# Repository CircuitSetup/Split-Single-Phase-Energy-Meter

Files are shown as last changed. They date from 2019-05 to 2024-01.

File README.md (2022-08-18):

# CircuitSetup Split Single Phase Energy Meter

The CircuitSetup ATM90E32 Split Single Phase Energy Meter can monitor the energy usage in your entire home in real time. It can easily be hooked up to an ESP8266 or ESP32 to wirelessly transmit energy usage data into a program like EmonCMS or ESPHome/Home Assistant. It can also be used to monitor solar power generation to keep track of how much power you are making.

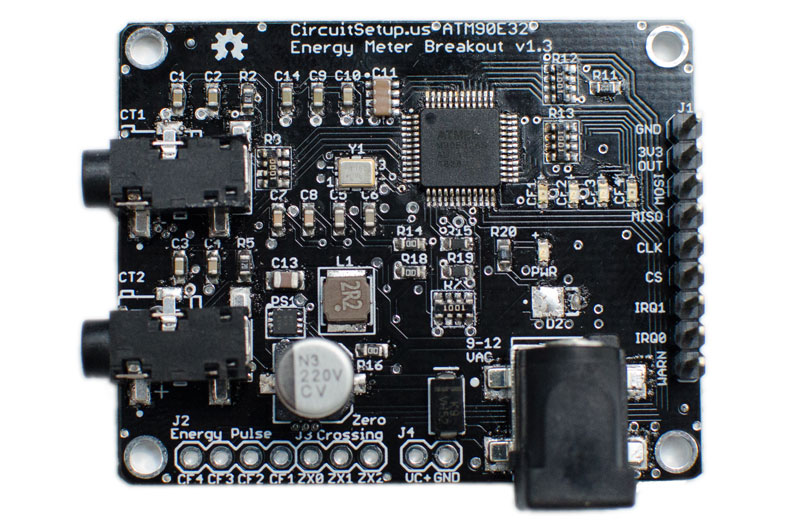
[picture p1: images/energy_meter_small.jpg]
CitcuitSetup Split Single Phase Energy Meter


#### With the Split Single Phase Energy Meter you can:

*   **Save Money!**
    *   See exactly how much money you're spending on energy in real time
    *   Find appliances that are using too much electricity
    *   Calculate energy usage for a single room to divide an energy bill fairly among roommates
*   **View & Gather Energy Data**
    *   View the energy usage of your entire home
    *   Track solar power generation (two units required)
    *   Calculate how much it costs to charge your electric vehicle
    *   Remote energy monitoring for vacation or rental properties
    *   Review and graph historical energy data
*   **Be Informed!**
    *   Independent of your power utility's meter
    *   Set up alerts for over or under usage
    *   Prevent surprises on energy bills
    *   View usage data in the EmonCMS Android or iOS apps
    *   Automate notifications with your home automation system like "send my phone a message when the dryer is done", or even "if I leave the house, and the oven is on, send me an alert" (programming required)
*   **Spend less on energy monitoring hardware!**
    *   Affordable but very accurate
    *   Save hundreds over popular monitoring systems

The Energy Meter kit available on CrowdSupply:
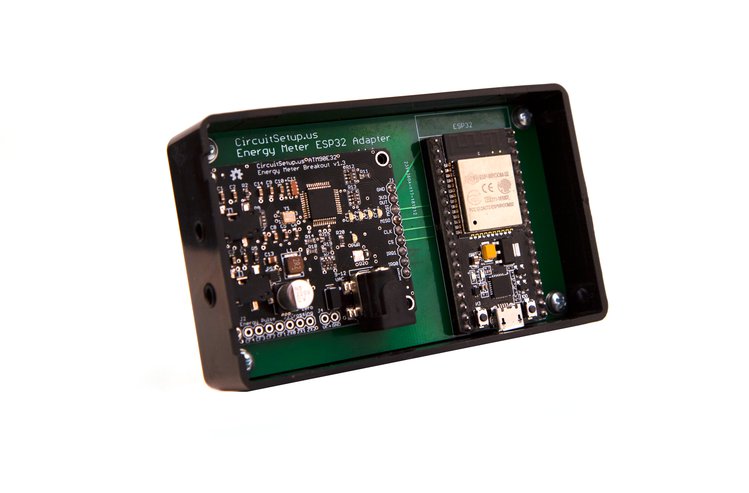
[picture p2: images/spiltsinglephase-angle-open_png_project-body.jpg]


## Contents

<!-- toc -->
- [Features](#features)
- [Software Setup](#software-setup)
- [Hardware Setup](#hardware-setup)
- [Calibration](#calibration)
- [Troubleshooting](#troubleshooting)
<!-- tocstop -->

## Features:

* **IC: MicroChip ATM90E32**
* **Connectivity**
     * SPI Interface to connect to any Arduino compatible MCU
     * Two IRQ interrupts, and one Warning output
     * Energy pulse output (pulses correspond to four LEDs)
     * Zero crossing output
* **Real Time Data Sampling**
     * Two current channels - up to 200A per channel
     * One voltage channel (expandable to two)
     * Measurement Error: 1%
     * Dynamic Range: 6000:1
     * Gain Selection: Up to 4x
     * Voltage Reference Drift Typical (ppm/°C): 6
     * ADC Resolution (bits): 16
* **Calculates**
     * Active Power
     * Reactive Power
     * Apparent Power
     * Power Factor
     * Frequency
     * Temperature
* **Other Features**
     * Can use more than one at a time to measure as many circuits as you want, including solar power generation
     * Uses standard current transformer clamps to sample current
     * Includes built-in 500mA 3v3 buck converter to power MCU board 
     * Compact size at only 40 mm x 50 mm

## What you'll need:

* Current Transformers for wire:
   * **13mm and less**, the [SCT-013-000 100A/50mA](https://circuitsetup.us/index.php/product/100a-50ma-current-transformer-yhdc-sct-013/) has a 13mm opening for wire.
   * **13.5mm - 16mm - 4/0 AWG** (usually aluminum, 200A service) not thicker than 16mm with insulation, we recommend the [YHDC SCT-016 120A/40mA](https://circuitsetup.us/index.php/product/120a-40ma-current-transformer-yhdc-sct-016-with-3-5mm-jack-16mm-opening/). The ones available on CircuitSetup.us, and included with the energy meter kit have 3.5mm plugs. 
   
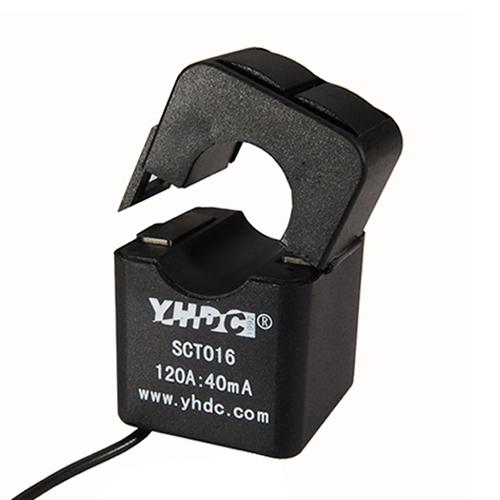
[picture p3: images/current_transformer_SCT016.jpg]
SCT016
   
   
   * **Greater than 16mm**, the [Magnelab SCT-0750-100](https://amzn.to/2IF8xnY) (must sever burden resistor connection on the back of the board since they have a built in burden resistor). These have wire leads and will need an adapter or screw connectors soldered to the energy meter board.
   
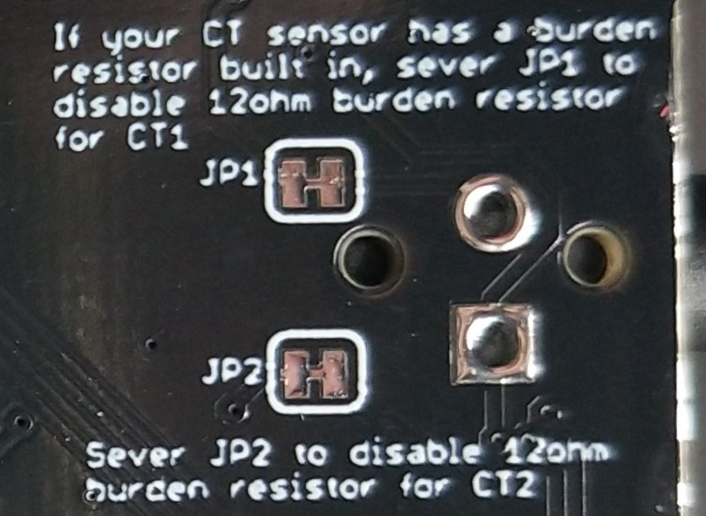
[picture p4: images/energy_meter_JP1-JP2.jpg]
JP1-JP2
   
   
   * Other CTs can also be used as long as they're rated for the amount of power that you are wanting to measure and have a current output no more than 720mA. For safety, they MUST have a built in Zener diode or burden resistor. 
* AC Transformer: [Jameco Reliapro 9v](https://amzn.to/2XcWJjI)
* An [ESP32](https://amzn.to/2pCtTtz), ESP8266, LoRa, or anything else that has an SPI interface.
* Jumper wires with Dupont connectors, or perf board to connect the two boards. The energy meter kit comes with a PCB adapter for an ESP32.
* The software located here to load onto your controller
* [EmonCMS](https://emoncms.org/site/home), ThingSpeak, InfluxDB/Grafana, or similar

## Software Setup

If you purchased an energy meter kit EmonESP is pre-loaded onto the included ESP32. You can skip this section and go to [Setting up EmonCMS](#setting-up-emoncms)

1.  Clone this repository in GitHub desktop or [download all the files and extract them to a folder](https://github.com/CircuitSetup/Split-Single-Phase-Energy-Meter/archive/master.zip)
2.  Place the ATM90E32 folder in your Arduino libraries folder. This is usually under Documents > Arduino > libraries
3.  We highly recommend using [EmonCMS.](https://emoncms.org/site/home) - EmonESP helps to connect and send data directly to EmonCMS
4.  Open **EmonESP > src > src.ino** - you will see several files open, but you'll only need to worry about src.ino
5.  Make sure the **CS_pin** is set to the pin that you are using on your controller board - the defaults are listed in src.ino and in the [hardware section here.](#hardware-setup)
6.  Upload the src.ino to your ESP (If you get any errors at this point, like a missing library, check the [Troubleshooting section on the EmonESP readme.](Software/EmonESP#troubleshooting-upload))
   If you are using an ESP32, [make sure you are using the latest software from the Espressif repository.](https://github.com/espressif/arduino-esp32)
7.  Upload files to the ESP in the data directory via SPIFFS - [see details on how to do this here](https://github.com/CircuitSetup/Split-Single-Phase-Energy-Meter/tree/master/Software/EmonESP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)
8.  Follow the directions to configure the Access Point in the [EmonESP directions](/Software/EmonESP#first-setup)

### Setting up EmonCMS 

EmonCMS

There are a few options for doing this:
- You can use the [EmonCMS.org service](https://emoncms.org/site/home), which costs roughly $15 a year with the data that we send from the energy meter (you don't _have_ to send all of the data)
- [Install on a computer within your network](https://github.com/emoncms/emoncms). To do this, you will need to have [apache/php/mysql installed](https://www.znetlive.com/blog/how-to-install-apache-php-and-mysql-on-windows-10-machine/)) [This can also be done with a Raspberry Pi.](https://github.com/emoncms/emoncms/blob/master/docs/RaspberryPi/readme.md)
- [Install on a remote web server](https://github.com/emoncms/emoncms). There are some very cheap ways this can be done if you're familiar with setting up web applications.

If you install EmonCMS on a remote web server, or if your home network has a public facing port, this will make it possible to see data on the EmonCMS app ([Android](https://play.google.com/store/apps/details?id=org.emoncms.myapps) or [iOS](https://itunes.apple.com/us/app/emoncms/id1169483587?ls=1&mt=8)) when your phone is outside of your network.

For all but the EmonCMS.org service, (currently for EmonCMS.org these feeds and inputs have to be setup manually) you can automatically setup the energy meter device in EmonCMS:
1. [Install the device plugin](https://github.com/emoncms/device) - this is now included in the default configuration
2. [Upload this file to the Modules > device > data > CircuitSetup folder.](/Software/EmonCMS/circuitsetup_split-phase.json)
3. Once the folder is created and json file is uploaded, go to Setup (top left) > Device Setup > New Device (lower right)
4. Click on CircuitSetup in the left menu
   You will see this: 
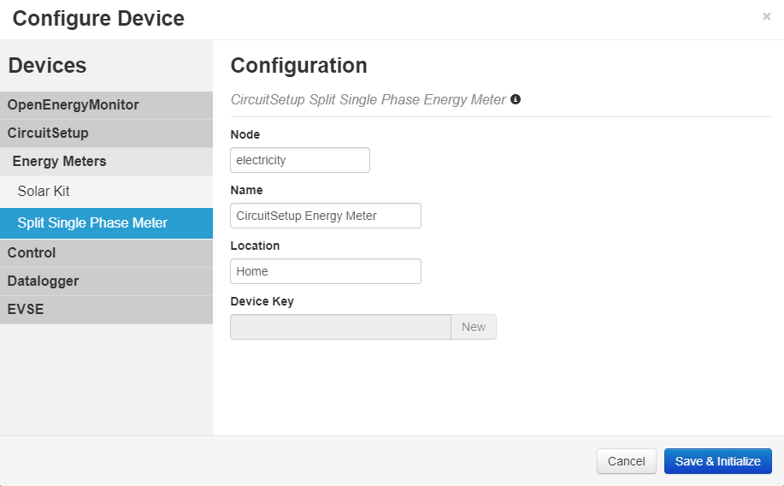
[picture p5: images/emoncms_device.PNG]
EmonCMS Device
   
5. Fill in the Name and Location and click save. 
6. You will then see the fields and inputs - click Initialize:
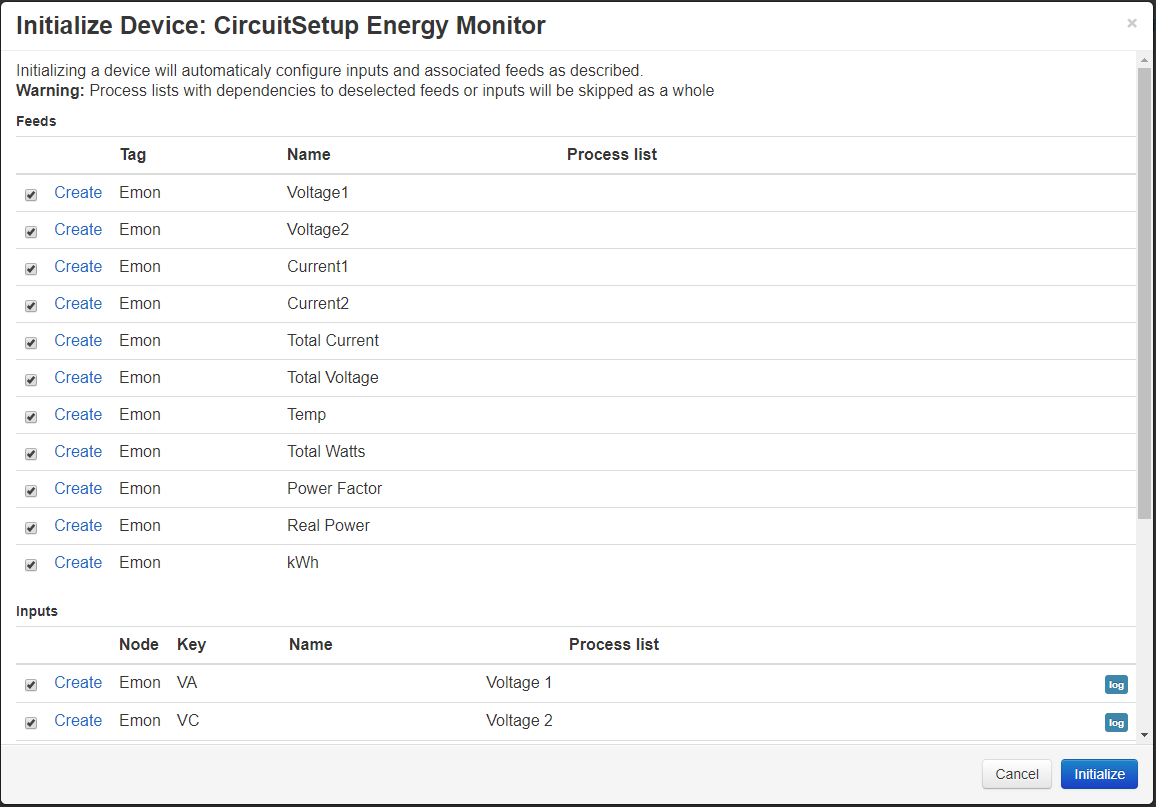
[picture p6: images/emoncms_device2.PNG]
EmonCMS Device2
   
7. You should now see this under Feeds:
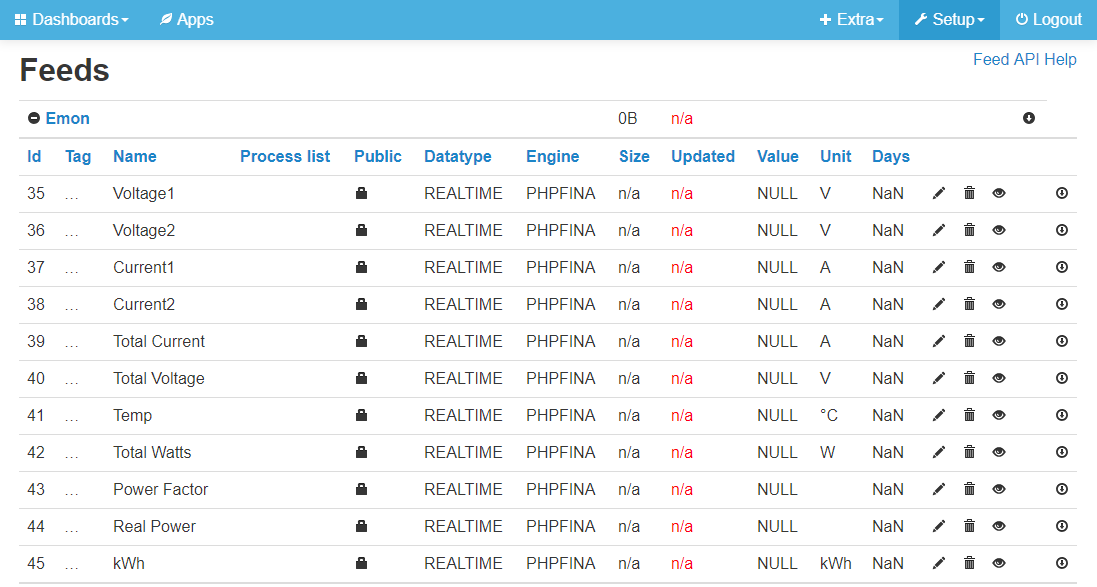
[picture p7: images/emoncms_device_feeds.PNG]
EmonCMS Feeds
   
8. And this under Inputs:
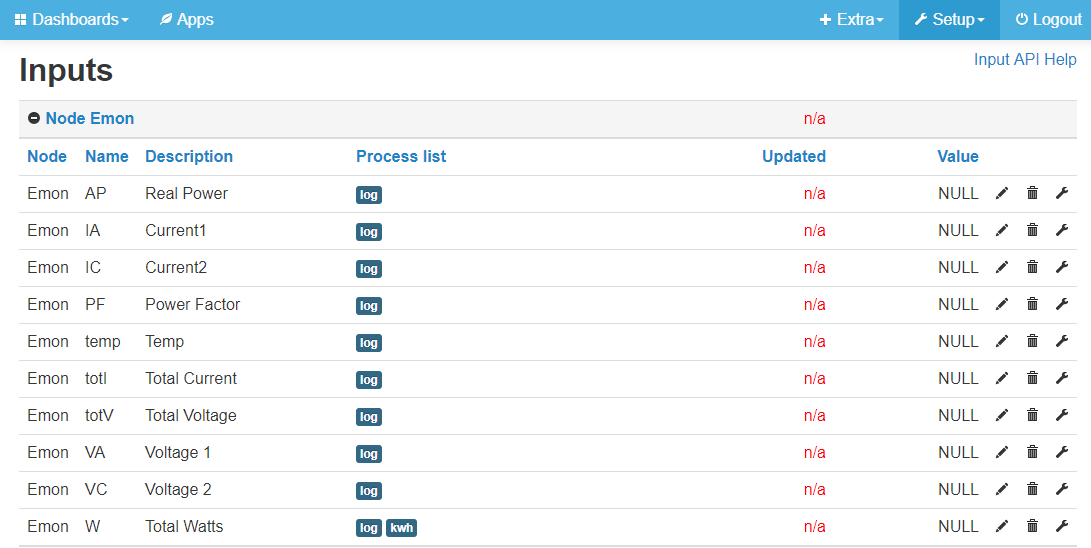
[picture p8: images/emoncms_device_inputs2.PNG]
EmonCMS Inputs
   

### Other software options
If you would like to use something other than EmonCMS, you can do that too! Make sure the ATM90E32 library is included in the sketch. See the [examples folder](https://github.com/CircuitSetup/Split-Single-Phase-Energy-Meter/tree/master/Software/examples) for examples of how things could be done using JSON or MQTT. Users have already setup feeds to Home Assistant, Influxdb, and Graphina. 

ESPHome

Support for this energy meter, and the ATM90E32 is now included in [ESPHome.](https://esphome.io/components/sensor/atm90e32.html)
[See here for more details](https://github.com/CircuitSetup/Expandable-6-Channel-ESP32-Energy-Meter#esphomehome-assistant) on setting up the meter with ESPHome. [Example configurations are located here.](https://github.com/CircuitSetup/Split-Single-Phase-Energy-Meter/tree/master/Software/examples)

## Hardware Setup
If you purchased an energy meter kit you can skip this section and go to [Installing the Energy Meter](#installing-the-energy-meter)

### Connect your controller to the energy meter
Connect the pins on the Energy Monitor to your MCU. If you have the adapter board, everything should already be connected properly. The following are the default for each, but they can be changed in software if you are using these pins for something else. 

For the ESP32:
*   5 - CS
*   18 - CLK
*   19 - MISO
*   23 - MOSI

For the ESP8266:
*   D8/16 - CS
*   D5/14 - CLK
*   D6/12 - MISO
*   D7/13 - MOSI

Don't forget to hook up the 3V3 and GND pins! 

**The energy meter can supply up to 500mA of 3.3v power to your controller**, so no other external power source should be needed. Some ESP32 dev boards may use more than 500mA when trying to initially connect to WiFi. If this is the case, you may not be able to connect to WiFi. If this happens, we recommend using another power source for the ESP32 - either a 5v DC adapter or a USB phone charger that outputs at least 500mA. It is **not** recommended to leave USB power plugged into an ESP at the same time as the energy meter's power 3V3 output. This can damage components. 

Other pins on your controller can be connected to the WARN and IRQ outputs, but they are not yet implemented in the default software. 

### Using more than one meter
More than one meter can be hooked up to a single MCU to monitor a solar grid, for example. 

To do this:
- Connect all CLK, MISO, and MOSI pins together
- Connect the GND and 3V3 from one meter to the MCU
- Connect the CS pin of one energy meter to an open GPIO on your MCU, and the CS pin on the second energy meter to another open GPIO on your MCU. These pins must be set in the software. See the [examples folder](/Software/examples) for the example with more than one energy meter.
- If you would like to monitor voltage from two sources, you will need two AC transformers. If only one voltage, you can split the output of 1 AC transformer using a 2.5mm DC jack Y-cable.

You can also [purchase a solar adapter here](https://circuitsetup.us/index.php/product/energy-meter-solar-esp32-adapter-2x-split-phase-meter-headers-space-for-spi-oled-screen/).

## Installing the Energy Meter
### Warning
To install the current transformers to measure current, your breaker panel must be opened to clamp them around your mains wires.
**High voltage AC power is VERY dangerous! If you are not comfortable working around AC voltage, we strongly encourage you to hire a qualified electrician.**

### **Disclaimer**
**The Split-Single Phase Energy Meter should be installed by a qualified professional, and in compliance with all local electrical codes that apply. CircuitSetup, and its parent company Sugarman Studios, LLC, cannot be held liable for damages or injury incurred by incorrectly installing the Split-Single Phase Energy Meter.**

The Split Single Phase Kit:
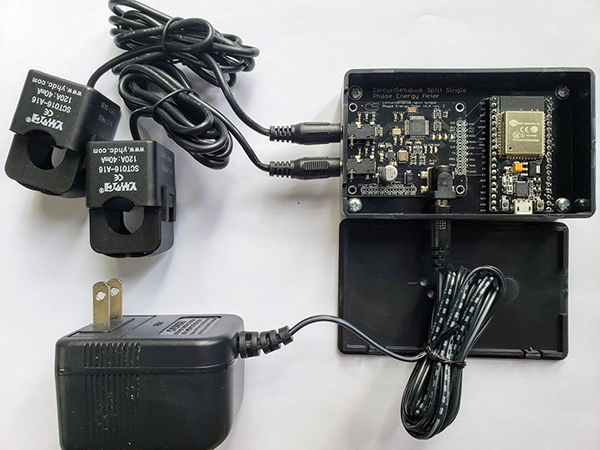
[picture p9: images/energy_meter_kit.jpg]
Energy Meter Kit


1. Decide where to mount the energy meter. We recommend installing the box outside of your panel for a better WiFi signal.  **The current transformer wires will need to be passed through a grommet in the side of the panel** It is against NEC code (US) to not route wires going in or out of an electrical panel through a grommet. 
2. The AC Transformer should be plugged into an outlet close to the panel. If you do not have one close, it is recommended that you have one installed by a licensed electrician. It isn't absolutely necessarty that the outlet is close to the panel, but it will give you more accurate readings. 

### Plug in the AC Transformer
Take note of the side of the split phase that the breaker for the AC transformer is on. This is important for connecting the CTs in the correct direction (see below section)
3. **If you wish to read the voltage from both sides of your panel** :
   - Hook up a second AC transformer to a single pole breaker, or a second outlet, that is wired to the opposite phase of the first AC transformer. If the breaker for the first outlet is on the left of your panel, you will need to wire the second AC transformer or outlet to a breaker on the right of the panel (single split phase breaker panels)
   - Sever jumper JP3 on the back of the energy meter **before hooking up the second AC transformer.** 
   - Solder 2 pin headers, or a female pigtail that matches your second AC transformer plug, to the left of the main AC power plug labeled GND and VC+. 
   - Hook up the second AC transformer to the “GND” (neutral) and “VC+” pins. **You want the wire that is intended to be neutral for the AC transformer to go on the GND terminal of the meter**. This wire usually has a white stripe on it. If the wires are swapped the 2 AC transformers will be in phase, and your current readings will output as negative.
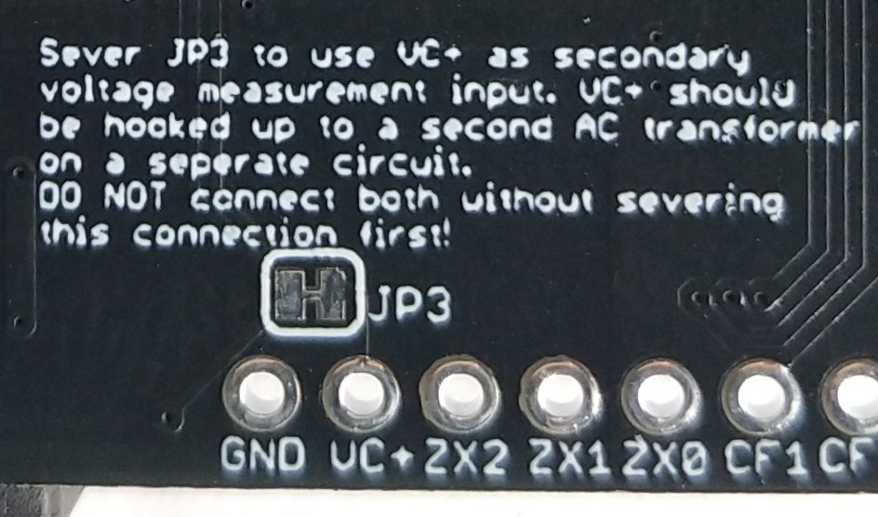
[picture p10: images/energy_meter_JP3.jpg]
JP3


### Connect Current Transformers to the energy meter
Before connecting the current transformers around your mains wires, plug them into the energy meter.

If your current transformers (CTs) have 3.5mm phono connectors, you hopefully have the version of the Energy Meter with these connections (v1.3+ has footprints for both). If you have the screw connectors, the phono connectors will have to be cut off. There should only be two wires regardless. For the screw connector version, be careful to connect the positive to the correct terminal. If these are reversed, things will not be damaged, but the reading will read negative.

If your current transformers have a built-in burden resistor, sever the jumpers on the back of the board to disable the 12ohm burden resistors. Alternatively, if you are reading smaller loads and would like more accurate readings, you can insert your own higher value burden resister across the positive and negative screw terminals.

If you purchased an energy meter kit with the black SCT016 current transformers, or have the blue SCT-013-000, these do not have a built-in burden resistor, but have a TVS diode instead. 

### Connect Current Transformers to your mains
1. Note the direction of the arrows on the top of the current transformers. 
   - If you are measuring 1 voltage (the default configuration): 
      1. CT1 should be on the same side of the split phase as the breaker for the plug that the AC transformer is plugged into, and should point in the direction of the current flowing into your house.
      2. CT2 should point in the opposite direction as CT1. Note: If you are measuring a second voltage with the VC+ input this CT will go in the same direction as the first.
2. Clip the current transformers around the two large main wires, usually at the top of the breaker box. **DO NOT TOUCH BARE METAL ON THESE WIRES**. There is one current transformer for each phase. 
3. Make sure the current transformers are not in the way of anything else, and are snapped closed around the wires. **Do not force them shut – if they will not close you will need a larger current transformer**

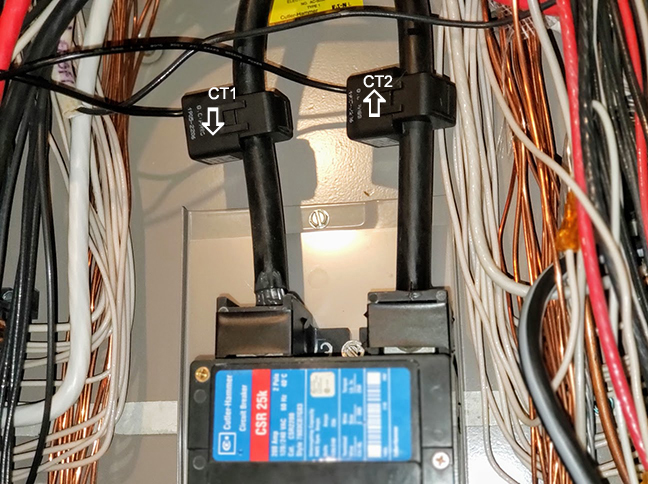
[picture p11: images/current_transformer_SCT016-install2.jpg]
SCT016 Install


### Solar Kit Setup ###
The solar kit comes with 2 meters, 4 current transformers, and optionally, 2 AC transformers.

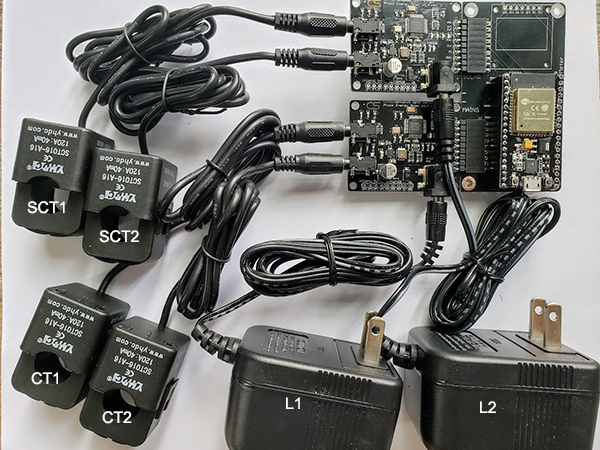
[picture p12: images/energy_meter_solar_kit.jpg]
Solar Kit


#### AC Transformers
**The 1st AC transformer**, L1, should be plugged into an outlet the same way as noted above in the "Plug in the AC Transformer" section

**The 2nd AC transformer**, L2, for the solar kit should be plugged into an outlet that is on the opposite phase than the first AC transformer. If you do not have an outlet, we recommend having a licensed electrician install one.

It is possible to power both energy meters with one AC transformer, you will just need a Y splitter. Close attention needs to be paid to the direction of the current transformers to properly measure the direction current is flowing.

#### Current Transformers
The mains current transformers (CT1, CT2) should be connected the same way as noted above starting with section "Connect Current Transformers to the energy meter"

Current transformers to measure solar energy generation (SCT1, SCT2) should be connected to the wires coming into your panel from your solar inverter. This is usually a dual pole breaker with 2 hot wires (in the US). The arrows on the CTs should be opposite eachother, like with the mains CTs. The wire that is connected to the side of the panel that is the same as the solar AC transformer will point towards the panel. It may take some trial an error to get this correct. 

Energy generated by solar, but not used by your house will register on the mains CTs as negative, since energy is flowing back to the grid. In EmonCMS this calculation is done automatically assuming you have set up the "Solar Kit" device.

## Calibration

If you purchased a kit that came with current transformers **and** an AC Transformer, you should not have to calibrate anything unless you want to. If you are providing your own AC Transformer, you will need to calibrate the voltage.

The default configuration of the Energy Meter software is set to use the SCT-016 120A/40mA current transformers, and the [Jameco Reliapro 9v AC transformer](https://amzn.to/2XcWJjI). There are also values for 100A Magnalab, SCT-013 100A 50mV current transformers, and the 12v version of the AC transformer located in the **energy_meter.h** file, and in the EmonESP web interface. Simply change the values under CALIBRATION SETTINGS if you are using a 12v AC Transformer or the Magnalab current transformers.  **If you are using any of these you likely will not need to calibrate, but if you want to be sure your readings are the most accurate then calibration is recommended.** 

Alternatively, if you have equipment that can read active and reactive energy pulse outputs, CT1-CT4 pins can be used for this. It is recommended that these connections are opto-isolated to prevent interference. 

### For calibration you will need:
1.  A multi-meter, or to make it easier and safer, a [kill-a-watt](https://amzn.to/2TXT7jx) or similar. A clamp meter will also work if you would like to measure mains power directly.
2.  A hair dryer, soldering iron, electric heater, or anything else that uses a large amount of resistive current.
3.  A modified power cable that allows you to put a current transformer around only the hot (usually black) wire.

### Setup
1.  At this point all wires should be connected between your ESP and the Energy Monitor.
2.  Connect the Energy Monitor to the AC Transformer and plug it in - the ESP and Energy Meter should both have power. If either do not, check your connections.

#### With the Arduino IDE
1.  Open the Arduino IDE
2.  Connect your ESP to your computer via USB cable
3.  Select the COM port under Tools > Port
4.  Go to Tools > Serial Monitor
5.  Values should be scrolling by. If you do not see anything in the serial window, make sure the correct COM port is selected for your ESP in the Arduino IDE.

#### With EmonESP
1.  The first time the ESP32 or ESP8266 is started with EmonESP, it will not be connected to a local router, and will go into SoftAP mode. You can connect to the interface via a cell phone or other wireless device to access the interface via a web browser at 192.168.4.1 or emonesp.local. For more details on this see [EmonESP WiFi Connection](/Software/EmonESP#1-wifi-connection)
2.  If the ESP is already connected to a network, you can access the interface with the IP address that your router assigned to it.
3.  Go to the Calibration section:

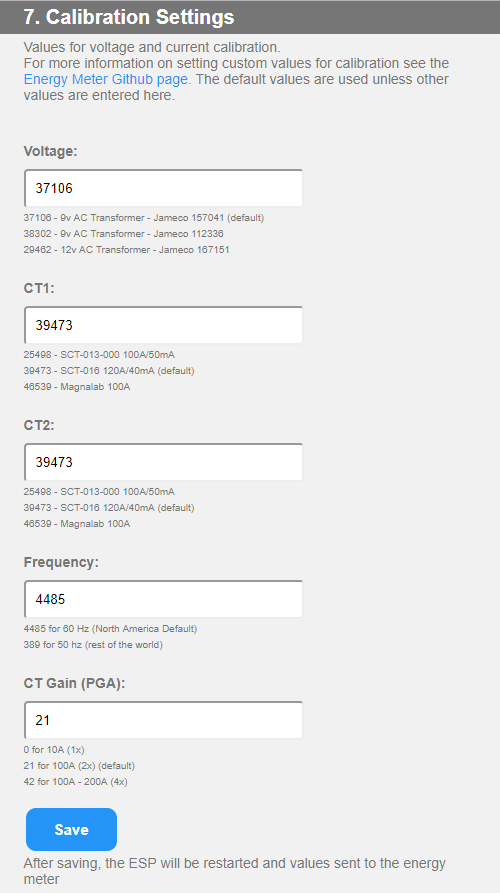
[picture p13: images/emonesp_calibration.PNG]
EmonESP Cal


### Voltage Procedure 

1.  In the Serial Monitor window or in EmonESP under 4. Latest Data, view the value for Voltage - take note of this (if you are getting a value above 65k, something is not hooked up or working correctly)
2.  Take a reading of the actual voltage from an outlet in your house.  For the Kill-a-watt, just plug it in, and select voltage. Compare the values.
3.  Adjust the value for VoltageGain in energy_meter.h or EmonESP by calculating:

<pre>New VoltageGain = (your voltage reading / energy monitor voltage reading) * VOLTAGE_GAIN</pre>

VOLTAGE_GAIN is the value currently set for the voltage gain parameter in energy_meter.h.

Test again after adjusting the value and re-uploading the sketch to your ESP. If it is still off, do the procedure again, but replace VOLTAGE_GAIN with the last value used. 

If you are not located in the US and have 50hz power, change the Frequency value to 389

### Current Procedure
For calibrating **CurrentGainCT1 & CurrentGainCT2**:

1.  In the Serial Monitor window or in EmonESP under 4. Latest Data, view the value for Current 
2.  If the value is negative, you are either exporting power (solar), or the current transformer is backwards.
3.  Compare what you are seeing for current from the Energy Monitor to the reading on the Kill-a-watt
4.  Adjust the value for CurrentGainCT1 or CurrentGainCT2 in energy_meter.h or EmonESP by calculating:

<pre>New CurrentGainCT1 or CurrentGainCT2 = (your current reading / energy monitor current reading) * CURRENT_GAIN_CT#</pre>

CURRENT_GAIN_CT# is the value currently set for the current gain parameter in energy_meter.h.

Test again after adjusting the value and re-uploading the sketch to your ESP. If it is still off, do this again, but replace the CURRENT_GAIN_CT# with the last value used. It is possible that the two identical current sensors will have different CurrentGain numbers due to variances in manufacturing, but it shouldn't be drastic. Note that the positioning of the CT sensor on the hot wire can influence the current reading. 

For more details, see the Calibration Procedure in the [Microchip Application notes.](http://ww1.microchip.com/downloads/en/AppNotes/Atmel-46103-SE-M90E32AS-ApplicationNote.pdf)

## Troubleshooting
### I'm not getting any data from the energy meter
If you have an energy meter kit:
- **Check that the ESP32 is seated properly.** Take it all the way out, then back in again to make sure. It should click into place. If you find you're only getting a signal when holding down the ESP32, you can try removing the black plastic around the base of the pins of the esp32, to push it down further. This is best accomplished with flush cutters. If you rather not do that, please contact us.
- If you're getting all 0 readings from the meter, try the steps above. If that does not work, please contact us.

If you do not have a kit:
- If you are getting all 65535 readings from the meter, then the connection from the ESP32 to the meter is not correct. Please check your wires.

### I'm getting a very low power factor reading, and wattage seems off
One of your CT clamps is probably backwards - flip it around. If they are both oriented in the same direction, this will not happen. 

### The ESP32 doesn't stay connected to WiFi
Make sure that the ESP32 has a good WiFi signal. The RSSI (viewable in the EmonESP web interface) should be, at the least, -70db.

For the CircuitSetup version of EmonESP:
- If the ESP32 loses the connection to the configured access point it will try 3 times over a 30 second period to reconnect. 
- If it cannot reconnect, it will go into SoftAP mode and broadcast a signal so it can be reconfigured via the web interface, if necessary. 
- If nothing happens after 5 minutes, it will try to reconnect to the configured access point again. 

### The ESP32 with CitcuitSetup EmonESP freezes and the blue LED does not blink
See the steps above for staying connected to WiFi. If that does not work, try one of the following:
1. Load [the latest firmware via the EmonESP web interface](https://github.com/CircuitSetup/Split-Single-Phase-Energy-Meter/releases). 
   - Download the latest .bin file from the link above
   - Open http://EmonESP_IP/upload (6. Firmware)
   - Click "Choose File", select the .bin file, then "Update Firmware"
   - The file will upload to the ESP32, and it will reset
   - After about 20 seconds the upload page will reload - you can return to the main page to verify everything is working properly
   
2. Close the browser window open to the EmonESP interface. There was a bug, that has since been corrected in v2.5.3, that would cause the ESP32 to freeze if a browser window was left open. It may also not close a browser session, which caused a memory leak, and eventual freeze.
3. Use an AC Transformer with a higher current output, like the [Jameco 112336](https://www.jameco.com/z/ADU090150A2231-AC-to-AC-Wall-Adapter-Transformer-9-Volt-1500mA-Black-Straight-2-5mm-Female-Plug_112336.html). The voltage calibration procedure will need to be done.
4. If the power being read is especially noisy, the energy meter IC and on-board low pass filters are pretty good at filtering, but sometimes this can cause the ESP32 to freeze. To remedy, bypass the on-board power supply:
   - If you have a hot air soldering gun:
      1. Remove the rectifier diode next to the power jack
      2. Use a USB style AC/DC adapter or phone charger to power the ESP32 via the micro-USB jack
      3. Use the AC transformer as you did previously
   - If you only have a regular soldering iron:
      1. Only the voltage 2 channel will be used in this method, so a modification to account for this in software will have to be done
      2. Solder a header on to "VC+" and "GND" next to the power jack
      3. Sever the JP3 connection on the back of the board
      4. Crimp or solder on a header that matches the one soldered onto the board in step 1 - **be careful to not reverse the polarity!**
      5. Use a USB style AC/DC adapter or phone charger to power the ESP32 via the micro-USB jack
      
### How do I change the network AP the ESP32 is connected to with EmonESP? 
1. Turn off the router that the ESP32 is configured on, and the meter/ESP32
2. Turn on the meter/ESP32
3. The ESP32 will go into soft AP mode after 30 seconds of not being able to connect to the configured AP. You can confirm this by checking the blue led. It will blink once every 2 seconds.
4. Connect to the ESP32 like you did when you first configured EmonESP. From there you can set it to connect to the new network AP.

### How do I reset the login/password to the EmonESP admin page?
To do this you'll have to reset EmonESP to default. This will erase any saved settings, like wifi configuration and connections.

1. Remove the ESP32 off of the pcb
2. Power the ESP32 via USB (If you want, open a serial window to see what it's outputting)
3. Connect Gnd (upper left) with GPIO3 (5th pin from upper left) with a jumper wire
4. Wait 15 seconds (10 minimum, but 15 to be sure). If you have a serial window open, it'll say "factory reset"
## Licenses
Hardware license: CERN v 1.2

Documentation license: CC BY 4.0

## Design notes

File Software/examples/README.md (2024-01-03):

## Examples ##
This example software was created by us and the community to use the CircuitSetup Split Single Phase Energy Meter in different applications.

### Sketches ###
- **ATM90E32_Basic_SPI** is a Basic Arduino sketch - this is a basic example that shows how to use the ATM90E32 library in Arduino. It simply outputs values to the serial window. The basis for this was created by [Tisham Dhar for his ATM90E26 Featherwing meter.](https://github.com/whatnick/ATM90E26_Arduino/tree/master/examples)
- **ATM90E32_MQTT** - an Arduino sketch using MQTT to send energy meter data via a Wemos D1. [Created by digiblur](https://github.com/digiblur/digiNRG_SplitPhase)
- **Home_Assistant_MQTT** - an Arduino sketch to send data to Home Assistant using MQTT. Includes the Home Assistant sensor file. Thanks to Richard Talley for supplying this.
- [**Raspberry Pi + MongoDB**](https://github.com/BitKnitting/FitHome/wiki/ElectricityMonitor) - Using a Raspberry Pi to communicate with the energy meter and send energy data to MongoDB
- [**MySQL to Home Assistant**](https://community.home-assistant.io/t/how-to-save-sensor-data-to-mysql-database/163094/6?u=circuitsetup) - Send data to a MySQL database via Arduino Ethernet, then read the database in Home Assistant. By Aaron Cake

### ATM90E32 Libraries ###
- **[CircuitPython](https://github.com/BitKnitting/CircuitSetup_CircuitPython)** - The ATM90E32 library converted to work with Adafruit's CircuitPython. Created by BitKnitting
- **[MicroPython](https://github.com/BitKnitting/CircuitSetup_micropython)** - The ATM90E32 library converted to work with MicroPython. Created by BitKnitting
- **[ESPHome](https://github.com/esphome/esphome/tree/dev)** - direct integration for ESPHome, which allows you to more easily import energy data directly into home automation systems like Home Assistant. Created by thompsa. [Some more details on setting up the meter with ESPHome](https://github.com/digiblur/digiNRG_ESPHome), by digiblur
  - **HA-ESPHome_energy_meter.yaml** - ESPHome setup config.  The default calibration values have been loaded (9V AC Transformer, 120A/40mA CTs) [Created by digiblur](https://github.com/digiblur/digiNRG_ESPHome)
  - **[ESPHome Documentation](https://esphome.io/components/sensor/atm90e32.html)** for the ATM90E32 sensor

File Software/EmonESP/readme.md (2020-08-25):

# EmonESP



ESP8266/ESP32 WIFI serial to emoncms link

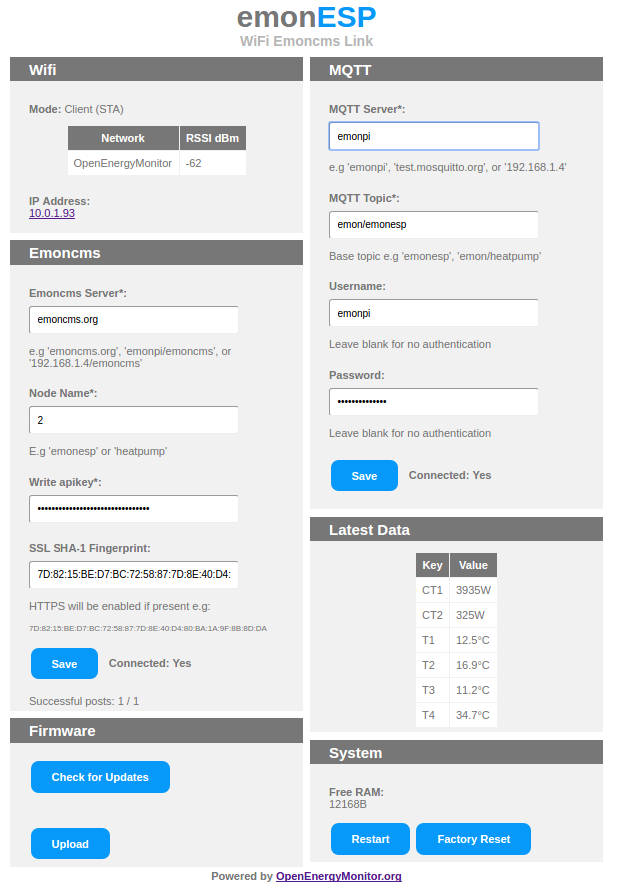
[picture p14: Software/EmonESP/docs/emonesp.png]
EmonEsp WiFi AP Setup Portal


## Contents

<!-- toc -->
- [EmonESP](#emonesp)
  * [Requirements](#requirements)
- [EmonESP User Guide](#emonesp-user-guide)
  * [First Setup](#first-setup)
    + [1. WiFi Connection](#1-wifi-connection)
  * [2. Emoncms](#2-emoncms)
  * [3. MQTT](#3-mqtt)
  * [5. Admin (Authentication)](#5-admin-authentication)
  * [7. System](#7-system)
  * [OTA Firmware Update](#ota-firmware-update)
  * [HTTP API Examples](#http-api-examples)
    + [View units status:](#view-units-status)
    + [4. Data Input](#4-data-input)
      - [UART Input](#uart-input)
      - [HTTP API](#http-api)
    + [Save Emoncms server details](#save-emoncms-server-details)
    + [Save Emoncms MQTT server details](#save-emoncms-mqtt-server-details)
  * [Installation](#installation)
    + [Option 1: Using PlatformIO](#option-1-using-platformio)
      - [1a. Install PlatformIO command line](#1a-install-platformio-command-line)
      - [1b. And / Or use PlatformIO IDE](#1b-and--or-use-platformio-ide)
      - [2. Clone this repo](#2-clone-this-repo)
      - [3. Compile](#3-compile)
      - [3. Upload](#3-upload)
        * [a.) Upload main program:](#a-upload-main-program)
        * [b.) Upload data folder to the file system (html, CSS etc.) (SPIFFS):](#b-upload-data-folder-to-the-file-system-html-css-etc-spiffs)
      - [Or upload all in one go](#or-upload-all-in-one-go)
        * [c.) OTA upload over local network](#c-ota-upload-over-local-network)
      - [4. Debugging ESP subsystems](#4-debugging-esp-subsystems)
    + [Option 2: Using Arduino IDE](#option-2-using-arduino-ide)
      - [1. Install ESP for Arduino IDE with Boards Manager](#1-install-esp-for-arduino-ide-with-boards-manager)
      - [2. Install ESP filesystem file uploader](#2-install-esp-filesystem-file-uploader)
      - [3. Clone this repo](#3-clone-this-repo)
      - [4. Compile and Upload](#4-compile-and-upload)
    + [Troubleshooting Upload](#troubleshooting-upload)
      - [Erase Flash](#erase-flash)
      - [Fully erase ESP-12E](#fully-erase-esp-12e)
    + [Development Forum Threads](#development-forum-threads)
    + [License](#license)

<!-- tocstop -->

# Requirements

- ESP-12E module with 4M Flash
OR
- ESP8266
OR
- ESP32

***

# User Guide

## First Setup

On first boot, the ESP should broadcast a WiFI AP `emonESP_XXX`. Open a browser and navigate to `http://192.168.4.1`

*Note: You may need to disable mobile data if connecting via a Android 6 device*

### 1. WiFi Connection

- Select your WiFi network from list of available networks
- Enter WiFi PSK key then click `Connect`

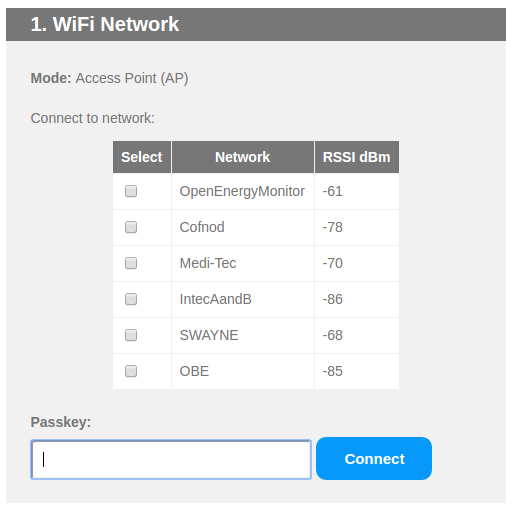
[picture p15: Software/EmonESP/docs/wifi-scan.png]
Wifi setup


- emonESP should now connect to local wifi network and return local IP address.
- Browse to local IP address by clicking the hyperlink (assuming your computer is on the same WiFi network)
On future boots EmonESP will automatically connect to this network.

*Note: on some networks it's possible to browse to the EmonESP using hostname [http://emonesp](http://emonesp) or on windows [http://emonesp.local](http://emonesp.local)*

**If re-connection fails (e.g. network cannot be found) the EmonESP will automatically revert back to WiFi AP mode after a short while to allow a new network to be re-configued if required. Re-connection to existing network will be attempted every 5min.**

*Holding the `boot` button at startup (for about 10's) will force AP mode. This is useful when trying to connect the unit to a new WiFi network.*

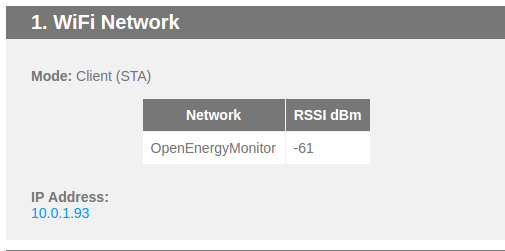
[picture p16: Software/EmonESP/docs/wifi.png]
Wifi setup


## 2. EmonCMS

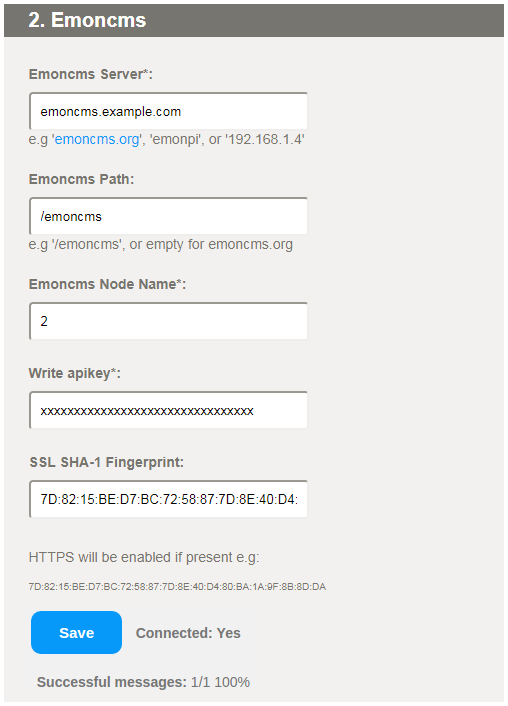
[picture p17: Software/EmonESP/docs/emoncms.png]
emoncms setup


EmonESP can post data to [emoncms.org](https://emoncms.org) or any other Emoncms server (e.g. emonPi) using [Emoncms API](https://emoncms.org/site/api#input).

Instructions on setting up [EmonCMS on a Raspberry Pi are located here.](https://github.com/openenergymonitor/EmonScripts/blob/master/install/rpi-install.md)

In the *Emoncms Server* field, enter just the hostname or address without any path (e.g. emoncms.org), in the *Emoncms Path* field enter the path including the leading slash (e.g. /emoncms) or leave it empty if not required.

Data can be posted using HTTP or HTTPS. For HTTPS the Emoncms server must support HTTPS (emoncms.org does, emonPi does not). Due to the limited resources on the ESP the SSL SHA-1 fingerprint for the Emoncms server certificate must be manually entered and regularly updated.

*Note: the emoncms.org fingerprint will change every 90 days when the SSL certificate is renewed.*

To obtain the certificate fingerprint, you can use several methods, some examples:
* Chrome under Windows: click the secure icon next to the address bar and click on the certificate row to get the details, in the *Details* tab copy the hexadecimal digits from the box *Thumbprint* substituting spaces with colons and paying attention not to include any leading invisible character;
* Firefox under Linux: click the secure icon next to the address bar, Show connection details, More information, in the security tab click *View Certificate* and copy the *SHA1 Fingerprint*
* openssl under Linux: issue the following command substituting your host in place of www.example.com:

`echo | openssl s_client -connect www.example.com:443 -servername www.example.com |& openssl x509 -fingerprint -sha1 -noout`

## 3. MQTT

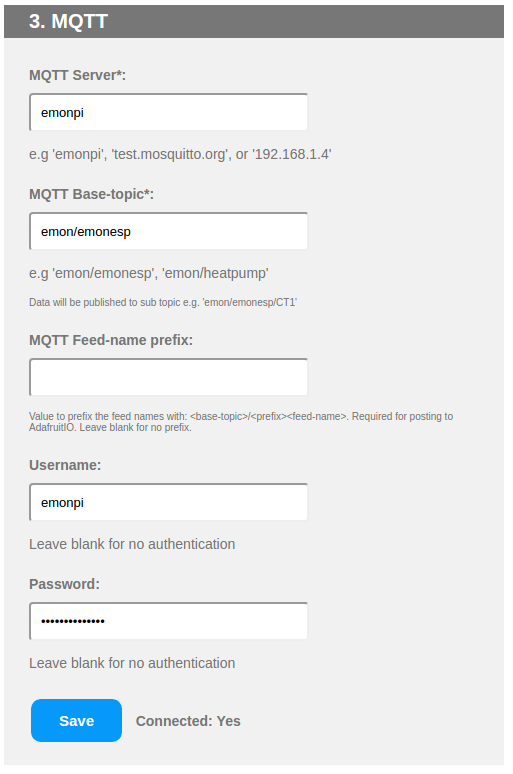
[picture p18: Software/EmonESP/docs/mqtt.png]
mqtt setup


EmonESP can post data to an MQTT server. Each data key:pair value will be published to a sub-topic of base topic.E.g data `CT1:346` will results in `346` being published to `<base-topic>/CT1`

- Enter MQTT server host and base-topic
- (Optional) Enter server authentication details if required
- Click connect
- After a few seconds `Connected: No` should change to `Connected: Yes` if connection is successful. Re-connection will be attempted every 10s.

*Note: `emon/xxxx` should be used as the base-topic if posting to emonPi MQTT server if you want the data to appear in emonPi Emoncms. See [emonPi MQTT docs](https://guide.openenergymonitor.org/technical/mqtt/).*

## 5. Admin (Authentication)

HTTP Authentication (highly recomended) can be enabled by saving admin config by default username and password

**HTTP authentication is required for all HTTP requests including input API**

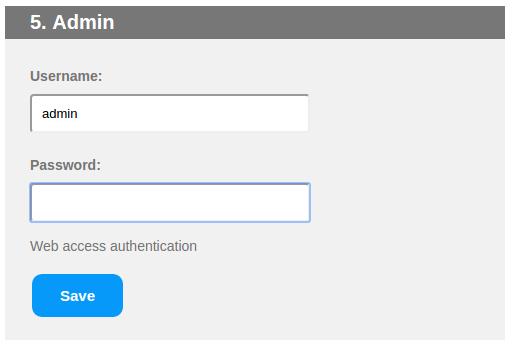
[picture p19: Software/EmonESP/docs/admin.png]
admin setup


## 7. System

Displays free system memory and firmware version

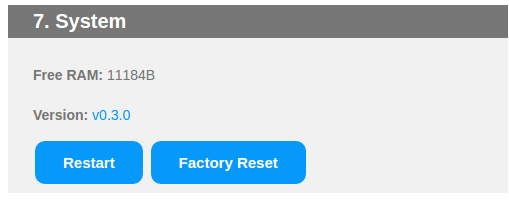
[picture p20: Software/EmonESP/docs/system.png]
system


## OTA Firmware Update

TBC

## HTTP API Examples

### View units status:

`http://<IP-ADDRESS>/status`

Example return in JSON:

```
{"mode":"STA","networks":[],"rssi":[],"ssid":"OpenEnergyMonitor","srssi":"-58","ipaddress":"10.0.1.93","emoncms_server":"emoncms.org","emoncms_node":"emonesp","emoncms_apikey":"xxxxxxxx","emoncms_connected":"0","packets_sent":"0","packets_success":"0","mqtt_server":"emonpi","mqtt_topic":"emonesp","mqtt_user":"emonpi","mqtt_pass":"xxxxxx","mqtt_connected":"0","free_heap":"25040"}
```

### 4. Data Input

Data can be inputed to EmonESP via serial UART or HTTP API.

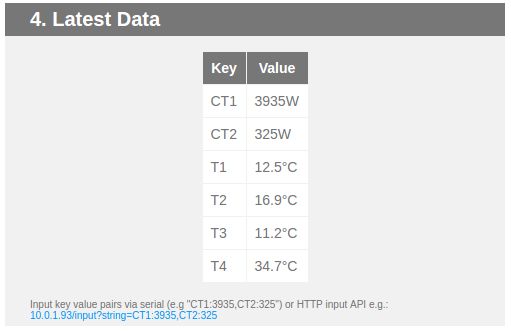
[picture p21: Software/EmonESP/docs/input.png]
input setup


#### UART Input

Data in serial:pairs string format can be inputed to EmonESP via serial UART **(115200 baud)** e.g:

`ct1:3935,ct2:325,t1:12.5,t2:16.9,t3:11.2,t4:34.7`

#### HTTP API

Data in string:pairs can be sent to EmonESP via HTTP API. This is useful to emulate the serial string data function while using the UART for code upload and debug. API example:

`http://<IP-ADDRESS>/input?string=ct1:3935,ct2:325,t1:12.5,t2:16.9,t3:11.2,t4:34.7`

### Save Emoncms server details

`http://<IP-ADDRESS>/saveemoncms?&server=emoncms.org&apikey=xxxxxxxxxxxxxxxxxx&node=emonesp&fingerprint=7D:82:15:BE:D7:BC:72:58:87:7D:8E:40:D4:80:BA:1A:9F:8B:8D:DA`

*SSL SHA-1 fingerprint is optional, HTTPS connection will be enabled if present*

### Save Emoncms MQTT server details

`http://<IP-ADDRESS>/savemqtt?&server=emonpi&topic=emonesp&user=emonpi&pass=emonpimqtt2016`

*MQTT user and pass are optional, leave blank for connection to un-authenticated MQTT servers*

***

## Installation 

EmonESP uses [ESP8266 Arduino core](https://github.com/esp8266/Arduino) or the [ESP32 Arduino core](https://github.com/espressif/arduino-esp32)

Firmware can be compiled and uploaded either using PlatfomIO ([see blog post](https://blog.openenergymonitor.org/2016/06/platformio/)) or Arduino IDE.

### Option 1: Using PlatformIO

For more detailed ESP8266 Arduino core specific PlatfomIO notes see: https://github.com/esp8266/Arduino#using-platformio

#### 1a. Install PlatformIO command line

The easiest way if running Linux is to install use the install script, this installed pio via python pip and installs pip if not present. See [PlatformIO installation docs](http://docs.platformio.org/en/latest/installation.html#installer-script). Or PlatformIO IDE can be used :

`$ sudo python -c "$(curl -fsSL https://raw.githubusercontent.com/platformio/platformio/master/scripts/get-platformio.py)"`

#### 1b. And / Or use PlatformIO IDE

Standalone built on GitHub Atom IDE, or use PlatformIO Atom IDE plug-in if you already have Atom installed. The IDE is nice, easy and self-explanitory.

[Download PlatfomIO IDE](http://platformio.org/platformio-ide)

#### 2. Clone this repo

`$ git clone https://github.com/CircuitSetup/Split-Single-Phase-Energy-Meter`

#### 3. Compile

```
$ cd Software/EmonESP
$ pio run
```

The first time platformIO is ran the espressif arduino tool chain and all the required libs will be installed if required.

#### 3. Upload

- Put ESP into bootloader mode
   - On Heatpump monitor use jumper to pull `GPIO0` low then reset then connect power (simulates reset) or pull RST pin low.
   - On other ESP boards (Adafruit HUZZAH) press and hold `GPIO0` button then press Reset, LED should light dimly to indicate bootloader mode

##### a.) Upload main program:

`$ pio run -t upload`

##### b.) Upload data folder to the file system (html, CSS etc.) (SPIFFS):

- Put ESP back into bootloder mode, see above

`$ pio run -t uploadfs`

See [PlatfomrIO docs regarding SPIFFS uploading](http://docs.platformio.org/en/latest/platforms/espressif.html#uploading-files-to-file-system-spiffs)

#### Or upload all in one go

This wil upload both the fimware and fs in a single command

Put ESP into bootloader mode

`esptool.py write_flash 0x10000 .pioenvs/emonesp/firmware.bin 0x290000 .pioenvs/emonesp/spiffs.bin`

##### c.) OTA upload over local network

`$  pio run  -t upload --upload-port <LOCAL-ESP-IP-ADDRESS>`

Upload SPIFFS filesystem over OTA (and don't flash):

` pio run -e emonesp_spiffs -t upload --upload-port <LOCAL-ESP-IP-ADDRESS>`

OTA uses port 8266. See [PlatformIO ESP OTA docs](http://docs.platformio.org/en/latest/platforms/espressif.html#over-the-air-ota-update):

#### 4. Debugging ESP subsystems

The ESP subsystems have a lot of logging that can be enabled via setting various build options.

Using Platform IO the easiest way to configure these is via the [PLATFORMIO_BUILD_FLAGS](http://docs.platformio.org/en/stable/envvars.html#envvar-PLATFORMIO_BUILD_FLAGS) environment variable.

First select the serial port to output debug;
```
-DDEBUG_ESP_PORT=Serial
-DDEBUG_ESP_PORT=Serial1
```

Then add one or more of the debug options;
```
-DDEBUG_ESP_CORE
-DDEBUG_ESP_WIFI
-DDEBUG_ESP_HTTP_CLIENT
-DDEBUG_ESP_HTTP_SERVER
-DDEBUG_ESP_HTTP_UPDATE
-DDEBUG_ESP_UPDATER
-DDEBUG_ESP_OTA
-DDEBUG_ESP_SSL
-DDEBUG_TLS_MEM
```

For example from the Windows Power shell you may do something like;
```
$env:PLATFORMIO_BUILD_FLAGS="-DDEBUG_ESP_PORT=Serial1 -DDEBUG_ESP_CORE -DDEBUG_ESP_WIFI"
pio run -t clean
pio run
pio run -t upload --upload-port 172.16.0.80
```
***

### Option 2: Using Arduino IDE

#### 1. Install ESP for Arduino IDE with Boards Manager

##### a. For ESP8266:

Install steps from: https://github.com/esp8266/Arduino

- Install Arduino IDE 1.6.8 from the Arduino website.
- Start Arduino and open Preferences window.
- At the bottom of this window find the field “Additional Board Manager URLs” and enter ‘http://arduino.esp8266.com/stable/package_esp8266com_index.json`. You can add multiple URLs, separating them with commas.
- Open `Tools > Board > Board Manager`, scroll down and click on esp8266 platform, select version then install
- Select `Tools > Board > Generic ESP8266 Module` (required for EmonESP)

##### b. For ESP32:

Install steps from: https://github.com/espressif/arduino-esp32/blob/master/docs/arduino-ide/boards_manager.md

- Install the current upstream Arduino IDE at the 1.8 level or later. The current version is at the [Arduino website](http://www.arduino.cc/en/main/software).
- Start Arduino and open Preferences window.
- Enter ```https://dl.espressif.com/dl/package_esp32_index.json``` into *Additional Board Manager URLs* field. You can add multiple URLs, separating them with commas.
- Open Boards Manager from Tools > Board menu and install *esp32* platform (and don't forget to select your ESP32 board from Tools > Board menu after installation).

Stable release link: `https://dl.espressif.com/dl/package_esp32_index.json`

Development release link: `https://dl.espressif.com/dl/package_esp32_dev_index.json`

#### 2. Install ESP filesystem file uploader

##### a. For ESP8266:

Required to include `data` folder with HTML etc in the upload

[Follow esp8266 filesystem instructions (copied  below):](https://github.com/esp8266/Arduino/blob/master/doc/filesystem.md)

- [Download the Arduino IDE plug-in (.zip)](https://github.com/esp8266/arduino-esp8266fs-plugin/releases/download/0.2.0/ESP8266FS-0.2.0.zip)
- Navigate to the `tools` folder in your Arduino sketchbook directory, (create directory if it doesn't exist)
- Create `tools > ESP8266FS` folder
- Unpack the plug-in into `ESP8266FS` directory (the path will look like `<home_dir>/Arduino/tools/ESP8266FS/tool/esp8266fs.jar`)
- Restart Arduino IDE

##### a. For ESP32:

You will need the latest release from this page: https://github.com/me-no-dev/arduino-esp32fs-plugin/releases

Then follow instructions from here: https://github.com/me-no-dev/arduino-esp32fs-plugin

- In your Arduino sketchbook directory, create tools directory if it doesn't exist yet.
- Unpack the tool into tools directory (the path will look like ```<home_dir>/Arduino/tools/ESP32FS/tool/esp32fs.jar```).
- Restart Arduino IDE. 

#### 3. Clone this repo

`$ git clone https://github.com/CircuitSetup/Split-Single-Phase-Energy-Meter`

#### 4. Compile and Upload

- Open Software/EmonESP/src/src.ino in the Arduino IDE.
- Connect the ESP to an open USB port on your computer
- Select the appropriate port and options under tools
- **Upload main sketch:** Compile and Upload as normal using Arduino IDE [CTRL + u] - for an ESP32, you may need to hold down the IO0 button when esptool.py initiates
- **Upload 'data' folder**: Upload data folder (home.html web page etc) using `tools > ESP32 Sketch Data Upload tool`

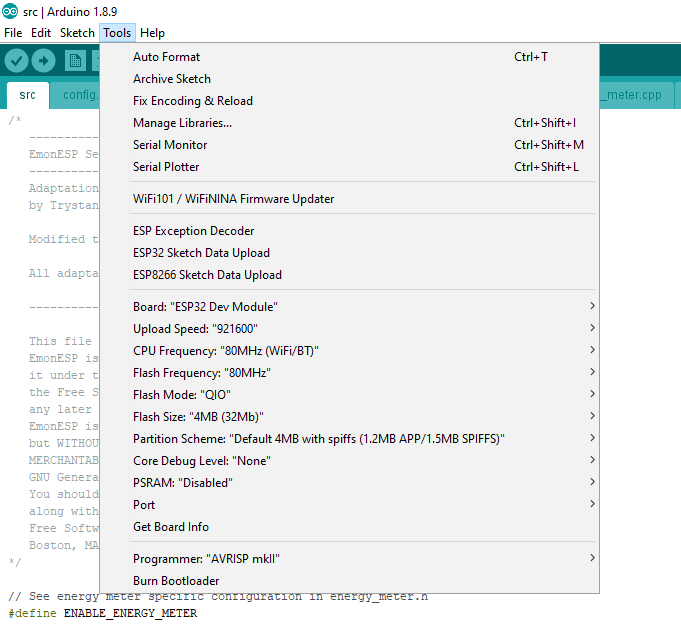
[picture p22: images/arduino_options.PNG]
arduino options


### Troubleshooting Upload

#### Library errors 

- If compiling fails because AsyncMqttClient.h library cannot be found. go to https://github.com/marvinroger/async-mqtt-client and copy the library to your Arduino/libraries folder
- For the ESP32, you will probably need these libraries (installed to Arduino/libraries):
    - https://github.com/me-no-dev/AsyncTCP
    - https://github.com/me-no-dev/ESPAsyncWebServer
- If you get an error for hash.h, put a folder under Arduino/libraries "Hash" and load it with these files: https://github.com/esp8266/Arduino/tree/master/libraries/Hash/src

#### Erase Flash

If you are experiencing ESP hanging in a reboot loop after upload it may be that the ESP flash has remnants of previous code (which may have the used the ESP memory in a different way). The ESP flash can be fully erased using [esptool](https://github.com/themadinventor/esptool). With the unit in bootloder mode run:

`$ esptool.py erase_flash`

*`sudo` maybe be required*

Output:

```
esptool.py v1.2-dev
Connecting...
Running Cesanta flasher stub...
Erasing flash (this may take a while)...
Erase took 8.0 seconds
```

#### Fully erase ESP-12E

To fully erase all memory locations on an ESP-12 (4Mb) we need to upload a blank file to each memory location

`esptool.py write_flash 0x000000 blank_1MB.bin 0x100000 blank_1MB.bin 0x200000 blank_1MB.bin 0x300000 blank_1MB.bin`

***

### Development Forum Threads

- https://community.openenergymonitor.org/t/emonesp-firmware-development/1191/43
- https://community.openenergymonitor.org/tags/emonesp

### License

GNU V3 General Public License

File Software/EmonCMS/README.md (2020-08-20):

The above .json files are now included in the [Device module for EmonCMS](https://github.com/emoncms/device)

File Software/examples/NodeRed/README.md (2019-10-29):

# EmonESP > MQTT > Node-Red > InfluxDB

This Node-Red flow takes MQTT data published from EmonESP (the default ESP32 program for the Split Single Phase Energy Meter), formats it, throttles it to get a sample every 10 seconds, then sends it to an InfluxDB database. 

### EmonESP Setup
- MQTT Server: Your MQTT broker address. If using Home Assistant with Mosquitto broker installed, this is the address of Home Assistant. The port defaults to 1883
- MQTT Base-topic: emon/emonesp
- MQTT Feed-name prefix: none
- Username: the username for your MQTT broker
- Password: the password for your MQTT broker

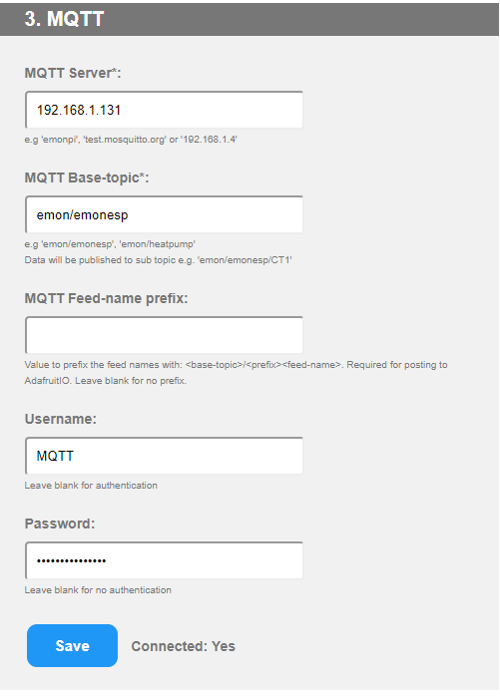
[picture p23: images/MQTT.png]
EmonESP MQTT


### InfluxDB Setup
- Go to InfluxDB Admin > Databases
- Create a new database called emoncms - set the retention policy to autogen and the duration to whatever you would like. 
- Go to Users
- Create a user named emoncms and set the permissions to all

### Node-Red Setup
- Go to Menu > Import
- Paste the contents of or select EmonESP-MQTT-NodeRed-InfluxDB.json to import
- The flow should be imported
- Double click on 'emonesp', and set the credentials for MQTT (broker)
- Click the pencil next to 'MQTT-local'. This should be the same as in the first step of EmonESP setup. Or, if you're using Home Assistant with Mosquitto, and Node-Red installed under Hass.io it can be 'localhost'. Don't forget to click on Security and set the login/password
- Double click on 'V1 to Influxdb'
- Click on the pencil next to 'emoncms' and set the credentials for the InfluxDB database. You shouldn't have to do this on all of the function nodes unless the name of the database is not 'emoncms'. 

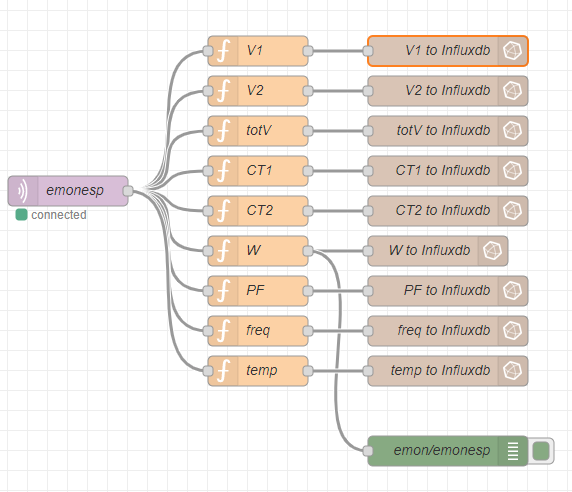
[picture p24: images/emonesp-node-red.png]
Node-Red Energy Meter Flow


From here make sure that data is being sent to InfluxDB by going to Explore, and emoncms.autogen. You should see a graph when clicking on this, the field name, then checking value.

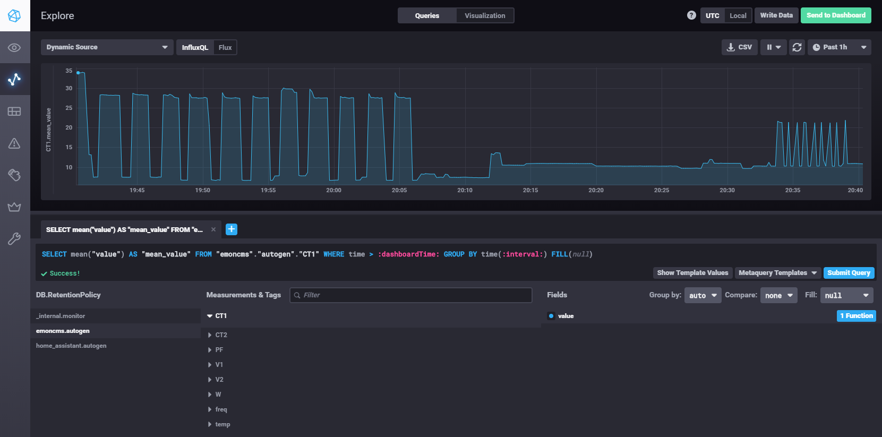
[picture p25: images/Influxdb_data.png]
InfluxDB EmonESP Data


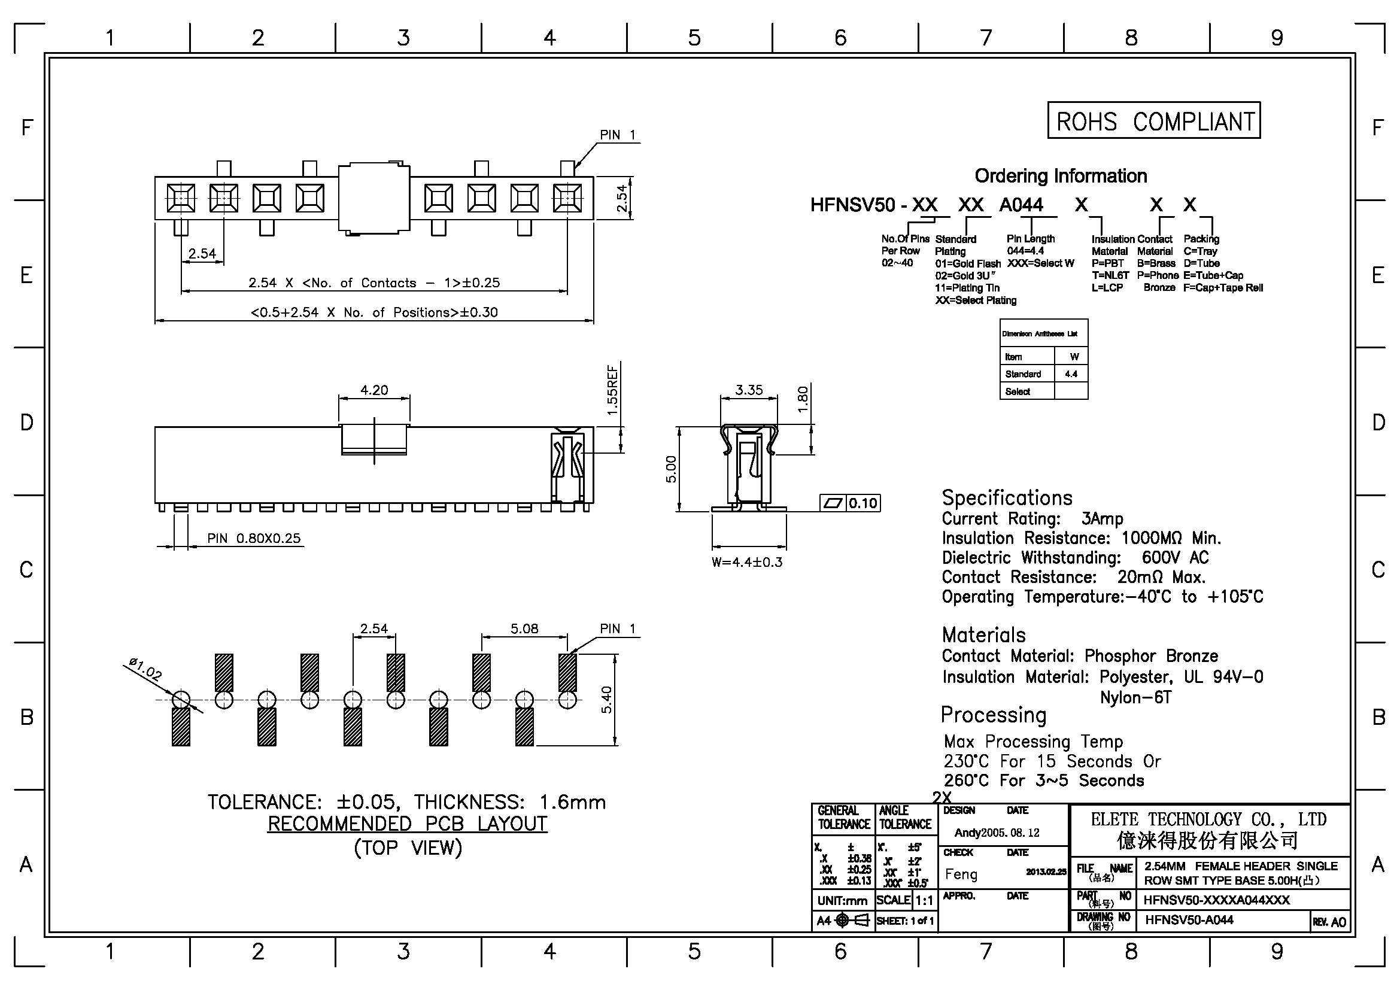
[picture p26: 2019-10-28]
Hardware/docs/header_smd-1x19.png

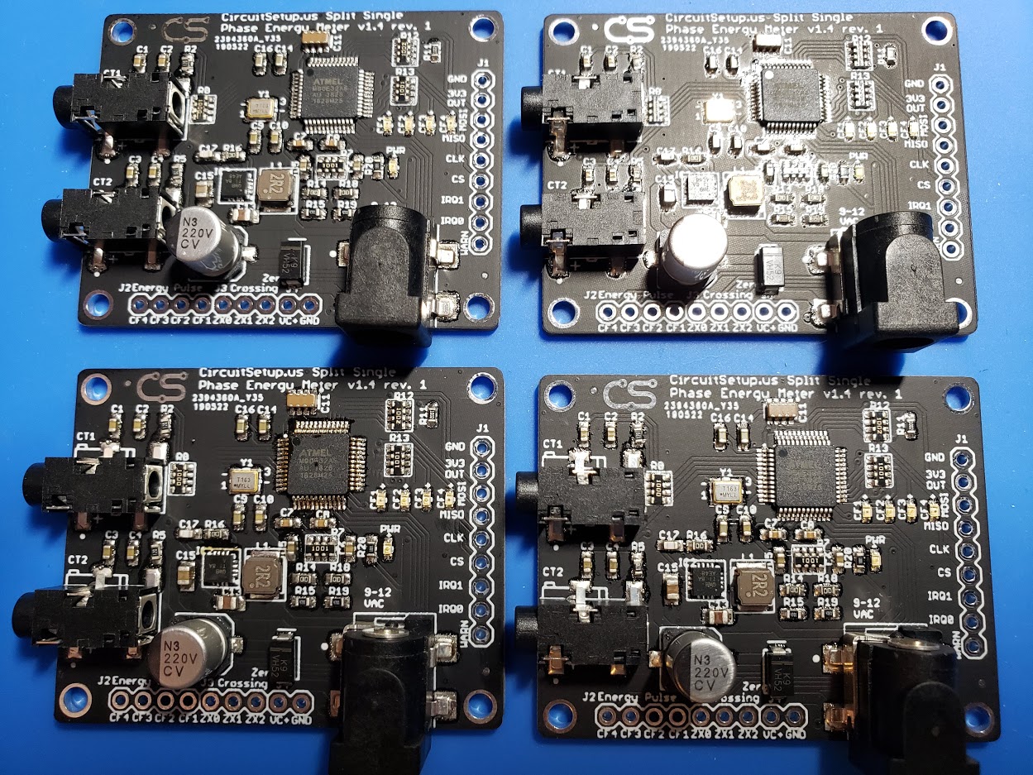
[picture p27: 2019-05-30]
Hardware/energy_meter_v1.4.jpg

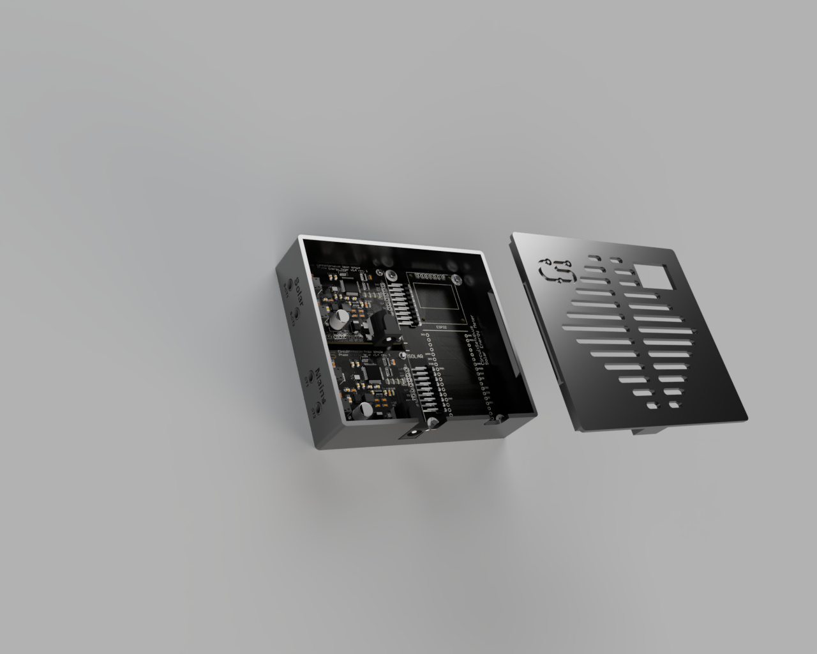
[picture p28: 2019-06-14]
Hardware/energy_meter_solar_box.jpg

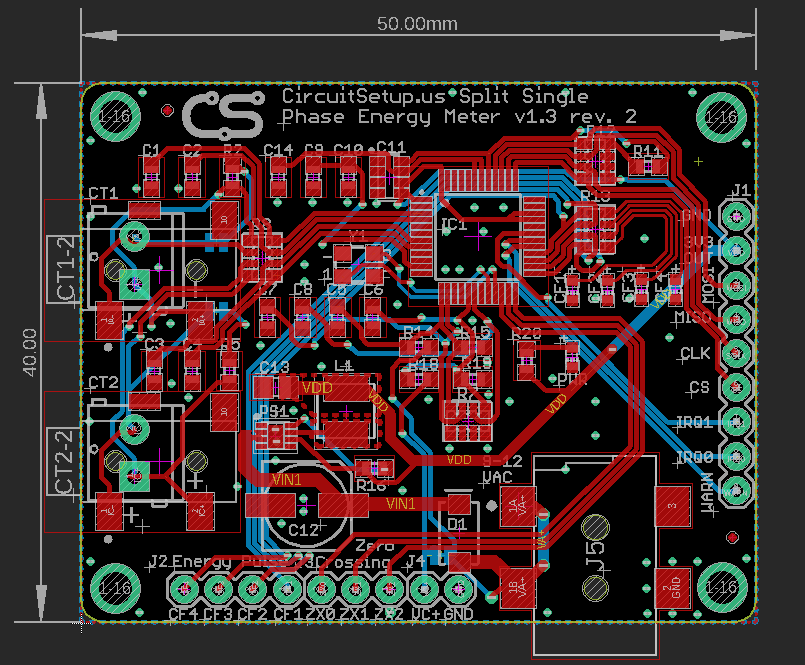
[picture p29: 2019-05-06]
Hardware/energy_meter_pcb_v1.3.png

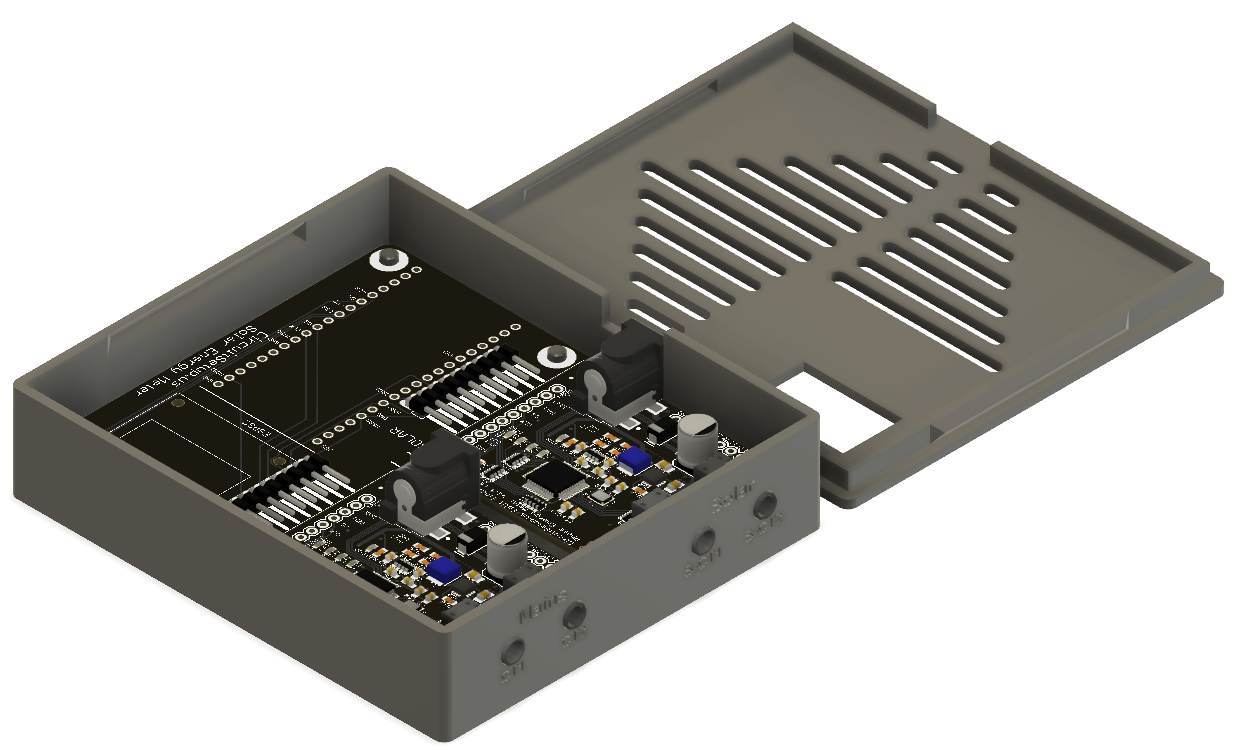
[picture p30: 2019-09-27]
Hardware/energy_meter_solar_box.PNG

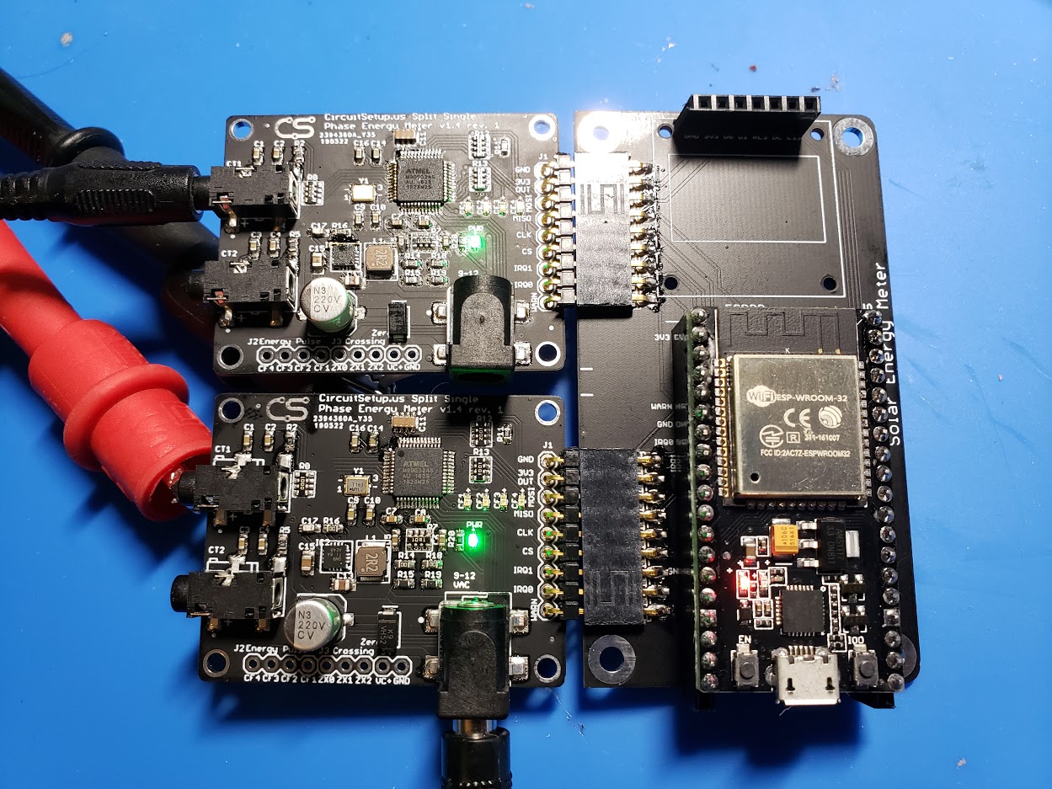
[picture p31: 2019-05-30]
Hardware/energy_meter_solar.jpg

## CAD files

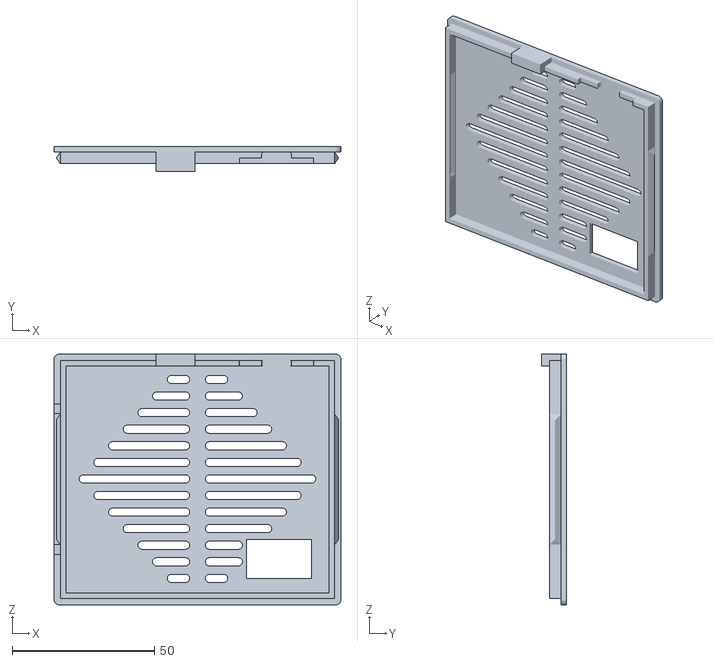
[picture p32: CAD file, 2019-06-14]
Hardware/energy_meter_solar_box_lid.stl
101.0 x 8.80 x 88.3

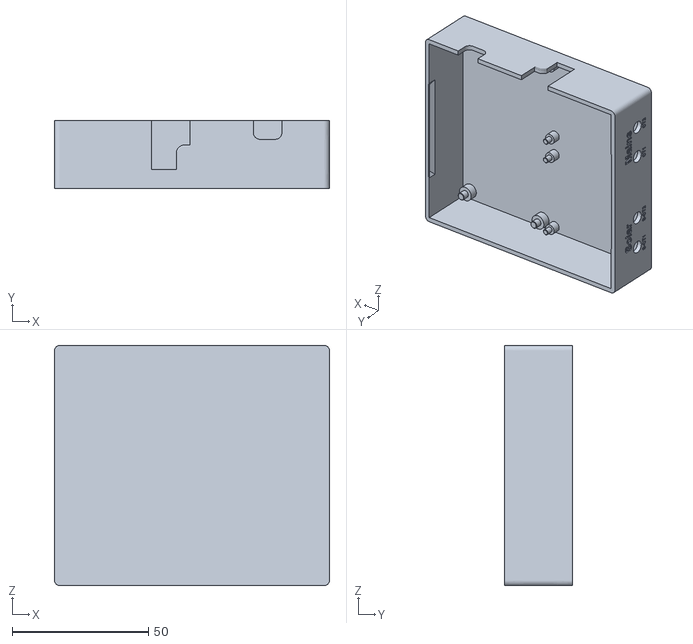
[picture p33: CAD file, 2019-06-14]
Hardware/energy_meter_solar_box_case.stl
101.0 x 25.0 x 88.3

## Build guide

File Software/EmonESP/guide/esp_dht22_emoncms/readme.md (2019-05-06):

# ESP DHT22 to Emoncms Example

An example made using the [Adafruit Huzzah](https://www.adafruit.com/product/2471) board with ESP-12 module and the DHT22 temperature humidity sensor.

This code example, when loaded onto the ESP will continuously upload temperature and humidity data onto [emoncms.org](https://emoncms.org)

[CP2102 USB to UART adapter](https://shop.openenergymonitor.com/programmers) was used as power supply and to program the ESP. 
PlatformIO or Arduino IDE can be used to compile and upload code. See [PlatformIO compile and upload guide](https://guide.openenergymonitor.org/technical/compiling)

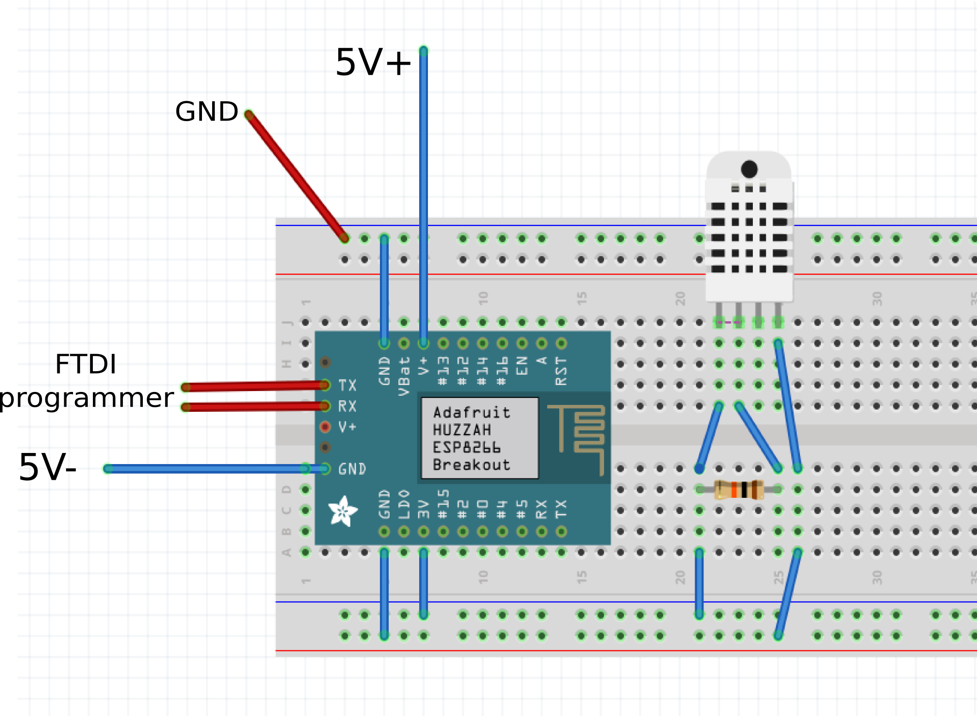
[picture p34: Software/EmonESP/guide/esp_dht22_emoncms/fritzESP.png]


Thanks to @myrddinmuse for puting together this example.

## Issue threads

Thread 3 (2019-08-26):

Using with single phase UK (240v) mains power

motechsolutions, 2019-08-26:
What changes would i have to make to the firmware (Arduino sketch files) to allow the split phase energy meter to correctly monitor UK 240v single phase mains power.
Im using a 9V AC 240V transformer type power supply and two CT current sensors (SCT-013-000 100A/50mA)

Any advise would be much appreciated

motechsolutions, 2019-08-26:
Hi
Yes im using the latest version from your repo :)
The EMONESP web interface shows V1 as 122v and V2 as 122v and the total voltage shows 244v, is this correct (voltage gain field = 4485). The strange thing is if i set the freq in the web interface or in energy_meter.h to 389 (50hz value) then the total voltage value is the same as V1 (122v). how to i get the v1 value to display the correct voltage (ie 244v) as the "Voltage gain" value will not go above 65535 and ive calculated i need to have a value of  (real v=244v / v1=122v * V-Gain = 38730) 77460

Thank you in advance

motechsolutions, 2019-08-27:
Hi again
That worked a treat, Voltage now shows correct 243v. one quick thing, what do i need to change to get the following setup for watts data.
Watt1
Watt2
Total Watts (Watt1)
my setup is a home with a office. a single phase 240v mains power to house which also supplies power to the office at the back, (Single power distribution board with separate circuit for office)

Thanks in advance

motechsolutions, 2019-08-27:
That sorted the EMONESP web interface, :)

I think for me it may be a better to display and track the two CT sensors independently on EMONESP and EMONCMS , make CT1 and CT2  independent (your thoughts ?)

Values in EMONESP Web and values sent to EMONCMS

**Circuit1:**
CT1
W1
PF1

Circuit2
CT2
W2
PF2

I  think energy_meter.cpp/h and circuitsetup_split-phase.json would need to be changed but i may be wrong (newbie to Arduino etc)

Thanks in advance

Also ive uploaded my split phase energy monitor to ESP32 adapter board to easyeda if anyone wants to use it for a 30pin ESP32S & 0.96" OLED display
https://easyeda.com/motechsolutions/Split-Phase-Energy-Monitor-ESP32-Adapter

motechsolutions, 2019-08-27:
I think ive sorted circuitsetup_split-phase.json

`{
    "name": "Single Phase Energy Meter",
    "category": "CircuitSetup",
    "group": "Energy Monitoring",
    "description": "CircuitSetup Split Single Phase Energy Meter",
    "inputs": [
		{
            "name": "CT1",
            "description": "Current CT1",
            "processList": [
                {
                    "process": "log_to_feed",
                    "arguments": {"type": "ProcessArg::FEEDID", "value": "Current CT1" }
                }
            ]
        },
		{
            "name": "CT2",
            "description": "Current CT2",
            "processList": [
                {
                    "process": "log_to_feed",
                    "arguments": {"type": "ProcessArg::FEEDID", "value": "Current CT2" }
                }
            ]
        },
        {
            "name": "PF",
            "description": "Power Factor",
            "processList": [
                {
                    "process": "log_to_feed",
                    "arguments": {"type": "ProcessArg::FEEDID", "value": "Power Factor" }
                }
            ]
        },
		{
            "name": "temp",
            "description": "Temp",
            "processList": [
                {
                    "process": "log_to_feed",
                    "arguments": {"type": "ProcessArg::FEEDID", "value": "Temp" }
                }
            ]
        },
		{
            "name": "totV",
            "description": "Voltage",
            "processList": [
                {
                    "process": "log_to_feed",
                    "arguments": {"type": "ProcessArg::FEEDID", "value": "Voltage" }
                }
            ]
        },
		{
            "name": "W2",
            "description": "Watts CT2",
            "processList": [
                {
                    "process": "log_to_feed",
                    "arguments": {"type": "ProcessArg::FEEDID", "value": "Watts CT2" }
                }
            ]
        },
        {
            "name": "W1",
            "description": "Watts CT1",
            "processList": [
                {
                    "process": "log_to_feed",
                    "arguments": {"type": "ProcessArg::FEEDID", "value": "Watts CT1" }
                },
                {
                    "process": "power_to_kwh",
                    "arguments": {"type": "ProcessArg::FEEDID", "value": "CT1 kWh" }
                }
            ]
        }
    ],

    "feeds": [
        {
            "name": "Current CT1",
            "type": "DataType::REALTIME",
            "engine": "Engine::PHPFINA",
            "interval": "10",
            "unit": "A"
        },
        {
            "name": "Current CT2",
            "type": "DataType::REALTIME",
            "engine": "Engine::PHPFINA",
            "interval": "10",
            "unit": "A"
        },
        {
            "name": "Voltage",
            "type": "DataType::REALTIME",
            "engine": "Engine::PHPFINA",
            "interval": "10",
            "unit": "V"
        },
		{
            "name": "Watts CT1",
            "type": "DataType::REALTIME",
            "engine": "Engine::PHPFINA",
            "interval": "10",
            "unit": "W"
        },
		{
            "name": "Watts CT2",
            "type": "DataType::REALTIME",
            "engine": "Engine::PHPFINA",
            "interval": "10",
            "unit": "W"
        },
		{
            "name": "Power Factor",
            "type": "DataType::REALTIME",
            "engine": "Engine::PHPFINA",
            "interval": "10",
            "unit": ""
        },
		{
            "name": "Temp",
            "type": "DataType::REALTIME",
            "engine": "Engine::PHPFINA",
            "interval": "10",
            "unit": "°C"
        },
		{
            "name": "CT1 kWh",
            "type": "DataType::REALTIME",
            "engine": "Engine::PHPFINA",
            "interval": "10",
            "unit": "kWh"
        }
    ]
}
`

CircuitSetup, 2019-08-29:
You can edit the device json file, but you should be able to just change or add the feeds too. When they export from EmonESP, they should appear in EmonCMS anyway.

Thanks for sharing the EasyEDA board as well. That looks good! You may need some extra power for the display though. If wifi on the ESP32 has trouble staying connected and freezes, that may be why. I would recommend having a separate 3v3 input to power the diplay and/or board.

motechsolutions, 2019-08-29:
After reading this post (https://community.hiveeyes.org/t/power-supply-for-the-esp32/1859/7)
Ive added a 47uF tantalum capacitor and a 100uF low-ESR electrolytic capacitor to the 3.3v rail next to the ESP32 3.3v pin, on testing with a scope and DVM the current pull from the ESP32 and OLed is max 175ma and the 3.3v power rail looks more stable but i need to now soak test my design.
Even if i dont use the OLed display the extra capacitors can only help the ESP32 power rail.
Ive updated my EasyEDA design so yourself and others can see the new adapter PCB design
Your thoughts?

CircuitSetup, 2019-08-29:
Those caps will definitely help with the spikes. By default if a connection is lost, the esp will go into AP mode, which I've found uses the most power starting up, and then staying up.

FYI, The energy meter board has a 22uf cap on the 3v3 output from the SMPS.

If you need to reduce the power any more you can turn down the esp clock to 80mhz when EmonESP is compiled, or turn off going into AP mode when a connection is lost in web_server.cpp

CircuitSetup, 2019-09-22:
Curious if you've got this up and running yet?

motechsolutions, 2019-09-23:
Hi John

Yes working great, the first CT monitors my house and the second CT monitors my office.
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

CircuitSetup, 2019-09-23:
Very nice! I'm sure some other Europeans would benefit from your calibration settings with that AC Transformer. Do you mind sharing?

motechsolutions, 2019-09-24:
No problem at all,
**AC transformer** = https://www.ebay.co.uk/itm/9V-AC-AC-Adaptor-Transformer-Power-Supply-5-5mm-UK-Plug/312408988666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

**Calibration Settings**
Voltage = 38990
CT1 & CT2 = 25758
Freq = 389
CT Gain = 21

Closed 2019-09-09.

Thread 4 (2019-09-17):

Issue with device crashing after x hours SSPEM

jreiners, 2019-09-17:
Not sure if this is the forum, and I doubt it is, and I'm sorry.

I've installed the split single phase energy monitor on my breaker box without issue, and configured wifi with good signal at -61db, but randomly and frequently since I've got it running a few hours it seems the monitor device locks up and drops off wifi.

The only way I know to get it back is to cause an unexpected power interruption, and suddenly everything seems to work for a bit.

I have not got it working with emoncms yet, it can see the inputs, and they are all green but I haven't actually seen it plot anything.

I assume it might be locking up, just wondering what I can do to troubleshoot.

The values I can see are below:

Key | Value
-- | --
V1 | 119.29V
V2 | 119.30V
CT1 | 22.7940A
CT2 | 22.7920A
totI | 45.5860A
W | 5005.5142W
PF | 0.05
temp | 27.00
freq | 60.02

Thanks for your help, and I am excited for this project.

Edit, after some more research I saw your troubleshooting steps for the device, it does seem to me like it is browning out and crashing, but I've got a ubiquiti AC router within 10 feet, and I'm connecting to 2.4ghz in a basement so signal should not be low enough to cause brownouts that I can imagine, can I possibly use a different, even higher voltage/current brick to power it?

CircuitSetup, 2019-09-18:
Glad you got things up and running, but sorry you're having connection issues!
You have a kit, correct?

In testing, if the wi-fi signal was low, and the ESP32 lost the connection, it would go into SoftAP mode, which uses more power. That repeating over and over would sometimes cause the brownout detector to trigger, and the ESP32 would lock. -70db is usually around where I would see this happen.

Try loading [this firmware for EmonESP:](https://github.com/CircuitSetup/Split-Single-Phase-Energy-Meter/raw/master/Software/EmonESP/src/emonesp_v2.5.2_noAP_lost_conn.bin)

If it loses the connection to the main AP, it will not go into SoftAP mode. Since it already has your router credentials stored, you don't need the SoftAP (unless you want to change which AP it connects to)

Also, does your AP happen to have the same name with 2.5ghz and 5ghz, or do you have a repeater with the same name? This could be confusing the ESP32 as well if it drops a connection and tries to connect to the other physical AP.

One last thing - your PF seems to be low. You may have your CT clamps on backwards, but it really doesn't matter if you don't care about that value, have solar panels, or want to use any of the other metering values.

CircuitSetup, 2019-09-18:
> can I possibly use a different, even higher voltage/current brick to power it?
If you have a higher amperage *AC* Transformer you can also try that. The one provided is 1A, but there are also 1.5A Jameco ones out there (along with others that I haven't personally tested). You'll probably have to calibrate for that transformer though. Higher voltage won't matter in this case.

jreiners, 2019-09-18:
yes I received my kit yesterday!!!

I'll try loading that firmware and let you know how it goes, it's offline again atm, I set it up temporarily on emoncms a couple hours ago, and it lasted about an hour before it dropped offline. Now that I am home I just checked to see if it was broadcasting its SSID and its not.

I have a pretty simple ubiquiti setup with a few access points spread around, none of the SSID are shared between 2.4 and 5ghz, I'm used to IOT wifi controllers that are 2.4ghz only so I have everything set for easy onboarding of devices.

I'll try the firmware first, I'd rather disable the ap anyways. If that doesn't work I might have another AC transformer in the shop.

As for PF, I noticed that and will fix, thanks for pointing that out,  I'd rather get it working for a few hours first.

CircuitSetup, 2019-09-18:
> yes I received my kit yesterday!!!

awesome!

> I have a pretty simple ubiquiti setup with a few access points spread around, none of the SSID are shared between 2.4 and 5ghz, I'm used to IOT wifi controllers that are 2.4ghz only so I have everything set for easy onboarding of devices.

That shouldn't be causing any issues then.

> I'll try the firmware first, I'd rather disable the ap anyways. If that doesn't work I might have another AC transformer in the shop.

If you have one without the same plug as the existing, you can use the VC+ and GND inputs next to the jack on the board. Further, if you want to only give a voltage signal to the board while VC+ is connected, you can sever the JP3 trace on the back of the board, and power the rest of the electronics through the ESP32 with a phone charger. Just make sure it's not a crappy one or, if it is use a usb cable with a ferrite bead.

jreiners, 2019-09-18:
> If you have one without the same plug as the existing, you can use the VC+ and GND inputs next to the jack on the board. Further, if you want to only give a voltage signal to the board while VC+ is connected, you can sever the JP3 trace on the back of the board, and power the rest of the electronics through the ESP32 with a phone charger. Just make sure it's not a crappy one or, if it is use a usb cable with a ferrite bead.

Very nice, when I went to reboot it I noticed the box had a hole that lined up with usb, I might go that route if it keeps dropping, that would probably take care of all of my issues. I have some fairly nice 2.4A 5v Samsung chargers.

I updated to the above firmware before dinner, sadly I still had a drop about 20 minutes later.

I took the panel apart and flipped the backwards one, readings are better. I also rose the meter up higher above the panel instead of below, which increased my signal another 7 percent.

fingers crossed.

jreiners, 2019-09-18:
OK, After moving the device above the breaker panel, it worked all night without crashing.

Another question, after moving everything I noticed that the PF was low again, I have both clamps installed before my main breaker, with arrows pointing in the direction of my main breaker. Should I flip one around so they are opposite? It doesn't seem right.

Thank you for your help.

CircuitSetup, 2019-09-18:
Glad to hear it's staying connected after moving it a bit closer! It seems that some of these ESP32s use a tiny bit more power than others to stay connected.

How low is your PF getting? The CTs should be pointing in the same direction.

jreiners, 2019-09-18:
Here is my latest grab from the device itself. Thanks for the help!

I really don't have much worry about my PF is I'll get the correct W readings

Key | Value
-- | --
V1 | 119.17V
V2 | 119.20V
CT1 | 22.4450A
CT2 | 19.9800A
totI | 42.4250A
W | 4676.0234W
PF | -0.02
temp | 27.00
freq | 59.99

I did make sure each arrow was pointing toward the breaker

CircuitSetup, 2019-09-18:
Interesting, it's possible the arrow is reversed on the CT. If it doesn't matter to you, then it's okay :)

jreiners, 2019-09-18:
I did think of that, possibly the coil inside is reversed, as they both are in the orientation with cord leaving the top side. If it bothers me later I'll flip it around. Looks like I'm all set. Thanks again.
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
jreiners, 2019-09-18:
That's probably it, I'll try switching it again, it crashed on me again a bit ago, I got about 12 hours before it died.

I did try to desolder J3 last night, but no matter what I did it still powered up the ESP32, and lost my `second` voltage reading so I resoldered it.

Can I just flush clip +5v or GND to the ESP32 and then use the USB power or is +5v needed from the other board for anything?

CircuitSetup, 2019-09-18:
> @jreiners I know in my area of the US when I changed code bases on my 2 channel meter it made me realize I should have the clamps opposite of one another in direction since the the lines were out of phase from each other.

Really? The phase shouldn't matter - it's all about the direction of the winding on the coil. I wonder if one of your CTs is wired backwards internally.

> That's probably it, I'll try switching it again, it crashed on me again a bit ago, I got about 12 hours before it died.

I'm honestly not sure why that keeps happening with yours. I would say try putting in another ESP32 to see if that makes a difference, but there aren't many that are as narrow as the NodeMCU one.

> I did try to desolder J3 last night, but no matter what I did it still powered up the ESP32, and lost my `second` voltage reading so I resoldered it.

Sorry, I should have mentioned you have to physically cut the jumper with a knife.

> Can I just flush clip +5v or GND to the ESP32 and then use the USB power or is +5v needed from the other board for anything?

If you power through the ESP32, (assuming JP3 is cut or the rectifier diode is removed) the rest of the electronics would be powered via the ESP32's 3V3 power supply (LDO). I wouldn't recommend hooking up both the transformer and ESP32 power at the same time for very long. If you hook up the 5v pin on the ESP32 it should still go through to the 3V3 output.

digiblur, 2019-09-18:
Yep. Definitely threw me at first. Amps were fine but wattage was negative. So I multiplied the value to flip it. Then later I changed the phase the power supply was on after installing a closer plug. Then the value flipped again. It seemed to follow the reference voltage phase.

jreiners, 2019-09-25:
I think I might have found something, I noticed my energy meter crashing may be caused by having it's web page open in multiple tabs, it happened again yesterday when I didn't realize I already had a tab open in chrome, and opened another one, about 20 minutes later my meter dropped off the network.

I use an app for work called sysdweb to control systemd services, and when multiple users logged it it would crash similarly, probably no fix for it, but figured I'd offer the info.

I tried it again this morning, and 12 minutes later it crashed on me, and I needed to reboot it.

I ended up buying an internet switch so I can bounce it from anywhere.

CircuitSetup, 2019-09-26:
This may actually make sense. If the interface is open itll refresh via async. In testing async was throwing random error messages that didnt make sense. This may have been causing a memory leak.

The library for AsyncTCP was just updated a couple days ago to address an issue that looks related. I'll look into this more and release a patch.

jreiners, 2019-09-26:
Sweet! Hopefully it helps, that is the only way I can crash it.

Is that something I'll need to compile and reflash?

CircuitSetup, 2019-09-26:
It would only happen if the interface was left open. Let me know if not having it open helps. Either way, I'll release a new firmware version with the AsyncTCP update.

jreiners, 2019-09-26:
Yeah, it works fine for days without issue if I don't open it, and leave it open refreshing, no need to really anyways if it's working.

Emoncms works fine open for days so I'm good.

Thanks for this.

CircuitSetup, 2019-09-26:
Glad to hear!

More specifically, this also may have been causing issues, and was just recently fixed: https://github.com/me-no-dev/ESPAsyncWebServer/commit/2f3703702987e31249d4c5c9d1f90cebf1ffa9e8

CircuitSetup, 2019-10-03:
> @jreiners I know in my area of the US when I changed code bases on my 2 channel meter it made me realize I should have the clamps opposite of one another in direction since the the lines were out of phase from each other.

I was just thinking about this again, and you are right. Since the voltage reference, by default, is only from one side of the panel (on the pcb the voltage signal is split unless the jp3 jumper is severed). Current from the other side will be out of phase from that voltage, and appear to the meter as a negative value. I don't know why that didn't click in my head sooner.

Closed 2019-09-18.

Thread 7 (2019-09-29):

Calibration setting for 240V regions

amil109, 2019-09-29:
Hi there,

I'm not sure if this is definitely the right place to submit this, but it is a software issue (I suppose) so I figured here was as good as anywhere!

I live in the UK, and have one of the Split-Single-Phase energy meters - it's working very well, except I need to be able to calibrate the voltage to read correctly.

I have a 230VAC/9VAC transformer, and get a completely sensible reading of ~122V in EmonESP. This corresponds to an actual line voltage of ~244V (measured with a multi-meter).

Using the calibration calculation in the readme, based on the default voltage gain:

VoltageGain = 37106 * 244 / 122 = 74212

When I try to put this value in the GUI, I get an error, telling me it's above 65535 (I suppose it's a 16bit integer).

Would it be possible to add a 'switch' for 240V operation? I can post-process the data in EmonCMS and can display the corrected value in OpenHab based on the MQTT feed, but it would be nice to be able to have it corrected at source.

Happy to write some code myself if you can point me to the right place!

Aside from the minor issue above, thanks for the great product!!!

Cheers,

amil109

CircuitSetup, 2019-09-29:
Make sure you change the frequency setting to 50hz in the config. After that is changed EmonESP should adjust for 220/240v.

netomx, 2019-10-02:
But what about 240V and 60Hz?

CircuitSetup, 2019-10-02:
> But what about 240V and 60Hz?

I actually didnt realize that this was used until recently. What country are you using the meter in? I'll get a fix out for this shortly.

netomx, 2019-10-02:
Mexico. Industries use 240V and 60Hz. Households use 127V

CircuitSetup, 2019-10-03:
Right. Is that still split single phase, or 2 phase? It shouldn't matter as long as you only have 2 mains wires to measure and it's not 3 phase.

netomx, 2019-10-03:
2 phases of 127v

amil109, 2019-10-04:
I can confirm that switching to 50Hz worked for me.

I had put the calibration value only for frequency in the configuration before I posted, but it only seemed to switch voltages once I also put in a calibration value for the voltage itself.

In any case, all's good now!

motechsolutions, 2019-10-15:
I had the same issue as im in the UK as well, Circuit Setup fixed the 240V problem a while back, take a look at https://github.com/CircuitSetup/Split-Single-Phase-Energy-Meter/issues/3 to see the fixes i needed for 240v 50Hz uk

cfunseth, 2019-12-02:
Regarding calibration settings, I'm attempting to use the Home Assistant MQTT sketch provided in this repo but I'm having some issues with an incorrect voltage being reported.  I purchased the kit from CircuitSetup and everything was working out of the box correctly with EmonESP loaded.  When I flashed the example MQTT sketch though, I'm getting a voltage reading of ~590V on each phase.

I'm wondering how the 37,106 value for "VoltageGain" was determined?  Assuming I'm on a 120V/60Hz system, I'd imagine there's a 13.3x ratio (120V/9V) as well as the voltage divider being used on the schematic, but that only looks to to account for another 11x ratio (110k/10k).  Therefore I'm getting a total gain of 146.67, but that results in a value that's way too low.  Is there something I'm missing from the Atmel IC?

BitKnitting, 2019-12-03:
IDK if this will help..but here is what I learned regarding calibration
<https://github.com/BitKnitting/FitHome/wiki/ElectricityMonitor#calibration>

On Mon, Dec 2, 2019 at 10:24 AM Cole Funseth <notifications@github.com>
wrote:

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

CircuitSetup, 2019-12-03:
@cfunseth I believe I sent you a hand assembled version of the energy meter with resistors for the voltage divider that will come on the next batch (which are 20k and 10k). The calibration value for voltage can be changed to 7611 in the MQTT sketch.

cfunseth, 2019-12-03:
@CircuitSetup Ah, thank you for clarifying!  Would you mind explaining how the 7,611 value was calculated?  I can't find anything in the ATM90E32 datasheet and even with the resistor changes you mentioned I still don't see where.  I didn't want to create a new issue on this but can if you'd prefer to keep this closed.

Closed 2019-12-03.

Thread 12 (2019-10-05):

Can't complile EmonESP code using platformio

veggie2u, 2019-10-05:
Wanted to try logging to the serial monitor, so trying to compile the esp code using platformio. Is this what you are using @CircuitSetup ? Or the Arduino platform? As per the readme, I pulled the code, entered the EmonESP folder. If I try just a
`pio run`
i am told that there is no emonesp environment, which is true. There is no definition for one in the platformio.ini file - there is in the upstream project. Since this is an Esp32 I changed the default to emonesp32 which does exist and tried to compile again with
`pio run`
I then get compile errors
```compilation terminated.
*** [.pio/build/emonesp32/src/web_server.cpp.o] Error 1
src/energy_meter.cpp: In function 'void energy_meter_loop()':
src/energy_meter.cpp:175:29: warning: variable 'totalVoltage' set but not used [-Wunused-but-set-variable]
   float voltageA, voltageC, totalVoltage;
                             ^
In file included from src/http.cpp:32:0:
/Users/chris/.platformio/packages/framework-arduinoespressif32/libraries/WiFiClientSecure/src/WiFiClientSecure.h:29:1: error: expected class-name before '{' token
 {
 ^
/Users/chris/.platformio/packages/framework-arduinoespressif32/libraries/WiFiClientSecure/src/WiFiClientSecure.h:105:18: error: type 'Print' is not a base type for type 'WiFiClientSecure'
     using Print::write;
                  ^
src/http.cpp: In function 'String get_https(const char*, const char*, String, int)':
src/http.cpp:63:12: error: 'class WiFiClientSecure' has no member named 'print'
     client.print(String("GET ") + url + " HTTP/1.1\r\n" + "Host: " + host +
            ^
src/http.cpp:75:28: error: 'class WiFiClientSecure' has no member named 'readStringUntil'
       String line = client.readStringUntil('\r');
                            ^
*** [.pio/build/emonesp32/src/http.cpp.o] Error 1
```

Is this how you would/are building the code?

CircuitSetup, 2019-10-05:
I've only.compiled with Arduino lately because of some important updates to AayncTCP, that I dont believe are in platformio yet. This relate to memory leaks and not.closing browser sessions properly.

There should be a definition for the esp32 in the latest initiative file. I just added it recently. The total totalvoltage variable is only.used with 50hz setups, so that needs to be moved. The other errors, in not sure why they are coming up. Perhaps those libraries need to be updated.

veggie2u, 2019-10-05:
Ok. I have been trying to get this to compile under Arduino for a bit. I did run into all the issue from the Libraries Errors section of the readme. I also moved over the ATM90E32 files from the project into an Arduino library.

I am stuck on the Hash library. The Hash.cpp you pointed to also has this line:
`#include <bearssl/bearssl_hash.h>`
Been trying to figure out where to get this. There is an ArduinoBearSSL in the library manager, but that doesn't look right. The Hash library in the ESP2866 board definition doesn't use bearssl, but it was trying to use <c_types.h> That doesn't work. I did find the file locally at
`~/Library/Arduino15/packages/esp8266/hardware/esp8266/2.5.1/tools/sdk/include/bearssl`
I have no idea how 'tools' are used, but the compiler doesn't seem to find it. Do you remember what you did? (Arduino 1.8.10)

CircuitSetup, 2019-10-06:
What version of the esp32 arduino IDE are you using? Hash should be included.  If not 1.0.3, use that as it has the latest fixes for a number of things.

veggie2u, 2019-10-06:
Do you mean the board? 1.04. I don't see it in 1.03 either though https://github.com/espressif/arduino-esp32/tree/1.0.4/cores/esp32

The Hash function you link to in the docs is from the esp8266 libraries
https://github.com/esp8266/Arduino/tree/master/libraries/Hash/src

It looks like it was changed recently from using an internal sha1 class (I am guessing you used that), to the bearssl based version. However, I can't get either one to compile. If I go to the branch tagged with 2.5.2, there is a separate file called sha1.c. This wont compile for me with the
`#include <c_types.h>` line in there.
If I take that out, I then have issues with all the methods that have ICACHE_FLASH_ATTR in them. I am not a C programmer, and I have no idea what that is for. I do know that it is not defined in sha1.h.

I have found it in the tools section of esp8266 there is a define there for ICACHE_FLASH_ATTR, but that c_types.h file is not in the section of the esp32 git library. I really can't see how this version of Hash can compile for you.

I tried adding the definition I found there:
```
#ifdef ICACHE_FLASH
#define ICACHE_FLASH_ATTR   __attribute__((section("\".irom0.text." __FILE__ "." __ICACHE_STRINGIZE(__LINE__) "." __ICACHE_STRINGIZE(__COUNTER__) "\"")))
#else
#define ICACHE_FLASH_ATTR
#endif /* ICACHE_FLASH */
```
No idea what that is doing though. It gets me past the compile, but the link fails. Not sure if that stuff is particular to the esp8266 or not.
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
CircuitSetup, 2019-10-08:
> Do you mean the board? 1.04. I don't see it in 1.03 either though https://github.com/espressif/arduino-esp32/tree/1.0.4/cores/esp32

Whoops, I meant 1.0.4, yes.

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

Ah, you're right, I didn't realize that was updated. I [added the version that I have in my libraries folder](https://github.com/CircuitSetup/Split-Single-Phase-Energy-Meter/tree/master/Software/libraries/Hash) until I can look at this some more.

You shouldn't have to worry about the multiple library exists messages, as long as it's getting the correct one.

> So, what board are you using? I have tried "ESP32 Dev Module" and "ESP32 Wrover Module"

I have ESP32 Dev Module set.

veggie2u, 2019-10-09:
Found the errors. Hash is not needed on an ESP32. It is not included as a library in the core ESP32 code. Not copying it to your library, and commenting out the include in web_server.h will allow Arduino to build it.

To get it to build with PlatformIO, I believe I ran into a case insensitive problem. The project file called wifi.h imports WiFi.h. It looks like these were getting confused. When I rename the project file to wireless.h and wireless.cpp - and changed the correct references, the build works. As it appears to have built on Arduino, and not on PlatformIO, I am wondering if it is just PlatformIO or the combination of it on MacOS.

CircuitSetup, 2019-10-09:
ohh, okay - I'll make hash.h conditional to the esp8266.

I'll have to test if platformio gets confused with the wifi.h files on my PC.

Thanks for figuring this out!

veggie2u, 2019-10-11:
Do you even want the esp8266 code? Your hardware is esp32. I could create a PR that removes the esp8266 ifdef stuff.

CircuitSetup, 2019-10-11:
There are others that use the esp8266. Thanks for offering.though!

tferrin, 2021-12-26:
@veggie2u With respect to "wifi.h" vs "WiFi.h", note that the macOS file system is case-insensitive. (It preserves the case in file names, but all name matching is case-insensitive.) Also, as far as I can tell, PlatformIO does not distinguish between #include <WiFi.h> and #include "WiFi.h". It always looks in the local src directory first. So the combination of these two things is what messed you up.

CircuitSetup, 2022-06-01:
This is fixed in the latest version of EmonESP

Closed 2022-06-01.

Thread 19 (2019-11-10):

Power factor value alternating +ve/-ve in ATM90E32.cpp

gbeardall, 2019-11-10:
The power factor value alternates between a +ve & -ve value for a constant load.
There is a bug in the precedence of the  `if()`  statement in all power factor functions.
The '&' operation needs to be surrounded by brackets, see below:

```
double ATM90E32::GetTotalPowerFactor() {
  signed short pf = (signed short) CommEnergyIC(READ, PFmeanT, 0xFFFF);
  //if negative
  if ((pf & 0x8000) != 0) {
	pf = (~pf) + 1;
  }
  return (double)pf / 1000;
}
```

Also, why is there effectively an `abs()` operation being performed on these values, doesn't a -ve value represent an inductive load?

Thanks, Gavin

CircuitSetup, 2019-11-10:
Thanks for bringing this up @gbeardall - I was literally just looking into this because I realized it didn't make sense. I _think_ this was done because the original function example (in C) from Atmel looks like this:

```
          val = Read_AFE_1Reg((uint16_t)P3_PFmeanT);
          if ( (val & 0x8000) == 0x8000 )
          {
            val = (~val) + 1;
            error_type = 2;
          }
          else
          {
            error_type = 1;
          }
          val = (val & 0x7FFF);
          //ptr =&VAFE.RMS[PFt];
          Calculate_PowerFactor( ptr, val );
```

Then Calculate_PowerFactor is:

```
void  Calculate_PowerFactor( uint32_t *rmsptr, uint32_t rmsval )
{
  uint32_t  m;

  m = (rmsval & 0x7FFF);
  *rmsptr = (m % 10000) / 1000;
  *rmsptr = *rmsptr << 4;
  *rmsptr |= (m % 1000) / 100;
  *rmsptr = *rmsptr << 4;
  *rmsptr |= (m % 100) / 10;
  *rmsptr = *rmsptr << 4;
  *rmsptr |= (m % 10);
}
```

And they do something similar to get most metering values. I'm puzzled as to why, since you're absolutely correct. The values can be negative when there is an inductive load. I previously corrected the other power values.

Either way, I'll remove the bitwise lines in the library.

gbeardall, 2019-11-10:
That's some weird looking code!
As far as I can see it's converting the power factor to BCD in rmsptr

Do you have a link to the original Atmel example code you referenced, so I can take a look?

gbeardall, 2019-11-10:
Just tried it now with an inductive & a capacitive load and the sign of the power factor now changes appropriately.

CircuitSetup, 2019-11-10:
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

Yes, it is. They do some things in a very roundabout way, and theres a lot of repetative code. Maybe they wanted to do bit shifting for some reason, and that's why it all had to be positive? I'm not sure. This is a 16 bit register, but there are ones that are 32, where bits do need to be shifted because the values are stored in 2 different registers.

It's not available anywhere (Microchip had it behind a login that I had to request access to) so I'll have to post it somewhere private.

CircuitSetup, 2019-11-10:
> Just tried it now with an inductive & a capacitive load and the sign of the power factor now changes appropriately.
>
> Although, it is a bit confusing as the sign does also change depending on which direction you have the current clamp.

I did the same and it looks correct.

CircuitSetup, 2019-12-03:
Corrected in https://github.com/CircuitSetup/Split-Single-Phase-Energy-Meter/releases/tag/v2.5.5

Closed 2019-12-03.

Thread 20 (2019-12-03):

240V and 60Hz?

CircuitSetup, 2019-12-03:
But what about 240V and 60Hz?

_Originally posted by @netomx in https://github.com/CircuitSetup/Split-Single-Phase-Energy-Meter/issues/7#issuecomment-537653582_

chaseadam, 2020-10-02:
I can confirm this board and software works for *split* phase 240V at 60hz in North America (most people think there are 2 phases when it is split phase, but true 2 phase is quite rare as if you have more than 1 phase, you generally have 3 phases 120° offset). Just make sure you set the calibration values as recommended for 60hz and the chosen transformer.

netomx, 2020-12-28:
> I can confirm this board and software works for _split_ phase 240V at 60hz in North America (most people think there are 2 phases when it is split phase, but true 2 phase is quite rare as if you have more than 1 phase, you generally have 3 phases 120° offset). Just make sure you set the calibration values as recommended for 60hz and the chosen transformer.

What transformer did you use? I havent found anything with 240V

chaseadam, 2020-12-28:
I stuck with measuring just one of the two legs for the voltage (so a 120v transformer).

Ideally each leg is measured individually. Measuring between the legs (240v) is no better than measuring one leg as current flows through the neutral in a split system.

I do not have the reference, but I recall reading that there is negligible gain by measuring individual legs. I can imagine if you have a severely unbalanced panel it may make a difference.

missmah, 2021-12-04:
I've seen 125V on one phase and 108V on the other phase (at the same time) on my panel in real scenarios. Also, when combined, I've commonly seen 205-218V, so likely 120* offset (the building is 3-phase, each unit gets 2 of the three phases). In any case, I think metering one phase and multiplying by a constant would be very inaccurate in my situation.

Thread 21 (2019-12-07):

Password Reset

catalinalb, 2019-12-07:
Hi

How can I reset the login password and admin user? I did set them up but the forget about them.
I think the only way would be to update the ESP from the Arduino IDE can someone let some instructions about this procedure?

Thank you
Catalin

CircuitSetup, 2019-12-08:
To do this you'll have to reset things to default. This will erase any saved settings, like wifi configuration and connections.

1. Remove the ESP32 off of the pcb
2. Power the ESP32 via USB (If you want, open a serial window to see what it's outputting)
3. Connect Gnd (upper left) with GPIO3 (5th pin from upper left) with a jumper wire
4. Wait 15 seconds (10 minimum, but 15 to be sure). If you have a serial window open, it'll say "factory reset"

catalinalb, 2019-12-08:
It Worked!!

No need to desolder the ESP since it´s connected with pin headers (plug&play) :)
Baudrate 115200
Here is a link with the pinout: (GPIO3 also labeled RX)
https://www.flickr.com/photos/jgustavoam/40089095211

Thank you,
Catalin

CircuitSetup, 2019-12-08:
Great! Glad it worked for you

Closed 2019-12-08.

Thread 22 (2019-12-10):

Feature Request: RSSI value MQTT feed

gigawatts, 2019-12-10:
I originally asked about this in #17 but it probably makes more sense to track in its own thread.

It would be awesome to add the WiFi RSSI as one of the values available via MQTT, so it can be graphed/monitored over time.

CircuitSetup, 2019-12-23:
That is a good idea! It shouldn't be that hard to add this to the feed.

fredkehler, 2020-01-16:
I have added rssi to my mqtt, if you replace your mqtt.cpp with this file and recompile you should be good,
Note:  I was having trouble losing wifi connection, and took out the blocking loop on mqtt reconnect which solved my problem... if you need it, the code is still there, just remove the rems....

[mqtt.zip](https://github.com/CircuitSetup/Split-Single-Phase-Energy-Meter/files/4072035/mqtt.zip)
cheers

gigawatts, 2020-01-16:
I assume that will make it into an upcoming binary release as well? My WiFi connection to the ESP is just on the edge of "usable", where it will work for several days, then fall off the network and fail to ever re-join, requiring a power-cycle to bring it back online. Is that similar to the trouble you are experiencing?

My plan was to setup another AP closer to the ESP so it would stop falling off the network, but it sounds like you may have corrected the issue in code?

fredkehler, 2020-01-16:
your experience sounds very similar to mine... I moved my esp to within 5ft
of my AP and still couldnt keep a connection going for even 24 hrs...
my mods at this point have been working for 8 days without a hickup... so I
am cautiously optimistic... I would gladly share my code... but I am not
familiar with using github and how the versioning system works... I have
kept mine versioned as 2.5.5fk just to differentiate it from the main
code...
are you setup to compile on arduino or would you just like to try the
binary?

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

--
Alfred (Fred) Kehler ( fred.kehler@gmail.com)

gigawatts, 2020-01-17:
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

I responded to your comment before realizing you were not the original code author 🤣 That's why I originally mentioned the binary release, then removed it once I looked at your name.

I do have PIO setup to compile for ESP chips, I'll give your mods a shot soon. My ESP has been stable for the last several days after setting up a closer AP, but I would rather not have to run a second AP if I don't have to.

The easiest way to contribute back to the project is just to hit the fork button at the main repo, edit whatever you like in your own copy, then it's pretty easy to "compare" back to this repo and submit a pull request. It can all be done from the web UI if you are not comfortable with git commands yet. If the author accepts your changes, they can tweak version numbers before merging.

fredkehler, 2020-01-17:
appreciate your comments... what would you suggest as the best way to fix
this?  my github account does not appear to allow me to use the 'fork'
option ( says I am not a member of an organization?) and I don't see any
options to allow me to delete or retract what I have submitted...?

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

--
Alfred (Fred) Kehler ( fred.kehler@gmail.com)

gigawatts, 2020-01-17:
It looks like you figured it out yesterday? Your fork is here: https://github.com/fredkehler/Split-Single-Phase-Energy-Meter

CircuitSetup, 2020-02-21:
Thanks @fredkehler - this is in the latest version.

I also fixed the issue with the reconnect blocking everything. There were extra 0s on the counters. Instead of 5 seconds, it was trying to reconnect continuously for 14 min, then would have tried again every 28 min. This was likely causing things to lock up, and/or just blocking everything from running.

gigawatts, 2020-02-22:
Is there anything special we need to do with the spiffs file in the latest release? Do we need to upload both src.ino.esp32.bin and src.spiffs.bin, but in a certain order?

CircuitSetup, 2020-02-24:
> Is there anything special we need to do with the spiffs file in the latest release? Do we need to upload both src.ino.esp32.bin and src.spiffs.bin, but in a certain order?

The order shouldn't matter. The spiffs update just changes some text for default calibration values, so it's not really necessary either.

Closed 2020-02-21.

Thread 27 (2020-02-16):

Periodic disconnects - add scheduled reboot?

amil109, 2020-02-16:
Hi CircuitSetup,

I'm really enjoying my Split Single Phase Energy meter, with only one issue - every now and then, approximately every 10 days, it disappears from the network, and requires a restart.

I've had other ESP devices in the past that needed a periodic reboot (once / week, etc) to perform reliably - I could never quite get to the bottom of what the issue was, and didn't have the time to resolve it 'properly' either. After reading a few things online, I thought maybe the meter might be swapping APs or something (multiple APs in the house), and having issues, but I've switched it to an SSID that is only on one AP (with only the ESP on the SSID), so it should not be this.

Please note that I have read "Using web interface and/or leaving it open causes ESP32 memory leak/crash" - I'm running v2.5.5, so should not be this either (although I do always use Chrome).

Right now, I've got the meter connected through a smart outlet, so if it goes down I can disconnect and reconnect it remotely, but I would rather have this automated on the ESP itself.

Can you help with solving this issue? I can certainly send logs (let me know how), or, alternatively, could you add a scheduled reboot to the WebUI? I think this would 'solve' the issue.

Has anyone else reported this?

Kind regards,

Andrew Mills

CircuitSetup, 2020-02-16:
Hi @amil109 - I'm sorry it's giving you issues! It looks like you have the kit that came programmed. When you updated to v2.5.5, did you compile it, or just load the binary via the web interface? I ask because if you compiled and the libraries weren't up to date, that could still cause memory leak issues.

It seems that some people still do have this issue, but it's usually related to the signal strength, and the ESP32 being able to reconnect to the AP when it looses the connection. After trying to reconnect, it will go into AP mode, which uses a lot of power. It can sometimes cause the brownout detector to trip, and the ESP32 to freeze.

What specific AC transformer are you using? Is it at least 1000mA?

amil109, 2020-02-16:
Hi @CircuitSetup ,

Thanks for the quick response!

I used the binary to flash via the web interface.

My AC transformer is 2000mA, it's one for 230V, not listed, so I've got a calibrated value in the WebUI.

The ESP is very close to my router (~1m, they're in the same cupboard) I don't know if this might be an issue?

Kind regards,

Andrew

CircuitSetup, 2020-02-17:
Your transformer is outputting enough current. What is the voltage output. Alsom is it one that plugs into the wall? Some people have had some issues with transformers that do not have any type of filtering caps or protection from voltage spikes.

The closer to ESP32 is to the AP, the better. That's probably not the issue either.

amil109, 2020-02-17:
Hi @CircuitSetup ,

It is a 'wall wart' type transformer, 9V AC 2000mA output - this is the [link](https://www.poweradaptorsuk.co.uk/2000ma_9v_AC_AC_Power_Adaptor_p/ta20009ac.htm).

If you can recommend a better / different brand for use in the UK, please let me know - I will happily purchase it!

Kind regards,

Andrew Mills

CircuitSetup, 2020-02-21:
There isn't too much detail about how that transformer works on that page, but I can see that it's passed UK standards, so it's probably doing what it is supposed to do.

In EmonCMS, you can also take the available memory and make that an input, graph it, and see if it running out of memory. If it is there is an unexpected leak somewhere. If not, then it's likely a connection/power issue.

If it is a power issue the only other suggestion I would have before trying a different ESP32, is to put a 10uf to 50uf through hole style capacitor between the 3v3 and gnd pins on the ESP32. This can either be soldered in or put in the pins that hold the ESP32 on the underside of the adapter board.

Let me know what you find.

CircuitSetup, 2020-02-21:
One other thing - Are you sending any data via MQTT? I just fixed a bug with that when it got disconnected.

amil109, 2020-02-22:
Yes - I am sending MQTT data to my OpenHab instance - should I stop this? TBH I'm not using it right now. I'm also happy to flash a Beta with the fix if you have it?

CircuitSetup, 2020-02-28:
I fixed an issue in the [latest release](https://github.com/CircuitSetup/Split-Single-Phase-Energy-Meter/releases) that would cause MQTT to try to reconnect for 14 min straight if the connection was lost. It was only supposed to do this for 5 seconds, then every 10 seconds. This could cause the ESP32 to lock up, which may be what you are experiencing. Please flash the latest bin to the ESP32 via the web interface, and let me know if this helps.

amil109, 2020-02-29:
I've flashed it now - I'll keep you posted!

Prior to this, it worked for ~15 days without issue, so it might be a hard one to detect. If I kill my MQTT server and wait, that should replicate it right? I can certainly try that. It's completely possible that the energy monitor failures were aligned with me messing around with the MQTT server, and I just didn't realise in the past.

amil109, 2020-03-07:
Hi @CircuitSetup,

My device has been operating without issue for a week since flashing - I think if it lasts one more week without issue we can consider this topic closed! Thanks very much for your help. I'll post if I have any issues in the next 7 days.

CircuitSetup, 2020-03-09:
Great! I'm glad to hear it's working better for you now.

McGeaverBeaver, 2020-03-15:
Hi @CircuitSetup  I got my device and it's great. Works really well, besides the disconnects. I thought it was my wifi signal as my AP was very far.. I have since got another AP in the mix ( Unifi AP Setup, network is solid ) and I get a great -40 dBm connection.  Yet at random.. It can happen more than once a day, but it's at minimum once a day I will need to unplug the power supply and plug it back in.. If I am running a consistent ping it comes back really fast, 3-5 seconds. Is that even a full boot? Any idea what could be going on?  I am only running Emoncms also .. No MQTT from this device.

Free RAM: 213K
Flash Size: 4096K
Version: v2.5.7

McGeaverBeaver, 2020-03-21:
@CircuitSetup John, Could you please advise.. It's really annoying this is not a stable device..

CircuitSetup, 2020-03-21:
Sorry @McGeaverBeaver, I overlooked your initial message.

Did you update the firmware from the provided bin or did you compile from source?

Also, when it randomly disconnects is there a browser window open anywhere?

It may help to collect data for available ram in emoncms to see if the esp is running out, then freezing. That would indicate a memory leak. I've seen this happen when the software isnt closing connections correctly.

McGeaverBeaver, 2020-03-21:
@CircuitSetup No problem.. I have updated the FW from the provided bins.. You have 2 , do I need both uploaded? I have done that src.spiffs & src.ino.esp32.. It's on v 2.5.7 and said successful after both uploads..

No browsers opened when this happens. I only have it logging to Emoncms..

I can also check the lights before I reboot it next time this happens but I think the red light is on and no blue light..

is a  reboot normal to only take a few seconds? unplug power supply from wall and plug it back in..
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
CircuitSetup, 2020-08-08:
@genehand I'm sorry its still giving you issues. I believe the cause is a combination of being able to stay connected to an AP, and the error handling around that. I'll continue to improve the software.

By the way, you can load ESPHome on the meter esp32 to see if that improves stability. Details here: https://next.esphome.io/components/sensor/atm90e32.html

scfigg, 2020-10-06:
I'm having issues still as well. RSSI is -72 typically. I'm on 2.6. I'll go check on it after a few days, and it'll be frozen, so it's missing data. Hard for me to calculate monthly costs when I'm missing multiple days at a time. I've had this issue since purchasing it. I've gotten to the point that I don't even rely on it anymore.

McGeaverBeaver, 2020-10-06:
@scfigg yep still an issue.. He mentioned my WiFi also.. I went out and purchased another AP ( A Unifi AP ) - It's now VERY close to the device, on it's own SSID 2.4 broadcasting only from that AP with all the options toggled around to see if that would change stability..  I also have a  Konnected Alarm Panel and it uses the same ESP wifi chip and I have NO issues with this device.

It's software issue here.

My fix, I put a script to ping it on HA and if it can't reach it , it cycles a smart switch I have the transformer of the energy meter plugged into..  The smart switch does not change readings, and the reboot is so fast that the data loss for that few seconds is not really a big deal..

scfigg, 2020-10-06:
Thanks. I was actually just contemplating both of those things - whether or not to put an AP right next to it (I have some nice Ubiquiti network setup in my house, so signal is generally not an issue). I was also thinking of plugging a smart switch into it and forcing reboots.

Care to share your HA scripts for ping/reboot when you get a chance? I'm sure I could figure it out, but if you have something already setup, that would be much easier.

McGeaverBeaver, 2020-10-06:
Yea man, WiFi not the problem here..
Let me get what I'm doing for the reboots.. I don't recall from the top of my head also what I am doing lol

McGeaverBeaver, 2020-10-06:
@scfigg  lol it works but man I was lazy!  I just have a ping sensor setup in HA , and then an automation that checks every 5 minutes to see if the ping is still alive, if it's not.. toggle power.. I had it on an actual TOGGLE before but I find that for some reason things would be on or off when I didn't want them so I just have it toggle but with an ON/OFF

configuration.yaml

  - platform: ping
    name: emonesp_wifi
    host: 192.168.99.248
    scan_interval: 60

automations.yaml

- id: '123456'
  alias: Toggle emon ESP
  description: ''
  trigger:
  - minutes: /5
    platform: time_pattern
  condition:
  - condition: state
    entity_id: binary_sensor.emonesp_wifi
    state: 'off'
  action:
  - data: {}
    entity_id: switch.emondumbpower
    service: switch.turn_off
  - delay: 00:00:02
  - data: {}
    entity_id: switch.emondumbpower
    service: switch.turn_on

scfigg, 2020-10-07:
Thank you! That saved me a bunch of time :) I'll give this a run and see how it holds up. Thank you! Now just to figure out how to estimate monthly energy bill cost in HA!

CircuitSetup, 2020-10-08:
I'm sorry you guys are still having issues with connectivity. I am working on a new version of EmonESP, that hopefully will remedy these issues. There's a lot of things that have been re-worked, and there's a lot of new features too.

In the meantime, since I see Home Assistant is being used, have you considered trying [ESPHome](https://esphome.io/components/sensor/atm90e32.html)?

McGeaverBeaver, 2020-10-08:
No worries John, The workaround is easy enough and reporting has been great since.

Yes I have briefly looked at ESPHome and I understand with this we can use to identify single devices out being on ESPHome, but I honestly don't know where to start and haven't looked very hard.. I did enjoy the ease of plug and play with your device.

Looking forward to the update! thanks again John.

AltusBaard, 2020-11-03:
Not sure if this helps, but I built a very slimmed down version of the code straight on an ESP32 with almost the only external library being wifimanager. I used it in such a way that it would put the device in AP mode if it ever lost connection.

From what I could see, every few days the device would stop broadcasting data and go into AP mode, so maybe there is an issue in the Wifi library, just an idea, maybe it helps, maybe not.

kendive, 2021-03-02:
Any updates yet above 2.6? Still having random lock up and freezes on this Solar Setup?

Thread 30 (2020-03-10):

Voltage * Current != Active Power, is that correct?

manutenfruits, 2020-03-10:
I am using the [Expandable 6 Channel ESP32 Energy Meter](https://circuitsetup.us/index.php/product/expandable-6-channel-esp32-energy-meter/) with 2x [120A/40mA Current Transformer YHDC SCT-016](https://circuitsetup.us/index.php/product/120a-40ma-current-transformer-yhdc-sct-016-with-3-5mm-jack-16mm-opening/) and **ESPHome**.

The problem I have is that while Voltage and Current match that of my golden Kill-A-Watt, the Wattage doesn't equal Voltage * Current.

Reported by the sensor:
Voltage Phase A: 123.37 V
Current A: 0.53 A
Active Power A: 8.27 W

Calculated
123.37V * 0.53A = **65.38W != 8.27 W**

Am I understanding this incorrectly? I know I'm using ESPHome but I want to understand I got the theory right first.

CircuitSetup, 2020-03-10:
What do you have for your config file in ESPHome?  Also, what version of the meter?

It looks like one of the CT's is backwards. Normally one of the currents would report as negative if this were the case, but if you have a multiplier in the config, it'll come out as positive. It could also be on the opposite

There is another variable that the meter takes into account when calculating active power. Power factor. (Voltage * Current) * Power Factor = Active Power

A perfect power factor, that of a pure resistive load, is 1.

manutenfruits, 2020-03-10:
So indeed I had both clamps with the arrow pointing towards the distribution box with a `multiply: -1` filter, I fixed it and removed the filter but I can't tell if anything changed. I added a Voltage on phase_b with the gain just to have a second measurement (reports similar voltage).

Voltage A | 123.27 V
Current A | 0.78 A
Active Power A | 13.82 W
Voltage B | 123.32 V
Current B | 1.02 A
Active Power B | 102.81 W

How is power factor calculated? is it a parameter or is it something that the chip can measure?

Here is my config, and I'm on the `dev` channel

```

sensor:
  - platform: atm90e32
    cs_pin: 5
    phase_a:
      voltage:
        name: "Voltage A"
        id: voltage_a
      current:
        name: "Current A"
        id: current_a
      power:
        name: "Active Power A"
        id: active_power_phase_a
      gain_voltage: 7314
      gain_ct: 21111
    phase_b:
      voltage:
        name: "Voltage B"
        id: voltage_b
      current:
        name: "Current B"
        id: current_b
      power:
        name: "Active Power B"
        id: active_power_phase_b
      gain_voltage: 7314
      gain_ct: 21111
    frequency:
      name: "Line 1 Frequency"
    line_frequency: 60Hz
    gain_pga: 2X
    chip_temperature:
      name: "Temperature"
    update_interval: 5s
  - platform: template
    name: "Calculated Power A"
    id: calculated_power_a
    unit_of_measurement: W
    update_interval: 5s
    lambda: |-
      return id(voltage_a).state * id(current_a).state;
  - platform: template
    name: "Calculated Power B"
    id: calculated_power_b
    unit_of_measurement: W
    update_interval: 5s
    lambda: |-
      return id(voltage_b).state * id(current_b).state;
```

manutenfruits, 2020-03-10:
Okay I got it all figured out, there are some gaps on the esphome docs but I added the `reactive_power` and `power_factor` measurements and now it should add up. Thanks for your help!

CircuitSetup, 2020-03-11:
Great! Glad you figured it out!

FYI, Power factor is calculated by the meter. [Here's the math of how it is done.](https://www.allaboutcircuits.com/textbook/alternating-current/chpt-11/calculating-power-factor/)
(true power = active power) So you can see why if current is negative, that would throw everything off.

Closed 2020-03-11.

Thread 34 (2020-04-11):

No readings from CT2

neilrees, 2020-04-11:
Hi,

I'm attempting to install the sensor in the UK on a 240v single phase supply.  The intent was to monitor the mains supply with CT1 and the PV Generation with CT2  (and use this to calculate amount being imported, exported, and consumed)

The meter is connected up and I'm getting good readings from CT1 but I just get no readings from CT2.

I've flashed ESPHome firmware onto it using this yaml:

```
esphome:
  name: [name]
  platform: ESP32
  board: nodemcu-32s

spi:
  clk_pin: 18
  miso_pin: 19
  mosi_pin: 23

sensor:
  - platform: atm90e32
    cs_pin: 5
    phase_a:
      voltage:
        name: "Line Voltage A"
      current:
        name: "CT1 Current"
      power:
        name: "CT1 Active Power"
      gain_voltage: 7243
      gain_ct: 25498
    phase_b:
      voltage:
        name: "Line Voltage B"
      current:
        name: "CT2 Current"
      power:
        name: "CT2 Active Power"
      gain_voltage: 7243
      gain_ct: 25498
    frequency:
      name: "EMON Line Frequency"
    line_frequency: 50Hz
    gain_pga: 2X
    update_interval: 2s
```

If I switch the two CT clamps over the problem remains on CT2.

I get the following log output from ESPHome:

```
[14:17:24][D][sensor:092]: 'Line Voltage A': Sending state 246.80000 V with 2 decimals of accuracy
[14:17:24][D][sensor:092]: 'Line Voltage B': Sending state 0.01000 V with 2 decimals of accuracy
[14:17:24][D][sensor:092]: 'CT1 Current': Sending state 4.06200 A with 2 decimals of accuracy
[14:17:24][D][sensor:092]: 'CT2 Current': Sending state 0.00100 A with 2 decimals of accuracy
[14:17:24][D][sensor:092]: 'CT1 Active Power': Sending state 934.28766 W with 2 decimals of accuracy
[14:17:24][D][sensor:092]: 'CT2 Active Power': Sending state 0.00000 W with 2 decimals of accuracy
[14:17:24][D][sensor:092]: 'EMON Line Frequency': Sending state 49.96000 hz with 1 decimals of accuracy
```

Any ideas on what I've missed in order to get CT2 working?

CircuitSetup, 2020-04-11:
Change phase_b to phase_c.

neilrees, 2020-04-11:
That's it!  Thankyou!

I was working from the example on ESPHome's site:
https://esphome.io/components/sensor/atm90e32.html

But to be fair, the example linked to from this project is correct:
The guidance linked here is correct https://github.com/digiblur/digiNRG_ESPHome/blob/master/digi_nrg_2chan32.yaml

Thanks!

CircuitSetup, 2020-04-11:
Yeah, the first version of the docs were wrong since this meter doesnt use phase_b. I corrected it in https://next.esphome.io/components/sensor/atm90e32.html

Closed 2020-04-11.

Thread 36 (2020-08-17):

Can we measure current with one CT only?

aaamitsingh, 2020-08-17:
In the description you have mentioned that two CT in opposite direction is required to measure the current.  Is this possible to do the same with the help of only one CT?

CircuitSetup, 2020-08-17:
Do you mean 2 wires in 1 CT? If so, yes, this can be done as long as the CT is large enough and the 2 wires are fed through it in opposite directions. If they are the same direction power factor will be off and power will be calculated incorrectly.

aaamitsingh, 2020-08-17:
Thanks for your response.  No I mean that I want to measure current with the one CT only. I don't want to use the second CT in opposite direction.
Is there any way to read the pf and power correctly with one CT only?

CircuitSetup, 2020-08-17:
Do you have split single phase power or single phase?

aaamitsingh, 2020-08-17:
Single phase

CircuitSetup, 2020-08-17:
You shouldn't have a problem only using 1 CT then. The meter will output power factor and power for that channel only.

The 1 opposite CT only applies to split single phase power.

aaamitsingh, 2020-08-17:
Great that means I can also monitor the current consumption of 2 different device with single board using 2 different CT?

http://www.hlktech.net/product_detail.php?ProId=64
Can we use the above ultra small capsule transformer instead of mentioned bulky transformers?

CircuitSetup, 2020-08-17:
You can as long as you are not reading the total power. There are outputs for single power channels in the Arduino library, and with ESPHome. EmonESP, by default, outputs the total wattage.

No, that power module will not work. It has to be an AC to AC transformer with at least 1000mA, and between 9-12VAC output.

aaamitsingh, 2020-08-18:
Thank you so much for clearing all my queries and fast response.  I'm closing this issue now but once we develop this product I will share the feedback with you.

Thank you one again.

Closed 2020-08-18.

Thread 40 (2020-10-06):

Verifying Power Factor values

chaseadam, 2020-10-06:
I believe with the Microchip IC used, all ADC values are captured simultaneously. This would imply that power factor calibration is largely unnecessary unless the AC-AC transformer is introducing some phase delay. I have a very low power factor seemingly correlated to the output of my PV microinverters. It even is close to zero for nearly 30 minutes.

Has anyone else reported similar experience with solar inverters?

What has been your experience with phase shift settings? Suggestions for calibration/validation?

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

CircuitSetup, 2020-10-06:
Some questions...

1. Are you measuring the use from your PV system?
2. Do you have a split single phase electrical system?
3. If so, are you measuring both phases?

It makes sense that PF for mains would go negative if you're exporting power to the grid. When it's at 0 you aren't importing or exporting power - only the PV power is being used. PF slowly increases as you use less PV power, and more grid power.

chaseadam, 2020-10-06:
Seems like everything is working as intended then.

I am not measuring the PV system yet (I have the second board, I just haven't installed it yet)

Yes, I have a split single phase 240v 60hz (North American houshold) with 200A service.

Yes, I am measuring both legs of the split phase.

I understand that the PF would go negative on "export" of PV power, but I don't follow why the PF gradually transitions through 0 as the PV generation goes down. Sounds like I need to do more research.

chaseadam, 2020-10-08:
A bit of research showcases why the Power Factor drifts through 0 as PV generation goes up. The key is the PF is the *relationship* between real and apparent power. Changing the "real" power value with a device with a PF near 1 (i.e. water heater) or -1 (PV inverter) can significantly impact PF without any affect on apparent power.

If apparent power stays the same (is not corrected) and real power is reduced (either by PV generation with a PF of 1 or by unplugging a device which is consuming real power with a PF of 1), the *ratio* of real to apparent power changes, reducing power factor. The triangle diagram vs the "phase" presentation helped me understand it.

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

https://www.sma-sunny.com/en/bad-power-factor-a-reason-to-oversize-your-inverter/

While there are PV inverters which can also actively correct PF, I do not have a model which supports that function.

CircuitSetup, 2020-10-08:
Thanks for posting that! Very good explanation.

Closed 2020-10-06.

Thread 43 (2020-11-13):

What Calibration setting value to use for 200A CT?

JPElectron, 2020-11-13:
Per 7. Calibration Settings...

25498 - SCT-013-000 100A/50mA
39473 - SCT-016 120A/40mA (default)
46539 - Magnalab 100A

...so what do I put if the CT sensor is this 200A version: https://circuitsetup.us/index.php/product/200a-100ma-current-transformer-yhdc-sct-024-24mm/

Also, if CT1 reports - (negative) value and CT2 is + (positive), does one need to be flipped?
Documentation is contradictory...

Picture shows arrows pointing opposite ways on each leg of split phase

but... troubleshooting says...

I'm getting a very low power factor reading, and wattage seems off
One of your CT clamps is probably backwards - flip it around. **_If they are both oriented in the same direction, this will not happen._**

CircuitSetup, 2020-11-13:
Thanks for pointing out the fact that this value is missing. I'll have to add it to the documentation, and update things to not contradict.
It should be around 26315

The CT that is reading negative should be turned around.

fjmohammed, 2021-01-03:
I am planning on using the CT referred here (https://circuitsetup.us/index.php/product/200a-100ma-current-transformer-yhdc-sct-024-24mm/). Since they have the TVS diode, I do not need to sever the burden resistor, correct?

CircuitSetup, 2021-01-11:
> I am planning on using the CT referred here (https://circuitsetup.us/index.php/product/200a-100ma-current-transformer-yhdc-sct-024-24mm/). Since they have the TVS diode, I do not need to sever the burden resistor, correct?

No, you don't need to (and shouldn't) sever the burden resistor.

giulianomotter-trucks, 2021-02-03:
Hello,

> It should be around 26315

Could you give some insight about how you come up with these values?

The calibration process suggested in the AppNote needs an input of the value read on reference meter, and also value read on the ATM90 chip, so I'm kind of curious how can you pre-define these values?

Thank you.

JPElectron, 2021-02-03:
The 26315 is a starting point...

You need to calibrate it by putting a clamp amp meter around the mains cable, then manually adjusting the 26315 number +/- until the amps measured by your meter and the emonESP match - at least close.  You can see the live value as read by the emonESP by hitting it's IP in a browser directly.  It's sorta a pane in the butt cause obviously your power use is fluctuating in the house as you do it.

In my case, using the emonESP, with the 200A CTs it shipped with, my values turned out to be as follows...

Voltage: 3920
CT1: 26100  (I found 26315 to be off a bit)
CT2: 26100
Freq: 4485
CT Gain (PGA): 21  (I found 42, as the webpage suggests to be way off)

Some math is being done against the 26315 number to calculate the amperage displayed.  That's why adjusting this number +/- helps make it more accurate to actual amps being used.  There are likely differences in the way the CTs are manufactured, but also how you attach them (snug to the mains cable), and electrical noise that makes the case for calibration against another known source (amperage clamp style meter) necessary.

Side note - at some point I flashed mine with the latest firmware file (more difficult to find than it needed to be) and ended up "downgrading" mine to v2.6 whereas it shipped with v2.6.1  :(

Closed 2021-01-11.

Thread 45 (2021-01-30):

Reading 65k from voltage register

TSMotter, 2021-01-30:
Hello, I'm trying to read significant data from my mains power system using a custom ATM90E36 based board I've designed.

I'm using your repo as a reference, even though the chip used here is ATM90E32, and mine is 36.

On your main readme file you mention about readings on voltage register being something like 65k and mention that this normally indicates that something is not hooked up or working correctly which sugests to me a hardware problem.

I'm currently getting this kind of reading. Was wondering if you have some troubleshooting tips for me, or if you could even help me with a simple hardware review of my board/setup.

Thanks.

CircuitSetup, 2021-01-30:
If you're getting all 65535 as output, it's either not communicating via SPI, or there is a pin on the IC that is not grounded properly.

Make sure your MCU is using the correct SPI mode, and that the pins are all pulled high.

For the 36, you have to ground the DMA pin (36) if you're not using it. I made the mistake of not doing this when using that IC instead of the 32 for another project.

TSMotter, 2021-01-30:
Thak you for your reply.

Unfortunately that is not the case. I can communicate with the IC. I see all communication being made through a Logic Analyzer. So it's not SPI related. I can read/write to all registers with no problem.

The readings I'm getting on voltage are something like 65505, not all the way to 65535.

I've attatched a sketch of my schematic, if you would be kind enough to take a look and see if you have any observation I'd be very grateful.

Some information:
- Mains is 3 phase 127V 60Hz.
-  CT is ZMCT116-A (2000:1)
- PT is ZMPT101B (1000:1000)

If pdf doesn't work, here is a link to images of my schematic as well: https://imgur.com/gallery/GHqTz9C

Thanks again.

[M90E36A.pdf](https://github.com/CircuitSetup/Split-Single-Phase-Energy-Meter/files/5898876/M90E36A.pdf)

TSMotter, 2021-01-31:
Hello,
I just felt like writing this.... I understand that I opened an issue on your repo with something that is not particularly related to your project and I'm sorry about that...

It's just that I'm trying to gather every piece of info I can get on these IC's on the internet with people who have already used it before, since Microchip documentation is poor and confusing.

If you could perhaps share any resource (hardware/firmware) about this side project you mentioned using the 36, you'd still be helping me **a lot** and it'll probably be a much simpler process then the other way around, where I be asking you to review my Hw/Fw...

Anyways... Thank you again and sorry for the inconvenience.

CircuitSetup, 2021-02-04:
No problem! Your schematic looks okay to me.

It sounds like SPI is communicating properly with the ATM90E36 since you're getting a number just below 65535.

What do you have set for the voltage gain?

Also, I recently updated the Arduino library for the 36 here: https://github.com/CircuitSetup/ATM90E36
See what was changed from the original: https://github.com/CircuitSetup/ATM90E36/commit/6e3c9c6cc3c41f6518bee7a50c7359a5e861296f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
Are you using this version?

TSMotter, 2021-02-06:
Thanks for sending the references bud...

> What do you have set for the voltage gain?

That's something I dont fully understand. How can you start with a value for the voltage gain, if it's value depends on user inputing referente meter reading. Currently what I do is that I start with the default voltage gain value (0xCE40), and then run a calibration process on the go, where I input reference meter reading value, my function makes a series of X (currently 20) readings of the ATM voltage value, takes the mean value and write to the voltage gain register the resulting value, according to the process sugested on AppNote section 4.2.6.

But as my voltage readings from the register are so off, I'm thinking I have a hardware issue.

I'll take a time to go thru your ATM90E36A repo, the simulation and the .xls file should help me a lot.

Thank you again.

Closed 2022-03-25.

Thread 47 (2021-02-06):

fried split circuit v1.4 rev 2

chaseadam, 2021-02-06:
Installation running for a bit over 4 months paired with a Lolin knockoff esp8266 reporting to local emon. It was in "open air" installation (sitting on shelf next to power panel).

Smelled the classic electrical burning smell after breakfast and found the power meter off and a bit "toasty" (not the breakfast kind).
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

I am using one of the preferred high quality power supplies
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

I haven't done much investigation yet, but will keep this thread up to date.

I suspect maybe the low quality dev board was pulling too much current and slowly damaged the regulator to the point of catastrophic failure.

Curious for others' hypotheses as well.

CircuitSetup, 2021-02-06:
From the looks of it, the rectifier and power supply failed on the meter. I've only seen this happen once before, and the cause was likely because of a component failing.

If you send me your order number I can send a replacement.

chaseadam, 2021-02-06:
responded via https://circuitsetup.us/index.php/contact/

Closed 2021-02-06.

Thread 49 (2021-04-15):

Calibration emonESP from Russia

skribbl84, 2021-04-15:
Hi!
Two weeks ago I received a CircuitSetup Split Single-phase Energy Meter with two transformers 2x 16 mm round YHDC SCT-016 120 A CT Sensors.
I can’t calibrate Energy Meter for a long time.
Through a lot of trial and error, I got an approximate tension. In our electrical network, it is 230v.
In the emonESP Voltage field, I entered 4540. But I strongly doubt that this is the correct value.
I am using a 9v AC transformer.
In the field of calibration of transformers CT1 and CT2, I enter 39473.
But the power values   are not strong.
Please tell me how to correctly calculate the data for calibration.

CircuitSetup, 2021-04-17:
The calibration procedure for voltage is here:  https://github.com/CircuitSetup/Split-Single-Phase-Energy-Meter#voltage-procedure

You will likely see a calibration value for voltage that is double the default, so start with 9080. Also make sure you have the field for frequency set to 50Hz, which is 389.

Closed 2022-03-25.

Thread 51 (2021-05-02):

support for high frequency AC transformer?

asalexsu, 2021-05-02:
Hi,

I couldn't find any outlets near the electrical box so I bought a 120V to AC 12V transformer, something like this
https://www.aliexpress.com/item/1005001682049282.html?spm=a2g0s.9042311.0.0.52cb4c4dN5ulqY

When I was testing with a multimeter it doesn't read anything(shows as 0). The seller said I will need to get a reading with a high-frequency multimeter

In ESPhome the voltage reading varies between 1.8V to 2.3V with a gain of 29462

Does this mean it doesn't support reading from high-frequency transformers and I will need to hard code the voltage for other uses?

Thanks,
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

CircuitSetup, 2021-05-02:
Some questions:
- Is the transformer hooked up directly to a breaker in your panel?
- Is so, is it a single pole, and is is connected to the breaker and neutral bus bar?
- How are you measuring the output of the transformer? Is the multimeter set to AC?

asalexsu, 2021-05-02:
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

- Yes, the transformer is directly hooked up to a breaker in the panel
- Yes, it is a North American single pole breaker, I will attach a picture below
- I measured it by setting the multimeter to AC 200V, checked that the input reads 124.8V, output reads 0.3V

The transformer in black is the one powering the circuit board, the bulky one below is for security system

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

CircuitSetup, 2021-05-02:
Everything looks like it is hooked up properly. I would bet the transformer is defective if it's not outputting at least what it says it should. I'm surprised it's able to power the meter at all.

asalexsu, 2021-05-07:
I had some more time today and did some testing. The transformer seems to be using a high switching frequency. My multimeter reports in the 24k Hz - 25k Hz range as oppose to 60 hz.

Do you know if I can simply change the frequency setting in esphome to that number or would I have to get another transformer? Do you have any recommendation on 120v - 9/12V transformer that directly connects to the circuit?

Thanks,
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

CircuitSetup, 2021-05-08:
Something isn't right with that transformer - I highly doubt the 25kHz is coming from it. Being that high of a frequency is more likely interference from something else. You can't get a high frequency output from a transformer without some additional electronics.

Either way, it doesn't seem like you'll be able to use that transformer. It's either broken or there is something else that I'm missing. I would suggest buying [this one and just taking it out of the case.](https://circuitsetup.us/index.php/product/jameco-ac-to-ac-wall-adapter-transformer-9-volt-1000ma-black-straight-2-5mm-female-plug/). Then you can cut off the plug prongs and wire to a breaker, just like your current one.

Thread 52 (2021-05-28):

No AC adapter available

eavyon, 2021-05-28:
Because of EU regulations I'm told that AC/AC adapters aren't allowed to sell here anymore. That leaves me to using an AC transformer.

Is there any difference between an transformer and a nicely made adapter? Can I safely connect a transformer to the board or do I need to add some protection? What is the minimum current for operating the board without a esp?

I've already ordered 2 sets for solar monitoring so I hope I can get it to work and post results.

CircuitSetup, 2021-05-28:
Any AC to AC adapter is the same as an AC transformer. The point being that you're taking an AC voltage and bringing it down to a much lower level. For the EU, this is usually 220-240V. The transformer needs to bring down the voltage to between 9 and 12VAC.

As long as the transformer you found does this, it should work fine though. It will need to be calibrated to the meter according to the [instructions here.](https://github.com/CircuitSetup/Split-Single-Phase-Energy-Meter#voltage-procedure)

eavyon, 2021-05-28:
I scavenged a normal AD adapter and removed the rectifying part. It's measuring about 14v open circuit. I'll update when I have the set tested and calibrated.

CircuitSetup, 2021-05-30:
Are there still a bunch of capacitors in there? If so, this will not work very well for reading the AC signal, and could be very inaccurate, depending on how much the caps are smoothing the signal. It doesn't sound very safe either. I would recommend just finding a regular AC transformer.

Closed 2021-06-03.

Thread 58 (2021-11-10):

No Power with 3 different Jameco 9V Ac Adapters

luisgarcia87, 2021-11-10:
Hi! I purchased a replacement Single Phase Energy Meter after my previous one stopped working after a blackout, but I was not able to turn it on using the Jameco 9V ac adapter (I have 3 of them). If I plug in a usb cable to the esp32 the pwr led on the single phase energy meter turns on red, but if I use the ac adapter neither the esp32 nor the energy meter turns on. Is it possible that all 3 of my adapters are not working? (2 of them were in use when the blackout happend but I don't know how the third one could be defective as well. If anyone can help I will greatly appreciate it. I already send an email to CircuitSetup as well.

Thank you

CircuitSetup, 2022-03-25:
I'm pretty sure we resolved this via email. Closing.

Closed 2022-03-25.

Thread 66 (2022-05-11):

Alternative way to power the v1.4 board

foureight84, 2022-05-11:
My electrical box is oddly placed externally and there's no outlet nearby to utilize the  Jameco 157041 wall adapter. Is there a safe alternative way to power this board and keep it enclosed in the breaker box? Sort of like the Sense power box that uses an internal breaker as a power source.

CircuitSetup, 2022-05-25:
My apologies for the delay in responding.

The easiest way to do this would be to wire the transformer directly to a breaker in your panel. You can open the transformer case, and replace the plug prongs with wires that go to the breaker. If you've never done anything like this before, I would recommend hiring a professional.

Technically you're not supposed to mix high and low voltage in a panel, so you may want to put the transformer and meter in a separate weatherproof box.

foureight84, 2022-05-29:
Thank you! That is very helpful. I didn't realize the Jameco 157041 could be disassembled.

CircuitSetup, 2022-06-01:
Yep, you just have to break the glue on the seams.

Closed 2022-06-01.

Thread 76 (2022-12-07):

Clarification on ESPHome configuration

wilsongoode, 2022-12-07:
I bought the kit with 2x 200A SCTs in order to monitor the whole house (I'm in the US with split single phase). I have Home Assistant already set up and several other devices configured through ESPHome, so I was hoping to do the same with this kit.

I found the example ESPHome file here: [Software/examples/HA-ESPHome_energy_meter_detailed_power.yaml](https://github.com/CircuitSetup/Split-Single-Phase-Energy-Meter/blob/0e6f9de9c142f66b10108316a899288edd9ceada/Software/examples/HA-ESPHome_energy_meter_detailed_powe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)

Reading through the calibration for the CTs I have become confused as to which values to actually use for `current_cal`, `gain_ct`, and `gain_pga`. The example configuration linked above also contains this text describing a multiplication of the current and power values that is not applied by default:
```
# The max value for current that the meter can output is 65.535. If you expect to measure current over 65A,
# divide the gain_ct by 2 (120A CT) or 4 (200A CT) and multiply the current and power values by 2 or 4 by uncommenting the filter below
#        filters:
#          - multiply: 2
```
Reading through other issues in this repo for information about appropriate configuration I found #64 and #43.

Pull request #72 also relates to 200A CTs.

On the [ESPHome page for the ATM90E32](https://next.esphome.io/components/sensor/atm90e32.html) it recommends:
```
Here are common current calibration values for the Split Single Phase Energy Meter when gain_pga is set to 4X:
- 200A/100mA SCT-024: 12597
```

These various sources seem to conflict, hence my confusion.

At the end of the day I'd like to be able to:
1. Monitor whole-home energy usage in Home Assistant
2. Manage the software wirelessly with ESPHome's dashboard

So far, I have flashed the compiled ESPHome firmware to the device and set it up to connect to my network. I have not installed the CT clamps inside the breaker box.

Is there any risk to moving forward with the hardware install without the software calibration values being set appropriately?
What values should be used for configuring `current_cal`, `gain_ct`, and `gain_pga`?

Please let me know if there is more information I can provide that would make it easier for you to help me. Thanks!

wilsongoode, 2023-05-07:
@CircuitSetup I have installed the system and am reading positive volts and amps for both CTs, but the power factor is negative for both. I installed the CTs following the [directions here](https://github.com/CircuitSetup/Split-Single-Phase-Energy-Meter#connect-current-transformers-to-your-mains) (for one voltage reading). Does this mean the mini-plugs were wired incorrectly?

wilsongoode, 2023-05-07:
Here's what I have so far. I calibrated against a space heater attached to a smart plug that could give me the load in watts and tuned the configuration until things lined up.

I multiplied by -1 (or -4) to flip the sign of the power factor, reactive power, and power readings.

```yaml
substitutions:
# Change the disp_name to something you want
  disp_name: Home Energy Meter
# Interval of how often the power is updated
  update_time: 10s
# Current transformer calibrations:
# 80A/26.6mA SCT-010: 39571
# 100A/50mA SCT-013: 26315
# 120A/40ma SCT-016: 39473 - default kit CT
# 200A/100mA SCT-024: 26315
  # current_cal: '26315'
  # current_cal: '12597'
  current_cal: '13157'
# AC Transformer voltage calibration 9VAC Jameco 157041: 37106
# For Meters >= v1.4 rev3: 3920
  voltage_cal: '3920'

esphome:
  name: energy-meter
  platform: ESP32
  board: nodemcu-32s

wifi:
  ssid: !secret wifi_ssid
  password: !secret wifi_password
  # manual_ip:
  #   static_ip: !secret ip_eh_nrgnode_2chan32
  #   gateway: !secret ip_gateway
  #   subnet: !secret ip_subnet
  #   dns1: !secret ip_dns1

# Enable if you want to send this data to an MQTT broker
# mqtt:
#  broker: !secret mqtt_broker
#  username: !secret mqtt_user
#  password: !secret mqtt_pass

# Enable logging
logger:

# Enable Home Assistant API
api:

ota:

web_server:
  port: 80

spi:
  clk_pin: 18
  miso_pin: 19
  mosi_pin: 23

sensor:
  - platform: wifi_signal
    name: ${disp_name} WiFi Signal
    update_interval: 60s
  - platform: atm90e32
    cs_pin: 5
    phase_a:
      voltage:
        name: ${disp_name} Volts
        accuracy_decimals: 1
        unit_of_measurement: V
        device_class: voltage
      current:
        name: ${disp_name} CT1 Amps
        id: "ct1Amps"
        unit_of_measurement: A
        device_class: current
# The max value for current that the meter can output is 65.535. If you expect to measure current over 65A,
# divide the gain_ct by 2 (120A CT) or 4 (200A CT) and multiply the current and power values by 2 or 4 by uncommenting the filter below
        filters:
         - multiply: 4
      power:
        name: ${disp_name} CT1 Watts
        accuracy_decimals: 1
        id: "ct1Watts"
        unit_of_measurement: W
        device_class: power
        filters: # negative here because CT was reading negative values for power, power factor, etc (but not current)
         - multiply: -4
      reactive_power:
        name: ${disp_name} CT1 Reactive Power
        accuracy_decimals: 1
        id: "ct1Reactive"
        unit_of_measurement: VAR
        device_class: reactive_power
        filters:
         - multiply: -4
      power_factor:
        name: ${disp_name} CT1 Power Factor
        device_class: power_factor
        filters: # added to invert power_factor
          - multiply: -1
      gain_voltage: ${voltage_cal}
      gain_ct: ${current_cal}
    phase_c:
      current:
        name: ${disp_name} CT2 Amps
        id: "ct2Amps"
        unit_of_measurement: A
        device_class: current
# The max value for current that the meter can output is 65.535. If you expect to measure current over 65A,
# divide the gain_ct by 2 (120A CT) or 4 (200A CT) and multiply the current and power values by 2 or 4 by uncommenting the filter below
        filters:
         - multiply: 4
      power:
        name: ${disp_name} CT2 Watts
        accuracy_decimals: 1
        id: "ct2Watts"
        unit_of_measurement: W
        device_class: power
        filters: # negative here because CT was reading negative values for power, power factor, etc (but not current)
         - multiply: -4
      reactive_power:
        name: ${disp_name} CT2 Reactive Power
        accuracy_decimals: 1
        id: "ct2Reactive"
        unit_of_measurement: VAR
        device_class: reactive_power
        filters:
         - multiply: -4
      power_factor:
        name: ${disp_name} CT2 Power Factor
        device_class: power_factor
        filters: # added to invert power_factor
          - multiply: -1
      gain_voltage: ${voltage_cal}
      gain_ct: ${current_cal}
    frequency:
      name: ${disp_name} Freq
      unit_of_measurement: Hz
      device_class: frequency
    chip_temperature:
      name: ${disp_name} Chip Temp
      unit_of_measurement: °C
      device_class: temperature
    line_frequency: 60Hz
    # gain_pga: 4X
    gain_pga: 1X
    update_interval: ${update_time}

  - platform: template
    name: ${disp_name} Total Amps
    id: "totalAmps"
    lambda: return id(ct1Amps).state + id(ct2Amps).state;
    accuracy_decimals: 2
    unit_of_measurement: A
    device_class: current
    update_interval: ${update_time}

  - platform: template
    name: ${disp_name} Total Watts
    id: "totalWatts"
    lambda: return id(ct1Watts).state + id(ct2Watts).state;
    accuracy_decimals: 0
    unit_of_measurement: W
    device_class: power
    update_interval: ${update_time}

  - platform: template
    name: ${disp_name} Total Reactive Power
    id: "totalReactivePower"
    lambda: return id(ct1Reactive).state + id(ct2Reactive).state;
    accuracy_decimals: 0
    unit_of_measurement: VAR
    device_class: reactive_power
    update_interval: ${update_time}

  - platform: total_daily_energy
    name: ${disp_name} Total kWh
    power_id: totalWatts
    filters:
      - multiply: 0.001
    unit_of_measurement: kWh
    device_class: energy
    state_class: total_increasing

time:
  - platform: sntp
    id: sntp_time

switch:
  - platform: restart
    name: ${disp_name} Restart

```

Closed 2023-06-21.

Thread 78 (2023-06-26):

one channel CT channel reading differently

chaseadam, 2023-06-26:
I am using the example ESPhome config and noticed that one CT channel reacted very differently to my large (supposedly) balanced 240V EVSE load. Fhase C reacts, but with much lower absolute reading.

I swapped the CT inputs and I got the similar channel readings which should eliminate the CT or the load as a cause.

I switched in a v1.4 rev3 board and am getting similar magnitude of readings from both channels (but with very off calibration).

Now that I bothered to type all this out, I think my issue might be that I failed to sufficiently sever the burden resistor jumper on CT2 channel because my CTs have built in burden resistors. Will report back after investigation.

MaiaBlanco, 2023-07-06:
I have spent considerable time trying to debug this issue myself and do not have a solution yet. I suspect a software issue may be at play, because I am able to calibrate the CTs I am using to reflect current fairly accurately.

The CTs I am using are 200A/50mA Current Transformer YHDC SCT-024 – 24mm Opening as sold on CircuitSetup's website [here](https://circuitsetup.us/product/200a-50ma-current-transformer-yhdc-sct-024-24mm/?v=7516fd43adaa). Per your concern about burden resistors, I am not aware that these CTs have them (it is not mentioned in the documentation nor on CircuitSetup's storefront). For reference, the current calibration value I ended up computing based on Kill-a-Watt measurements with a resistive load is 49712.

Similar to the original post, I am seeing that one of the phases has a much lower computed Watts reading even though the current scales roughly as expected when I apply a resistive load. I can swap the CT inputs on the meter board and have the same behavior reproduce on the other channel. And I previously swapped the two CTs on the mains lines and _think_ the behavior didn't follow the CT; it seems to follow the phase in the breaker box.

I'm not sure if this is a software problem or perhaps an issue with my installation. OP, please reply back if you discover that burden resistors were the culprit!

CircuitSetup, 2023-07-07:
@chaseadam were you able to resolve this by severing the burden resistor?

@MaiaBlanco can you confirm that the CTs are [installed on your mains like this](https://github.com/CircuitSetup/Split-Single-Phase-Energy-Meter#connect-current-transformers-to-your-mains)?

MaiaBlanco, 2023-07-08:
I confirmed that my current clamps are installed on the mains as shown, yes. The first channel (CT1) is in stalled on the hot line that feeds the same breaker that the voltage monitoring is connected to. The direction (arrow) on the clamp points into the breakers. The second current clamp (CT2) is on the other hot line, pointing opposite to the first.

I think I had a reversed setup before, where the directions of both clamps were reversed from the above, because now I observe negative values reported in the interface for power factor and voltage. Reactive power is being reported as a positive value.

My problem still persists: on the second phase which is monitored by CT2, when I apply a water kettle as a load, the reported wattage is significantly lower than it actually is. For reference, I have checked and recalibrated both clamps individually with a clamp-style multimeter on each hot line, and the reported current values are correct. It's the wattage that is wrong, and only for the CT2 (second phase) channel. The magnitude of the discrepancy is almost 2x: I see an increase of ~512 watts (magnitude, since the values are being reported negative now) through CT2 while I see ~950 watts in the kill-a-watt meter I have on the kettle itself. There are no other loads turning on or off while I run this tests.

CircuitSetup, 2023-07-08:
@MaiaBlanco If you're seeing negative values anywhere that usually means something is reversed. This is going to sound silly, but turn around the voltage transformer in the socket.

I bet you're seeing low wattage values because the meter is calculating power factor out of phase.

If this doesn't fix the issue, please supply your config file.

MaiaBlanco, 2023-07-08:
That makes sense wrt to negative values! Unfortunately, while the wattage values are no longer negative, the second current sensor is still far off on absolute wattage. I also note that while the power factor on the first current meter reaches 1 when I apply a large resistive load (and correctly reports wattage), the second current channel tops out at a power factor of 0.5 and reports roughly half of the wattage it should, as o described earlier.

MaiaBlanco, 2023-07-08:
Here is my config (minus wifi and other ESPhome boilerplate:
`substitutions:
# Change the disp_name to something you want
  disp_name: EMON
# Interval of how often the power is updated
  update_time: 1s

web_server:
  port: 80

spi:
  clk_pin: 18
  miso_pin: 19
  mosi_pin: 23

sensor:
  - platform: wifi_signal
    name: ${disp_name} WiFi Signal
    update_interval: 60s
  - platform: atm90e32
    cs_pin: 5
    current_phases: 2
    phase_a:
      voltage:
        name: ${disp_name} Volts
        accuracy_decimals: 1
      current:
        name: ${disp_name} CT1 Amps
        id: "ct1Amps"
      power:
        name: ${disp_name} CT1 Watts
        accuracy_decimals: 1
        id: "ct1Watts"
        # filters:
# I don't know why but this one is always really off, even though the current measures correctly??
          # - multiply: 1.173
      reactive_power:
        name: "Reactive Power CT1"
        # filters:
        # I don't know why but this one is always really off, even though the current measures correctly??
        #   - multiply: 1.173
      power_factor:
        name: "Power Factor CT1"
        # filters:
        # I don't know why but this one is always really off, even though the current measures correctly??
        #   - multiply: 1.173
# Voltage using a 9VAC power transformer
      gain_voltage: 3920
      gain_ct: 51074
    phase_c:
      current:
        name: ${disp_name} CT2 Amps
        id: "ct2Amps"
      power:
        name: ${disp_name} CT2 Watts
        accuracy_decimals: 1
        id: "ct2Watts"
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
CircuitSetup, 2023-07-09:
> the voltage sensing for channel 2?

Thinking about this some more... what is the output of voltage 2 (phase c in the config) from the meter? If it's reading about the same as voltage 1 (phase a in the config), then the problem can't be with the meter.

MaiaBlanco, 2023-07-09:
I changed my settings to also dump the second voltage channel and it is indeed reading identically to the first. So this likely rules out the meter being defective, in addition to ruling out the current clamps as before.

I have a feeling you may be right; the two phases may not properly be out of phase (180 degrees apart). I’m going to have to figure out a way to measure this.

If I measure the AC voltage between the two hot lines, shouldn’t that give me a sense of their phase? If they are perfectly opposed I should see 120v x 2 peak to peak, and I should see less if the phase angle is anything else.

Also no, I do not observe lights flickering when a large load is applied. But I’ll keep in mind to investigate if anything else is wrong with my supply side.

MaiaBlanco, 2023-07-09:
Okay, I don’t recall if the multimeter will report peak to peak or RMS…probably RMS. In any case, I measure about 120v on each separate phase, and across both I see ~213v. Clearly not adding up.

CircuitSetup, 2023-07-09:
Thanks for checking! That does rule out the meter being defective.

> In any case, I measure about 120v on each separate phase, and across both I see ~213v.

This would make sense if you actually have 2 phases of a 3 phase wye configuration. Each phase is 120V out of phase from eachother. Are you in an apartment or single home?

MaiaBlanco, 2023-07-09:
It’s been a hot minute since EE coursework, but I think that I should be able to compute the relative phase offset of the two hot phases by using the RMS measurements I posted above.
`
123v+cos(theta) + 123v = 213.5v
1+cos(theta) = 1.73577
cos(theta) = 1.73577
theta = cos^-1(0.73577)
theta = 42.6 degrees (or 0.744 radians)
`

MaiaBlanco, 2023-07-09:
I am in an apartment, so maybe I am getting 2 of three phases. Did I measure something incorrectly or do the wrong math above?

MaiaBlanco, 2023-07-09:
So, how should the meter be configured when a home is getting 2 of three phases? Is a second voltage reading required or is there a configuration I can change?

CircuitSetup, 2023-07-10:
> I am in an apartment, so maybe I am getting 2 of three phases. Did I measure something incorrectly or do the wrong math above?
>
> Edit: well a quick google search confirms that it’s probably three phase power and that I should be seeing approximately 1.73x the voltage across two phases versus measuring on one. Time to study back up…

Yep! That makes sense!
> So, how should the meter be configured when a home is getting 2 of three phases? Is a second voltage reading required or is there a configuration I can change?

There are 2 solutions here:
1.  Use a 2nd voltage transformer to measure the 2nd phase & cut the voltage jumpers on the back of the meter
2.  In the config, calculate the watts using lambda, using the voltage and PF from phase 1 (this will be slightly less accurate, but still very close to actual):
Make sure to give voltage and power factor an id:
`      voltage:
        name: ${disp_name} Volts
        id: "p1Volts"
        accuracy_decimals: 1
        unit_of_measurement: V
        device_class: voltage
`
`      power_factor:
        name: ${disp_name} CT1 Power Factor
        id: "ct1PF"
        device_class: power_factor
`

Then the template to calculate everything:

`  - platform: template
    name: ${disp_name} CT2 Watts
    id: ct2Watts
    lambda: return (id(ct2Amps).state * id(p1Volts).state) * id(ct1PF).state;
    accuracy_decimals: 0
    unit_of_measurement: W
    device_class: power
    update_interval: ${update_time}
`

MaiaBlanco, 2023-07-12:
Thanks for all your help debugging! I hope the original poster was able to resolve the initial issue. I will add a second voltage transformer to my setup and see how that goes.

chaseadam, 2023-07-12:
To close the loop for my original issue: I had scraped the jumper off, but I guess not well enough. It tested as shorted, so I re-scraped it and removed the burden resistor. Everything is back to normal for me.

@MaiaBlanco I appreciate the discussion as being related. Glad you got to the conclusion of the phase shift being the issue. I may consider another voltage transformer as well for more accuracy even though I have split phase.
@CircuitSetup as always, thanks for chiming in with the great detailed guidance.

Preview for the next issue: Debugging ESPHome on an ESP32C3-mini dev board that is locking up a few times per day at exactly 26 minutes and 21-28 seconds past the hour...

Closed 2023-07-12.

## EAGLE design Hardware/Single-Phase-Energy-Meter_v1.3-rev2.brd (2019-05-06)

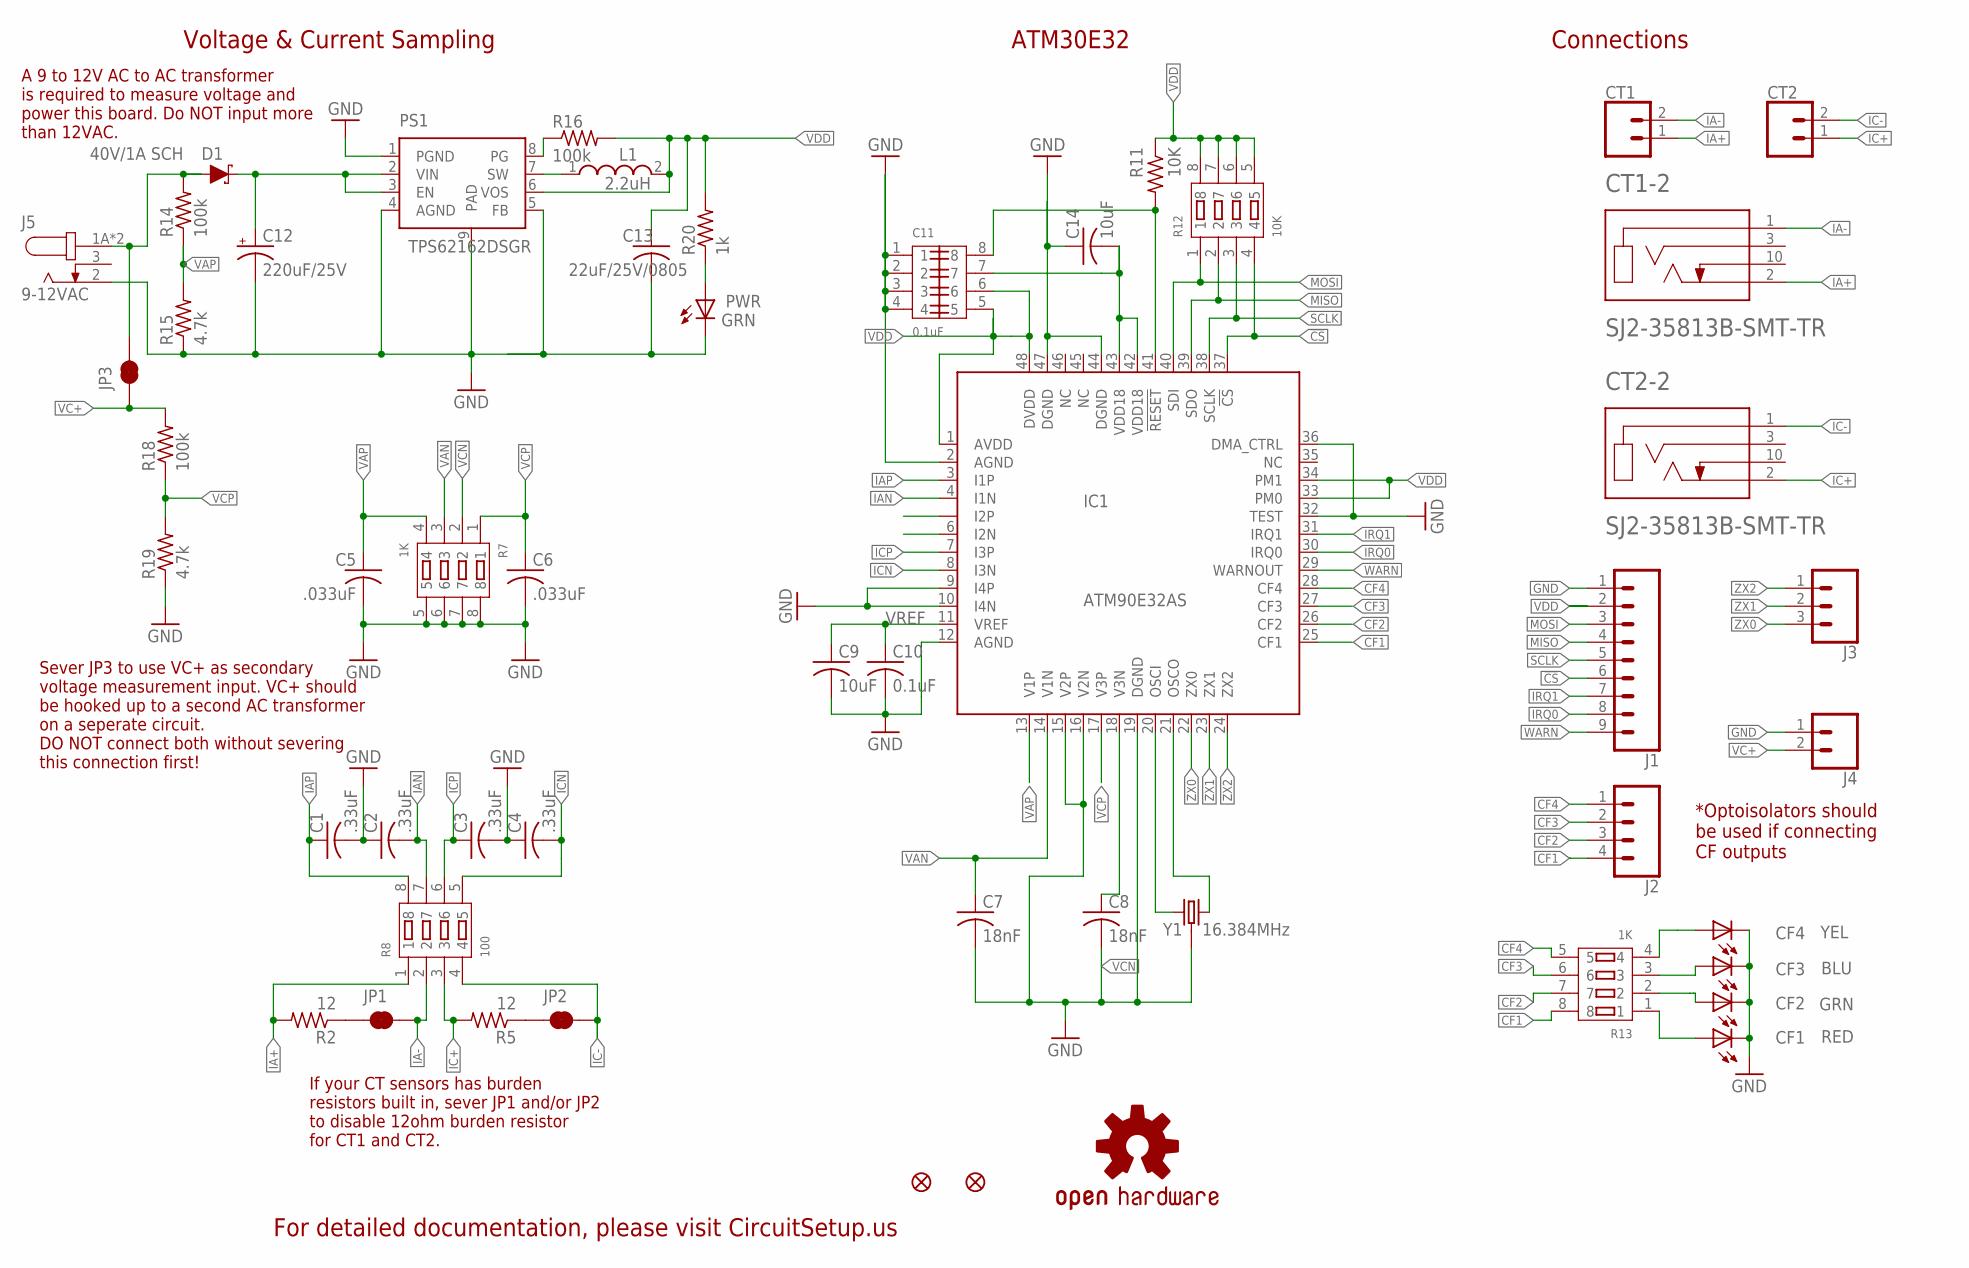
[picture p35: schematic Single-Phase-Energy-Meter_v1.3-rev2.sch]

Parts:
C1, C2, C3, C4: .33uF; C0603
C5, C6: .033uF; C0603
C7, C8: 18nF; C0603
C9, C14: 10uF; C0603
C10: 0.1uF; C0603
C11: 0.1uF; CAPCAF80P320X160X70-8
C12: 220uF/25V; 153CLV-0605
C13: 22uF/25V/0805; C0805
CF1: RED; CHIP-LED0603
CF2: GRN; CHIP-LED0603
CF3: BLU; CHIP-LED0603
CF4: YEL; CHIP-LED0603
CT1, CT2: CONN_023.5MM; SCREWTERMINAL-3.5MM-2
CT1-2, CT2-2: SJ2-35813B-SMT-TR; CUI_SJ2-35813B-SMT-TR
D1: 40V/1A SCH; SMA-DIODE
FD1, FD2: FIDUCIALUFIDUCIAL; FIDUCIAL-MICRO
IC1: ATM90E32AS; QFP50P900X900X120-48N
J1: CONN_09; 1X09
J2: CONN_04; 1X04
J3: CONN_03; 1X03
J4: CONN_02; 1X02
J5: 9-12VAC; CUI_PJ-002AH-SMT-TR
JP1, JP2, JP3: JUMPER-SMT_2_NC_TRACE_SILK; SMT-JUMPER_2_NC_TRACE_SILK
L1: 2.2uH; INDPM4042X200N
LOGO1: OSHW-LOGOS; OSHW-LOGO-S
PS1: TPS62162DSGR; SON50P200X200X80-9N
PWR: GRN; CHIP-LED0603
R2, R5: 12; R0603
R7, R13: 1K; RA1206-8
R8: 100; RA1206-8
R11: 10K; R0603
R12: 10K; RA1206-8
R14, R16, R18: 100k; R0603
R15, R19: 4.7k; R0603
R20: 1k; R0603
Y1: 16.384MHz; CRYSTAL-SMD-3.2X2.5MM

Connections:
!CS: IC1.37 (!CS), J1.6, R12.4
!RESET: C11.8, IC1.41 (!RESET), R11.2
CF1: IC1.25 (CF1), J2.4, R13.8
CF2: IC1.26 (CF2), J2.3, R13.7
CF3: IC1.27 (CF3), J2.2, R13.6
CF4: IC1.28 (CF4), J2.1, R13.5
GND: C1.2, C2.1, C3.2, C4.1, C5.2, C6.2, C7.2, C8.2, C9.2, C10.2, C11.1, C11.2, C11.3, C11.4, C12.-, C13.2, C14.1, CF1.C, CF2.C, CF3.C, CF4.C, IC1.2 (AGND), IC1.9 (I4P), IC1.10 (I4N), IC1.12 (AGND), IC1.15 (V2P), IC1.16 (V2N), IC1.19 (DGND), IC1.32 (TEST), IC1.36 (DMA_CTRL), IC1.44 (DGND), IC1.47 (DGND), J1.1, J4.1, J5.2, PS1.1 (PGND), PS1.4 (AGND), PS1.5 (FB), PS1.9 (PAD), PWR.C, R7.5, R7.6, R7.7, R7.8, R15.1, R19.1, Y1.2 (3), Y1.4 (3)
IA+: CT1.1, CT1-2.2 (TIP), R2.2, R8.1
IA-: CT1.2, CT1-2.1 (SLEEVE), JP1.2, R8.2
IAN: C2.2, IC1.4 (I1N), R8.7
IAP: C1.1, IC1.3 (I1P), R8.8
IC+: CT2.1, CT2-2.2 (TIP), R5.2, R8.3
IC-: CT2.2, CT2-2.1 (SLEEVE), JP2.2, R8.4
ICN: C4.2, IC1.8 (I3N), R8.5
ICP: C3.1, IC1.7 (I3P), R8.6
IRQ0: IC1.30 (IRQ0), J1.8
IRQ1: IC1.31 (IRQ1), J1.7
MISO: IC1.39 (SDO), J1.4, R12.2
MOSI: IC1.40 (SDI), J1.3, R12.1
unnamed: JP1.1, R2.1
unnamed: JP2.1, R5.1
unnamed: CF4.A, R13.4
unnamed: CF3.A, R13.3
unnamed: CF2.A, R13.2
unnamed: CF1.A, R13.1
unnamed: L1.1, PS1.7 (SW)
unnamed: PS1.8 (PG), R16.1
unnamed: PWR.A, R20.1
OSCI: IC1.20 (OSCI), Y1.1
OSCO: IC1.21 (OSCO), Y1.3 (2)
SCLK: IC1.38 (SCLK), J1.5, R12.3
VA+: D1.A, J5.1A (1), J5.1B (1), JP3.2, R14.2
VAN: C7.1, IC1.14 (V1N), R7.3
VAP: C5.1, IC1.13 (V1P), R7.4, R14.1, R15.2
VC+: J4.2, JP3.1, R18.2
VCN: C8.1, IC1.18 (V3N), R7.2
VCP: C6.1, IC1.17 (V3P), R7.1, R18.1, R19.2
VDD: C11.5, C11.6, C13.1, IC1.1 (AVDD), IC1.33 (PM0), IC1.34 (PM1), IC1.48 (DVDD), J1.2, L1.2, PS1.6 (VOS), R11.1, R12.5, R12.6, R12.7, R12.8, R16.2, R20.2
VDD18: C11.7, C14.2, IC1.42 (VDD18), IC1.43 (VDD18)
VIN1: C12.+, D1.C, PS1.2 (VIN), PS1.3 (EN)
VREF: C9.1, C10.1, IC1.11 (VREF)
WARN: IC1.29 (WARNOUT), J1.9
ZX0: IC1.22 (ZX0), J3.3
ZX1: IC1.23 (ZX1), J3.2
ZX2: IC1.24 (ZX2), J3.1

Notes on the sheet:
ATM30E32
Voltage & Current Sampling
Connections
*Optoisolators should be used if connecting CF outputs
If your CT sensors has burden resistors built in, sever JP1 and/or JP2 to disable 12ohm burden resistor for CT1 and CT2.
Sever JP3 to use VC+ as secondary voltage measurement input. VC+ should be hooked up to a second AC transformer on a seperate circuit. DO NOT connect both without severing this connection first!
A 9 to 12V AC to AC transformer is required to measure voltage and power this board. Do NOT input more than 12VAC.
For detailed documentation, please visit CircuitSetup.us

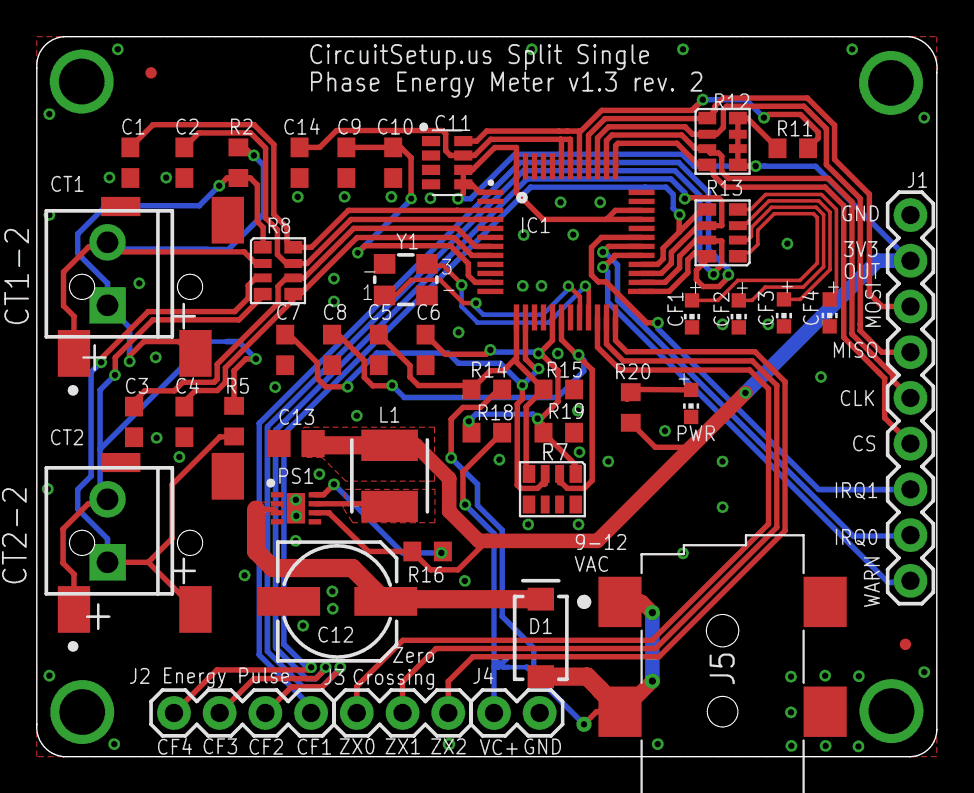
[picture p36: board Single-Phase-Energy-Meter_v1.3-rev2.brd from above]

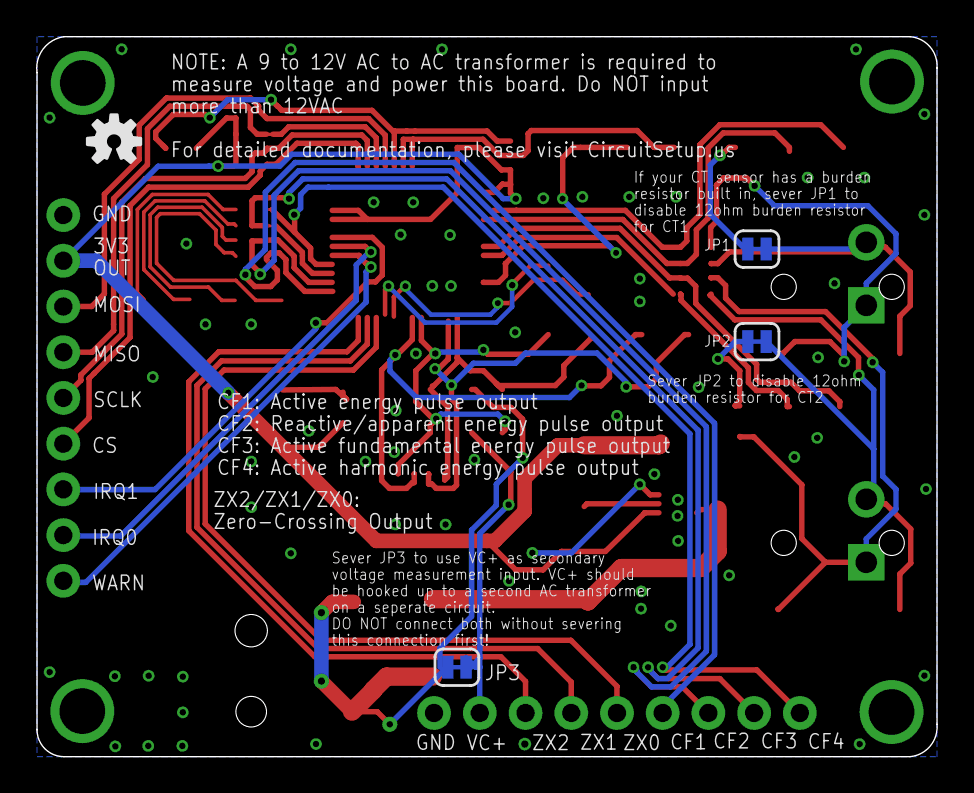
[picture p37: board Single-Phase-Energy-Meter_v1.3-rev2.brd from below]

Board: 2 copper layers, 50.0 x 40.0 mm, 52 parts (4 on the bottom side), 45 nets.

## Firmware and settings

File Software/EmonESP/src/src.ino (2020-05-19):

/*
   -------------------------------------------------------------------
   EmonESP Serial to Emoncms gateway
   -------------------------------------------------------------------
   Adaptation of Chris Howells OpenEVSE ESP Wifi
   by Trystan Lea, Glyn Hudson, OpenEnergyMonitor

   Modified to use with the CircuitSetup.us Split Phase Energy Meter by jdeglavina

   All adaptation GNU General Public License as below.

   -------------------------------------------------------------------

   This file is part of OpenEnergyMonitor.org project.
   EmonESP is free software; you can redistribute it and/or modify
   it under the terms of the GNU General Public License as published by
   the Free Software Foundation; either version 3, or (at your option)
   any later version.
   EmonESP is distributed in the hope that it will be useful,
   but WITHOUT ANY WARRANTY; without even the implied warranty of
   MERCHANTABILITY or FITNESS FOR A PARTICULAR PURPOSE.  See the
   GNU General Public License for more details.
   You should have received a copy of the GNU General Public License
   along with EmonESP; see the file COPYING.  If not, write to the
   Free Software Foundation, Inc., 59 Temple Place - Suite 330,
   Boston, MA 02111-1307, USA.
*/

// See energy meter specific configuration in energy_meter.h
#define ENABLE_ENERGY_METER

// If USE_SERIAL_INPUT is defined, EmonESP will check the serial port for
// input. Only enable this if there is input expected on the serial port;
// otherwise it seems to read garbage data.
//#define USE_SERIAL_INPUT

#include <esp_task_wdt.h>
#include "emonesp.h"
#include "config.h"
#include "wifi.h"
#include "web_server.h"
#include "ota.h"
#include "input.h"
#include "emoncms.h"
#include "mqtt.h"

#ifdef ENABLE_ENERGY_METER
#include "energy_meter.h"
#endif

static char input[MAX_DATA_LEN];

// -------------------------------------------------------------------
// SETUP
// -------------------------------------------------------------------
void setup() {

#ifdef ENABLE_WDT
  enableLoopWDT();
#endif

  Serial.begin(115200);
#ifdef DEBUG_SERIAL1
  Serial1.begin(115200);
#endif
  delay(1000);

  // Read saved settings from the config
  config_load_settings();
  delay(500);

  // Initialise the WiFi
  wifi_setup();
  delay(500);

  // Bring up the web server
  web_server_setup();
  delay(500);
  
  if (mqtt_server != 0) {
    mqtt_setup();
  }

#ifdef ENABLE_WDT
  DBUGS.println("Watchdog timer is enabled.");
  feedLoopWDT();
#endif

#ifdef ESP8266
  // Start the OTA update systems
  ota_setup();
#endif

#ifdef ENABLE_ENERGY_METER
  energy_meter_setup();
#endif

  DBUGS.println("Server started");

} // end setup

// -------------------------------------------------------------------
// LOOP
// -------------------------------------------------------------------
void loop()
{
#ifdef ENABLE_WDT
  feedLoopWDT();
#endif

  web_server_loop();
  wifi_loop();

#ifdef ESP8266
  ota_loop();
#endif

#ifdef ENABLE_ENERGY_METER
  energy_meter_loop();
#endif

  boolean gotInput = input_get(input);
  if (gotInput) {
    DBUGS.println(".");
  }

  if (wifi_client_connected()) {
    if (emoncms_apikey != 0 && gotInput) {
      DBUGS.println(input);
      emoncms_publish(input);
    }
    if (mqtt_server != 0) {
      mqtt_loop();
      if (gotInput && mqtt_connected()) {
        mqtt_publish(input);
      }
    }
  }

} // end loop

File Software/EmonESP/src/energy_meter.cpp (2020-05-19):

/*
   -------------------------------------------------------------------
   EmonESP Serial to Emoncms gateway
   -------------------------------------------------------------------
   Created for use with the CircuitSetup.us Split Phase Energy Meter by jdeglavina

   All adaptation GNU General Public License as below.

   -------------------------------------------------------------------

   This file is part of OpenEnergyMonitor.org project.
   EmonESP is free software; you can redistribute it and/or modify
   it under the terms of the GNU General Public License as published by
   the Free Software Foundation; either version 3, or (at your option)
   any later version.
   EmonESP is distributed in the hope that it will be useful,
   but WITHOUT ANY WARRANTY; without even the implied warranty of
   MERCHANTABILITY or FITNESS FOR A PARTICULAR PURPOSE.  See the
   GNU General Public License for more details.
   You should have received a copy of the GNU General Public License
   along with EmonESP; see the file COPYING.  If not, write to the
   Free Software Foundation, Inc., 59 Temple Place - Suite 330,
   Boston, MA 02111-1307, USA.
*/

#include "energy_meter.h"
#include "emonesp.h"
#include "emoncms.h"
#include "input.h"
#include "config.h"

// for ATM90E32 energy meter
#include <SPI.h>
#include <ATM90E32.h>

#ifdef ENABLE_OLED_DISPLAY
#include <Adafruit_GFX.h>
#include <Adafruit_SSD1306.h>
#define SCREEN_WIDTH 128 // OLED display width, in pixels
#define SCREEN_HEIGHT 64 // OLED display height, in pixels

// Declaration for SSD1306 display connected using software SPI (default case):
#define OLED_DC     0
#define OLED_CS     16
#define OLED_RESET  17
Adafruit_SSD1306 display(SCREEN_WIDTH, SCREEN_HEIGHT, &SPI, OLED_DC, OLED_RESET, OLED_CS);
#endif

/***** CALIBRATION SETTINGS *****/
/* These values are edited in the web interface or energy_meter.h */
/* Values in the web interface take priority */
unsigned short VoltageGain = VOLTAGE_GAIN;
unsigned short CurrentGainCT1 = CURRENT_GAIN_CT1;
unsigned short CurrentGainCT2 = CURRENT_GAIN_CT2;
unsigned short LineFreq = LINE_FREQ;
unsigned short PGAGain = PGA_GAIN;
#ifdef SOLAR_METER
unsigned short VoltageGainSolar = VOLTAGE_GAIN_SOLAR;
unsigned short SolarGainCT1 = SOLAR_GAIN_CT1;
unsigned short SolarGainCT2 = SOLAR_GAIN_CT2;
#endif

#if defined ESP8266
const int CS_pin = 16;
/*
  D5/14 - CLK
  D6/12 - MISO
  D7/13 - MOSI
*/
#elif defined ESP32
const int CS_pin = 5;
#ifdef SOLAR_METER
const int CS_solar_pin = 4;
#endif
/*
  18 - CLK
  19 - MISO
  23 - MOSI
*/

#elif defined ARDUINO_ESP8266_WEMOS_D1MINI  // WeMos mini and D1 R2
const int CS_pin = D8; // WEMOS SS pin

#elif defined ARDUINO_ESP8266_ESP12  // Adafruit Huzzah
const int CS_pin = 15; // HUZZAH SS pins ( 0 or 15)

#elif defined ARDUINO_ARCH_SAMD || defined __AVR_ATmega32U4__ //M0 board || 32u4 SS pin
const int CS_pin = 10;

#else
const int CS_pin = SS; // Use default SS pin for unknown Arduino
#endif

unsigned long startMillis;
unsigned long currentMillis;

const int period = 1000; //time interval in ms to send data
/*Power values are usually only negative when exporting solar power
  Otherwise a CT may be backwards */
bool canBeNegative = true; 

char measurement[16];

ATM90E32 eic{}; //initialize the IC class
#ifdef SOLAR_METER
ATM90E32 eic_solar {};
#endif

// -------------------------------------------------------------------
// SETUP
// -------------------------------------------------------------------
void energy_meter_setup() {

  /*Get values from web interface and assign them if populated*/
  if (voltage_cal.toInt() > 0) VoltageGain = voltage_cal.toInt();
  if (ct1_cal.toInt() > 0) CurrentGainCT1 = ct1_cal.toInt();
  if (ct2_cal.toInt() > 0) CurrentGainCT2 = ct2_cal.toInt();
  if (freq_cal.toInt() > 0) LineFreq = freq_cal.toInt();
  if (gain_cal.toInt() > 0) PGAGain = gain_cal.toInt();

  /*Initialise the ATM90E32 & Pass CS pin and calibrations to its library -
    the 2nd (B) current channel is not used with the split phase meter */
  Serial.println("Start ATM90E32");
  eic.begin(CS_pin, LineFreq, PGAGain, VoltageGain, CurrentGainCT1, 0, CurrentGainCT2);
  delay(1000);

#ifdef SOLAR_METER
  if (svoltage_cal.toInt() > 0) VoltageGainSolar = svoltage_cal.toInt();
  if (sct1_cal.toInt() > 0) SolarGainCT1 = sct1_cal.toInt();
  if (sct2_cal.toInt() > 0) SolarGainCT2 = sct2_cal.toInt();

  eic_solar.begin(CS_solar_pin, LineFreq, PGAGain, VoltageGainSolar, SolarGainCT1, 0, SolarGainCT2);
#endif

#ifdef ENABLE_OLED_DISPLAY
  // SSD1306_SWITCHCAPVCC = generate display voltage from 3.3V internally
  if (!display.begin(SSD1306_SWITCHCAPVCC)) {
    Serial.println(F("OLED allocation failed"));
  }

  display.clearDisplay();
  display.setTextSize(2);
  display.setTextColor(WHITE);
  display.setCursor(0, 0);
  display.println("Starting up...");
  display.display();
#endif

  startMillis = millis();  //initial start time

} // end setup
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

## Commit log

2019-05-07 added schematic and data sheets
2019-05-14 Updated the ATM90E32 library significantly
    - Replaced lineGain with much more useful PGAGain, which increases the gain on current channels. Useful if using smaller CTs (1x) or larger CTs, like 200A (4x). The default is 2x
    - Added config variable for line frequency. This allows the frequency setting to be switched in the front end software. Default is 60hz.
    - Fixed GetActivePower, GetApparentPower, GetPowerFactor - all of these were not taking into account the lower 16 bit register, and were not outputting the correct numbers
    - Fixed GetPowerFactor - the registers for power factor sometimes goes out of bounds for unknown reasons. Corrected this by doing a check on the output, and outputting 0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
2019-05-14 added wire diameter chart
2019-05-24 v1.4 meter layout & solar adapter pcb
    Tweaks in v1.4:
    - changed to higher output TI SMPS
    - added C16 & C17 caps to help with filtering
    - moved bypass caps closer to the IC
    Solar adapter:
    - allows 2 energy meters to be used
    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
2019-05-24 Bug fixes for meter functions
    - Cleaned up code
    - Fixed issue with meter functions that are 32 bit total reporting negative numbers and going out of bounds
    - Fixed power factor
    - Fixed error in PLconstL register
    - Added a single function for reading combined 16 bit registers
    - Added functions for calculating voltage & current offset and gain (these aren't terribly useful yet)
2019-05-25 Organized the energy meter specific code
    * Split out the energy_meter specific code into its own module
    * Added flag to enable or disable the energy_meter specific code
    * Added detection for Net Energy +/-
    * Fixed "Latest Data" pane on web UI
    [energy_meter.cpp, energy_meter.h, src.ino]
2019-05-27 updates to calibration
2019-05-30 fixed on board LED variable
    [energy_meter.cpp, src.ino]
2019-06-03 fixed totalWatts calcu & added default calibration val for SCT-016 CTs
    [ATM90E32_Basic_SPI.ino, ATM90E32_MQTT.ino, energy_meter.cpp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]
2019-06-12 binaries for esp32
2019-06-12 cleaned up a little & added new default voltage calibrations
2019-06-14 updated v1.4 of pcb
    Changes from v1.3:
    - Changed SMPS from TI TPS62162 to TPS32142, which can output more power. This will help with power hungry MCU's
    - Added 10uf cap, C15 before SMPS
    - Added C17 as part of SMPS requirement
    - Added 10uf cap C16 for additional noise filtering on IC1 DGND pin
    - Moved filtering caps closer to IC1
    - Rearranged voltage resisotors a bit so caps could be closer to IC1
    - Changed R15 & R19 from 4.7k to 10k. This gives more room for European users that need to calibrate voltage up to 220-240V.
    - Minimized ground planes
    - Added castellated holes for easy mounting to kit pcb adapter
    - Added OSHW logo with ID
    [Single-Phase-Energy-Meter_v1.4-rev1.brd, Single-Phase-Energy-Meter_v1.4-rev1.sch]
2019-06-14 solar box files
    [energy_meter_solar_box_case.stl, energy_meter_solar_box_lid.stl]
2019-06-14 Update circuitsetup_split-phase.json
    removed redundant active power
2019-06-17 Updated offset register values & other improvements
    - Tuned offset register values which will make metering values more accurate
    - Calibrated phase angle for more accurate small current values
    - Removed calculation that would not allow some metering values to ever be negative
    - Added switch to allow or not allow for negative values (default is no negative values)
    - Accomodated for case where one active power reading would be negative because it would be out of phase with the other with only 1 voltage reading.
    - Removed redundant front end total watts calculation
2019-06-18 updated for 9v AC Jameco 157041
    ... this model will come with the kits
    [energy_meter.cpp, energy_meter.h]
2019-06-28 Added ability to set calibration values in web interface
    - Added calibration values to web interface
    - Fixed firmware upload via web interface (and made messages more descriptive)
    - added SPIFFS detection in firmware upload so this bin is uploaded to correct part of memory
    - changed dependency on OTA library (now Update.h) for ESP32 - the one being used was depricated
    - set hostname correctly for ESP32
    - captive portal redirect disable when not in AP mode (otherwise this spews a bunch of wifiudp.h errors)
    - Changed meter output designations to be consistent (and make more sense)
    [energy_meter.cpp, web_server.cpp]
2019-06-28 Moved calibration parameters from constructor to ::begin
    - calibration parameters were moved from constructor to begin so values can be gathered from web interface if present. This can't be done before the main function otherwise.
    - Added destructor
2019-07-03 Lots of updates to how wifi functions
    -Redid how wifi reconnects if client connection is lost, changs to AP mode, then retries to connect again
    - Added ability to go into AP mode or reset everything by holding down an assigned button
    [energy_meter.cpp, energy_meter.h]
2019-07-16 Updated behavior of ESP led
    - Added LED on time so it's more of a flash
    - Added STA_CONNECTED_TIME for time interval when connected to wifi.
    - if AP mode & disconnected - blink every 2 seconds
    - if AP mode & someone is connected - blink fast
    - if Client mode - slow blink every 4 seconds
2019-07-19 Fixed DNS captive portal when ESP is in AP mode
    - compiled bin with latest ESP32 IDF
    - disabled OTA for esp32, not really needed anyway since the web interface can update firmware
    [src.ino, web_server.cpp, wifi.cpp]
2019-07-25 Added error checking to admin and calibration fields
2019-07-25 Updates to the way reconnection to WiFi is made
    - Now restarts WiFi to reconnect after losing connection (after set time) instead of restarting ESP
    - Retries after losing connection 3 times in 5 second intervals before going into AP mode
    - AP mode reduced to 2 min before tring to reconnect to configured WiFi
    - Added delays between certain WiFi calls
    - Compiled binary done with Arduino core v1.0.2, 80mhz clock speed, and latest updates to EEPROM that uses NVS
2019-07-26 Hidden password and API fields
    - Password and API fields are now now password form fields. If they are populated a dummy password is returned on the EmonESP GUI
    - Added option to prevent ESP from going into SoftAP mode if connection to main wifi is lost. ESP will continue to try to reconnect to main wifi if configured.
    - Increased default interval for trying to reconnect to wifi directly after losing connection to 10 seconds 3 times - from SoftAP mode to 5 min.
    - Added variable in wifi.h WIFI_CLIENT_DISCONNECT_RETRY (set for 10 seconds)
    [web_server.cpp, wifi.cpp, wifi.h]
2019-08-01 Added no AP firmware...
    Normally when the connection to the main wifi AP is lost, the software goes into AP mode so it can be reconfigured if needed. This is turned off, and will keep trying to reconnect to the wifi AP that it is configured for. This is done because with some configurations going into AP mode crashes the ESP32, and it will not come back up unless manually reset.
    For this version the only way to change the AP is to ground GPIO 3 for 5 seconds to put the ESP32 into AP mode.
2019-08-25 Compiled with latest esp32-arduino 1.0.3 rc2
    - Cleaned up spacing and formatting
    - Set WiFi.disconnect to not disable esp32 wifi when called
2019-08-27 Fix for reading 240v properly
    [energy_meter.cpp, web_server.cpp]
2019-08-29 Update readme.md
    added Arduino suggested options pic for ESP32
2019-09-06 Create HA-ESPHome_energy_meter.yaml
    -example config file for Home Assistant with ESP32 running ESPHome
2019-09-11 Updated solar EmonESP to match regular build
    - added addition calibration fields for solar in web interface
2019-09-11 pics of assembled pcbs and kits
2019-09-25 added esp32
2019-09-27 v2.5.3 - Fixed crashing
    - Firmware files Compiled with Arduino core 1.0.3
    - fixed crashing when browser is left open
    - fixed memory leak when a browser session isn't closed properly, which would result in a crash (updated AsyncTCP, and ESPAsyncWebServer)
    - disabled captive portal, which was causing crashes related to heap, and sessions in the SoftAP
    - moved some includes to .h files for better consistency
    [web_server.cpp, wifi.cpp, wifi.h]
2019-09-27 SPIFFS.h included only for ESP32
2019-10-03 Update circuitsetup_split-phase.json
    cleaned up formatting
    added frequency
2019-10-03 Update circuitsetup-split-phase_solar.xml
    changed power field names so they are auto-detected
2019-10-08 added hash arduino library
2019-11-08 Fixed total current calculation for solar
    [energy_meter.cpp]
2019-11-08 compiled with Arduino core v1.0.4
2019-11-21 Fixed power factor & other small tweaks
    - Fixed power factor calculation
    - added SagPeakDetCfg, Sag and Voltage peak detect period and set to 20ms
    - adjusted power startup valuesto be more consistent
    - removed calibrationError since there is no checksum on the 32 (there is on the 36)
    - register numbers in comments
    - Corrected F register names - these are different on the 32 and are voltage & current peaks. On the 36 they are THD, which the 36 doesn't have.
2019-12-03 add comment for voltage calibration
    v1.4 purchased after 11/1/2019 and rev.3 use a different voltage divider and will have a lower calibration value for voltage - for example 7611 - 9v AC Transformer - Jameco 157041
    [ATM90E32_MQTT.ino]
2019-12-03 Update ATM90E32_Basic_SPI.ino
    * For Meters > v1.4 purchased after 11/1/2019 and rev.3
    * 7611 - 9v AC Transformer - Jameco 157041
    [ATM90E32_Basic_SPI.ino]
2019-12-03 Update Home_Assistant_MQTT.ino
    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
    [Home_Assistant_MQTT.ino]
2019-12-03 Update sensor.yaml
    removed redundant total watts
2019-12-03 v2.5.5 - fixes power factor calculation
    - ATM90E32 library fixed to calculate power factor correctly.
    - Upped version to v2.5.5
    - removed canBeNegative for regular meter so its easy to tell when a current transformer is backwards. If one is backwards, real power calculations will be off because power factor will be off.
    [energy_meter.cpp, energy_meter.h, web_server.cpp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]
2020-02-21 MQTT Fixes & cleanup
    - Add RSSI value to MQTT #22 - thanks @fredkehler!
    - Fix for MQTT reconnect - was set to 50000ms (14 min) for reconnect instead of 5000ms (5 seconds). This was blocking everything else if MQTT disconnected, potentially causing freezing. Now it will try to reconnect continously for 5 seconds, then every 10 seconds.
    - Moved some includes to .h files for consistency
    - Fixed some typos in web interface
    - Added default voltage calibration value for meter v1.4 rev3. (it is much lower because of lower value resistors for voltage divider (20k and 10k).
    [energy_meter.cpp, energy_meter.h]
2020-02-26 added note for measuring current over 65A
2020-02-26 added calibrations for different CTs
2020-05-19 Replaced MQTT lib with async, watchdog enabled, WifiClient
    - MQTT now uses async-mqtt-client to prevent MQTT from blocking
    - The esp32 watchdog is now enabled
    - A lot of String variables changed to char
    - HTTPClient changed to properly use WifiClient lib
    [energy_meter.cpp]
2020-07-02 Update README.md
    added better instructions for adding a second voltage measurement
2020-08-24 Update ATM90E32.cpp
    updated SPI mode to mode1 for esp8266 devices
2021-05-04 Update circuitsetup-6_channel_solar.json
    fix use calculation - change import to house_import under Total Solar Power
2021-05-04 Update circuitsetup-6_channel_solar.json
    removed extra voltage input
    added power factor inputs/feeds
2021-05-04 Update circuitsetup-6_channel_solar.json
    use calculation correction (again)
2022-02-04 Update HA-ESPHome_energy_meter_detailed_power.yaml
    added device_class: energy, state_class: total_increasing to properly work in the latest Home Assistant
2022-02-04 Update HA-ESPHome_energy_meter_detailed_power.yaml
    added power factor and device classes
2022-06-23 Fix compile errors, add ability to disable WiFi/MQTT for calibration, add auto-reboot on number of failures so sensor auto-reconnects after server reboot, update sensor.yaml example to play nicely wi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
    [Home_Assistant_MQTT.ino]
2022-06-23 Add in a current multiplier feature for 200A clamps that need to use 1X gain and would like larger range. Adjust total wattage returned to be apparent power instead of real power as this is what most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

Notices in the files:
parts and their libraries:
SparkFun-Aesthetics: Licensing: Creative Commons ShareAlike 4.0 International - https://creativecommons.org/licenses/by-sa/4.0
